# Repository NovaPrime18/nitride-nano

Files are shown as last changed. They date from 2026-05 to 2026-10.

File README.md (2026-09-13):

# nitride-nano

**Pocket-sized GaN buck/boost converter with USB-C PD input**




<table><tr>
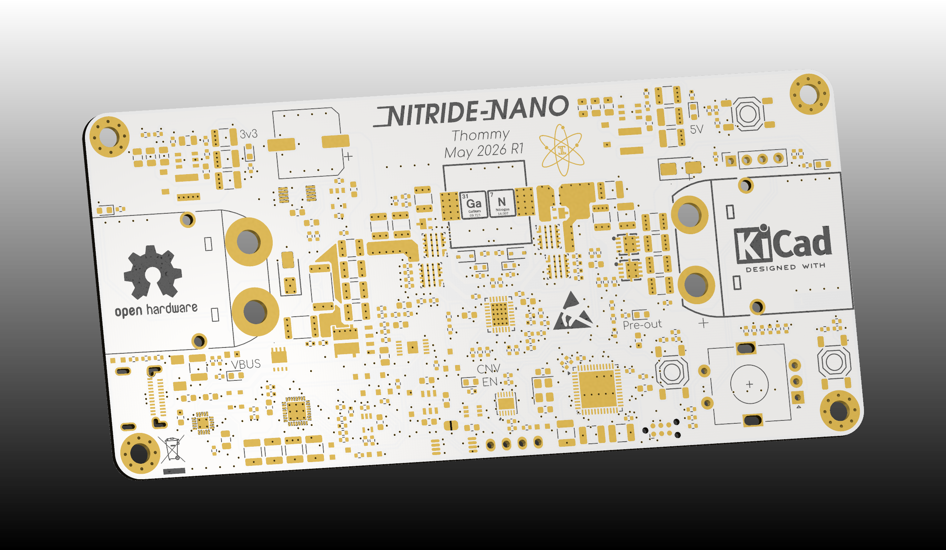
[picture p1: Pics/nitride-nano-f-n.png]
<td></td>
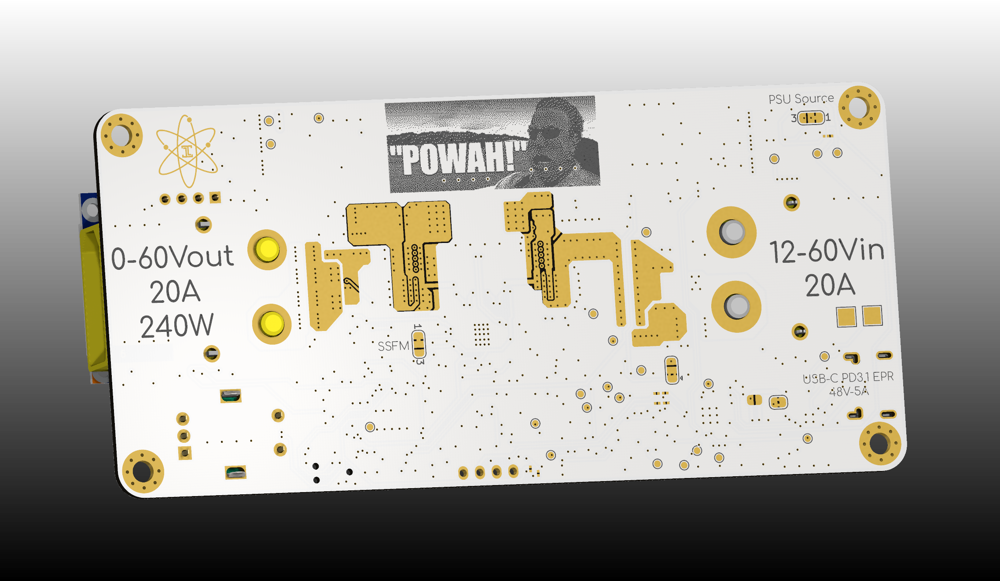
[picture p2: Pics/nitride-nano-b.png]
<td></td>
</tr></table>
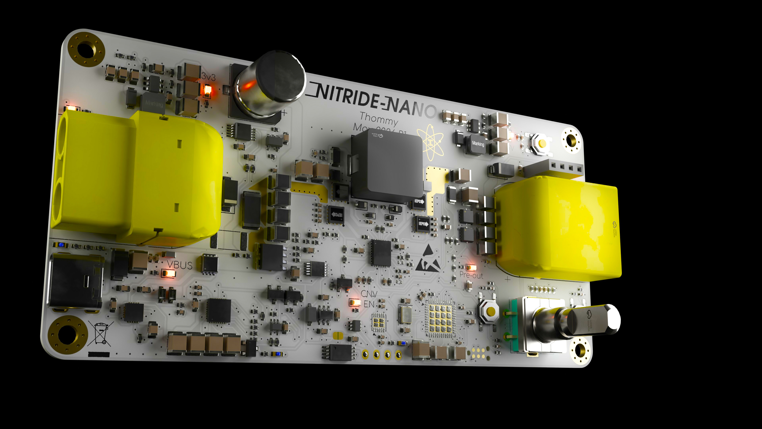
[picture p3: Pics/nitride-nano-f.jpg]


---

## Overview

Nitride-nano is an open-source, high-power-density buck/boost converter crammed into the smallest footprint possible. It targets the same use case as the [Miniware MDP-XP](https://www.miniware.com.cn/product/mdp-xp-digital-power-supply/)  a portable, wide-range programmable power supply. With a focus on **higher power density and a wider voltage range** rather than output ripple performance.

Built around EPC GaN FETs switching at up to 1 MHz and an LT8390A-based controller topology, it accepts either USB-C Power Delivery or high-voltage DC input and delivers up to 240 W from an XT90 output connector.

---

## Specifications

| Parameter | Value |
|---|---|
| Input voltage | 12 – 48 V |
| Output voltage | 0 – 60 V |
| Input / Output current | 20 A (design target, untested) |
| Max output power | 240 W |
| Switching frequency | 1 MHz (Rev 1) / 600 kHz (Rev 2) |
| Topology | Non-inverting buck/boost |
| Input connector | XT90 |
| Output connector | XT90 |

> ⚠️ **20 A / 240 W figures are design targets. Revision 1 testing has verified up to 164 W output (see Testing below) — the full 20 A / 240 W envelope is still unverified.**

---

## USB-C Power Delivery

Nitride-nano negotiates full USB-C PD on the input side:

- **Fixed PDO** — standard 5/9/12/15/20 V profiles
- **PPS** — 5–21 V programmable (50 mV steps)
- **AVS / EPR** — 15–48 V extended power range

---

## Hardware

| Component | Part |
|---|---|
| MCU | STM32G474CEUx |
| Power stage FETs | EPC2367 (eGaN) |
| Controller | LT8390A / EVAL-LT8390A-AZ topology |
| Power monitor | INA228 (I²C, 16-bit) |
| Display | SSD1306 0.96″ OLED |
| UI | 3-button interface |
| Overcurrent protection | Hardware (INA228-triggered) |
| EDA | KiCad |

---

## Firmware

- STM32G474 HAL / bare-metal
- SSD1306 OLED UI with 3-button navigation
- USB-C PD stack (Fixed / PPS / AVS negotiation) over I²C
- **Auto-tracking PD** — derives the input rail from the requested output voltage so the LT8390A stays in a clean buck or boost region instead of its lossier 4-switch band
- INA228 input-bus power monitoring (Vin / Iin / Pin + die temp)
- Hardware overcurrent fault handling, plus firmware input OCP/OVP from the INA228

---

## Thermal Sim
<table><tr>
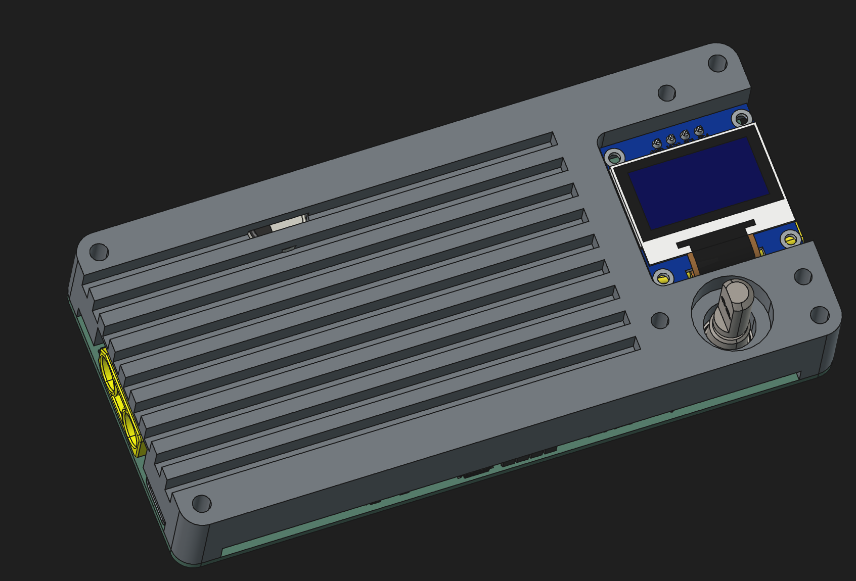
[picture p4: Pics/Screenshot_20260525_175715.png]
<td></td>
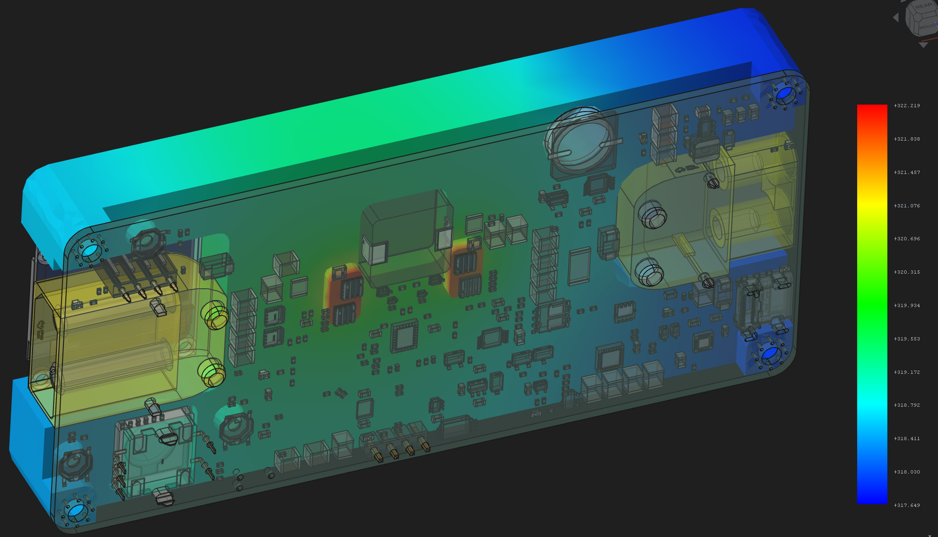
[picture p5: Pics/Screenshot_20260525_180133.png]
<td></td>
</tr></table>

Simulated with Freecad, the enclosure reaches about 38 Degrees C (with a fan) when there's 10W of losses directly going into the heatsink from the GaNFETs. Real world performance is likely better, due to not all 10W leaving the Fets through the top.

---

## Testing — Revision 1 (1 MHz)

Bench results from Revision 1 hardware, measured at the operating points below.

| # | Input | Output | Efficiency |
|---|---|---|---|
| 1 | 25 V, 7 A — 174.2 W in | 36.6 V, 4.48 A — 164 W out | 94.1 % |
| 2 | 40 V, 3.61 A — 144.3 W in | 37.1 V, 3.48 A — 129.1 W out | 89.5 % |
| 3 | 13 V, 9.28 A — 120.6 W in | 36.5 V, 3 A — 109.1 W out | 90.5 % |

**Equipment:** Riden RD6024 bench supply (input) · EA-EL 3160-60 electronic load (output)

**Thermals:** the inductor core ran hottest at ~90 °C — by far the lossiest component on the board. The GaN FETs barely got above 60 °C.

---

## Revision 2 Changes

Reworks to the power stage and the bring-up bugs found on Revision 1:

**Power stage**
- New 2.2 µH inductor (Coilcraft XAL1010-222MED) at 600 kHz switching, chosen for lower core losses — the Rev 1 core was the hottest part by far
- Turn-off diodes in the gate paths: soft turn-on, quick turn-off
  - This prevents Miller turn-on of the output top FET caused by the input bottom FET through the inductor core (annoying issue to debug)
- Flyback diodes on the power FETs: better placement and a different footprint (PMEG6020ETP)
- More output capacitance
- Series resistors in the CV and CC paths so the LT chip doesn't blow up (it happened 3×)
- The LT chip's 5 V rail is now fed from a switching regulator instead of an ultra-lossy LDO at high input voltage

**Control / MCU**
- MCU now measures the pre-output node instead of the output, for better insight into what the LT controller chip is doing
- Reset mechanism around the MCU reworked
- Both I²C busses wired correctly this time
- OLED pinout is now correct

**Connectivity**
- Corrected pinout of the FTDI chip
- Nicer USB-C connector

Firmware developed alongside Rev 2: linearized CV control with ramping, OLED error messages, filtered readings, and a split between the measurement/control and display tasks.

---

## Acknowledgements / Based On

- [**PD240W** by theohg](https://github.com/theohg/PD240W) — USB-C PD input stage reference
- [**EVAL-LT8390A-AZ** by Analog Devices](https://www.analog.com/en/resources/evaluation-hardware-and-software/evaluation-boards-kits/eval-lt8390a-az.html) — buck/boost power stage reference

---

## License

Hardware design files are licensed under the **CERN Open Hardware Licence Version 2 – Strongly Reciprocal (CERN-OHL-S v2.0)**.

See [`LICENSE`](./LICENSE) for the full text, or visit [ohwr.org/cern_ohl_s_v2](https://ohwr.org/cern_ohl_s_v2.txt).

> In short: you are free to use, study, modify, and distribute this design, provided that any derivatives are released under the same licence and source files are made available.

---

## Status

> 🚧 Work in progress — Revision 1 built and power-tested (results above); Revision 2 design complete and ordered.

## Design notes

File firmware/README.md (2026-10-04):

# nitride-nano firmware

Embassy-based Rust firmware for the **STM32G474CEU6** on the nitride-nano pocket buck/boost supply.

## Features

- **CV/CC control** via 12-bit DAC (PA4 CV, PA6 CC) referenced to VREF+ = +3V3 (the on-board tie; the internal VREFBUF is left high-Z); open-loop CV driven as an (inverted) map from setpoint to DAC code, derived analytically from the LT8390A feedback divider (R19/R20/R36), with code-rate slew limiting (no feedback loop)
- **ADC telemetry** on PA0/PA1/PA3/PA7/PA9 (output side)
- **INA228** input power monitor (Vin/Iin/Pin + die temp) on I2C1
- **Auto-tracking PD** — negotiates a fixed input rail from the output setpoint, keeping the LT8390A out of its 4-switch buck-boost region when the requested power allows
- **SSD1306** powersupply UI (128×64 I2C)
- **3 buttons + rotary encoder** (PB9–11, PB6/PA12, PB4)
- **TPS26750** USB-C PD driver (port of `../src/tps26750.cpp`)
- **Protection**: 60 V / 20 A / 240 W / NTC overtemperature / INA228 input OCP-OVP

## Requirements

- Rust stable (`thumbv7em-none-eabihf` target)
- [probe-rs](https://probe.rs/) for flash/debug (SWD on PA13/PA14)

```bash
rustup target add thumbv7em-none-eabihf
```

## Build & flash

```bash
cd firmware
cargo build --release
cargo run --release   # uses probe-rs runner from .cargo/config.toml
```

## Service mode — UART reflash: **known not to work on this silicon/board** (2026-09)

The running firmware *does* hand control to the ST ROM bootloader — the trigger,
the `.uninit` handoff marker, the `SYSRESETREQ` and the jump to `0x1FFF0000` all
work and were each verified on hardware. **The ROM bootloader then returns to the
application almost immediately instead of staying resident, so no host tool ever
gets to sync.** Treat UART reflash as unavailable until the design changes; use
SWD (`cargo run --release`, or `probe-rs download`) to flash.

### What was verified, and how

- **The FT234XD link works.** A `0x7F` on the port is received on USART3,
  accepted by the listener, and the output is parked. The "FTDI enumerates but
  the MCU ignores the port" symptom was a *different* bug (below).
- **The handoff marker works.** `request_on_next_boot()` stores `0xB00710AD` /
  `0x4FF8EF52` in `.uninit`; it survives `sys_reset()`; `take_request()` accepts
  it; and the jump runs with the correct system-memory vectors
  (`0x20002160` / `0x1FFF5049`), confirmed by a trace in otherwise-unused SRAM.
- **The G4 ROM bootloader is present and healthy**, but does not stay. Setting
  the core straight to the ROM entry from a pristine reset
  (`pc = 0x1FFF5049`, `msp = 0x20002160`, then resume) puts the PC back in the
  application within ~100 ms, with the app's own boot banner on the UART. No
  `0x79` ACK is ever produced, at any baud/parity, even while flooding `0x7F`.
  The boot configuration is `nBOOT0=1`, `nSWBOOT0=0` — i.e. "boot from main
  flash" — which is what the loader falls back to. This matches the widely
  reported STM32G4/G0 behaviour that a software jump to the system loader does
  not keep it resident; it is not a firmware defect and no amount of driver
  teardown or interrupt-state fiddling changes it.

### The bug that *was* real (and is fixed)

`defmt-rtt`'s default blocking write froze the single-threaded executor a few
seconds after boot whenever no `probe-rs` reader was draining RTT: the RTT
control block lives in `.uninit`, its "host connected" flag survives resets, so
after any probe session the buffer fills and `blocking_write` spins forever. The
listener was therefore dead by the time a flasher connected — which is exactly
why triggering only ever worked in the first seconds after a power cycle. Fixed
in `Cargo.toml` with `defmt-rtt = { version = "0.4", features =
["disable-blocking-mode"] }`.

### What would make USB-C reflash actually work

1. **Hardware ECO (rev3) — chosen direction.** `BOOT0` must be strapped high at
   reset. On the G4 BOOT0 *is* PB8, which is also `/MCU/I2C0_SCL` (pulled high by
   R32), so the pin has to be freed from the I²C bus and given a strap that is low
   by default and high only while a host is flashing. The full change — I²C
   re-pin, the FT234XD `~RTS` strap circuit, the `nSWBOOT0` option byte, and the
   firmware simplification — is written up in
   [`../PCB/ECO-rev3-boot0.md`](../PCB/ECO-rev3-boot0.md). With it, stock
   `stm32flash` / `STM32CubeProgrammer` work with no host script.
2. **Zero-hardware alternative, works on rev2 today.** The G4 can also take
   BOOT0 from the `nBOOT0` software option bit, so the *firmware* can select the
   loader and reset — no board change. See §7 of the ECO.
3. **In-app updater (fallback).** If neither of the above is wanted, the USART3
   ↔ FT234XD link already works, so the application can implement its own
   erase/write protocol. Safest shape is A/B across the two flash halves so a
   failed transfer can never brick the board.

> **Safety:** a firmware pin cannot hold its state through reset, so anything
> that resets into the ROM loader leaves the converter unregulated. See the
> PA11/Q13 fail-safe ECO in [BENCH.md](BENCH.md) before flashing with a load
> attached.

## Pin map

| Signal | Pin | Notes |
|---|-----|---|
| I2C1 SCL/SDA | PB8 / PB7 | TPS26750 + INA228. **rev2 bodge:** PCB routes this bus to PC4/PB7, but no STM32G474 hardware I²C peripheral can drive PC4+PB7 together, so SCL is wired from PC4 to PB8 (I2C1_SCL). SDA stays on PB7 (I2C1_SDA). |
| I2C3 SCL/SDA | PA8 / PB5 | SSD1306 OLED, and CAT24C512 EEPROM when JP8/JP9 are bridged |
| CV DAC | PA4 | DAC1 CH1, buffered |
| CC DAC | PA6 | DAC2 CH1, buffered |
| Vout sense | PA0 | ADC1 (output side) |
| I sense | PA3 | ADC1 |
| Bus V | PA7 | ADC2 (input-bus fallback; INA228 is primary) |
| NTC conv / in | PA1 / PA9 | ADC |
| Disable | PA11 | GPIO (verify polarity at bring-up) |
| Status LED | PA15 | D31, **active high** (PA15 → anode → R81 → GND); `TIM2_CH1` hardware PWM |
| Buttons | PB9 / PB10 / PB11 | Active low |
| Encoder A/B | PB6 / PA12 | TIM4 QEI |
| Enc button | PB4 | |
| PD IRQ | PB13 | EXTI |
| UART debug / service mode | PC10/PC11 | USART3 → FT234XD. Intended as the ROM-bootloader reflash port — see "Service mode" above, it does **not** work on this board. |

## Status LED (PA15)

`D31` is wired **active high** (`PA15 → anode → R81 → GND`) and driven from
`TIM2_CH1` as hardware PWM, so it can be dimmed precisely and keeps its
brightness even while a blocking I2C timeout stalls the executor. A background
task ([`src/ui/led.rs`](src/ui/led.rs)) plays one of these indications:

* **Heartbeat** — everything fitted is present and no fault is latched: two
  3 %-duty pulses ("thump-thump") roughly every 2 s. Very dim by design; tune
  `LED_HEARTBEAT_DUTY_PCT` in [`src/board.rs`](src/board.rs) to taste.
* **Activity** — an EEPROM write/verify is running: a medium-duty pulse at ~2 Hz.

Otherwise the LED repeats a **blink code**: `N` full-brightness flashes, then a
long dark pause.

| `N` | Meaning | Trigger |
|-----|---|---|
| 1 | OVERCURRENT | `Fault::OverCurrent` |
| 2 | OVERVOLTAGE | `Fault::OverVoltage` |
| 3 | OVERPOWER | `Fault::OverPower` |
| 4 | OVERTEMP | `Fault::OverTemp` |
| 5 | IN OCP | `Fault::InputOverCurrent` |
| 6 | IN OVP | `Fault::InputOverVoltage` |
| 7 | INA228 FAULT | input monitor not answering |
| 8 | PD CTRL LOST | TPS26750 not answering |
| 9 | PD NO RAIL | source caps known, none can serve the request |
| 10 | EEPROM FAULT | last flash attempt failed |

A latched protection fault always wins over the other states. Codes 7–9 are held
back for `LED_SUBSYSTEM_GRACE_MS` after boot (the two chips are probed
asynchronously) and can be disabled entirely with `LED_SUBSYSTEM_CODES` for a
build that does not fit the INA228 or TPS26750. Every change is also logged on
RTT (`LED: OVERCURRENT (code 1)`) so the blink code has a matching message.

## Main screen controls

The Main power screen is the default view and the only place the output setpoint
is edited — there is no separate V-SET screen:

* **BTN1** cycles the selected regulation mode, CV ↔ CC. The header badge shows
  the selection while the output is off and the detected loop while it runs.
* **BTN2** enables/disables the converter. When a protection fault is latched,
  the first press clears the latch and keeps the output off (a deliberate
  two-step recovery); a second press enables.
* **BTN3** moves on to the next screen: Main → I-LIM → PD → CFG → Main.
* **Encoder click** toggles VSET mode. While it is on, the bottom line reads
  `>V-SET` with the voltage setpoint and the header shows the step mode; turning
  the encoder trims `v_set` by 100 mV (Fine) or 1 V (Coarse). Clicking again, or
  leaving with BTN3, exits and restores the fine step. Rotation is inert on the
  bare Main screen so a stray turn cannot move an applied setpoint.
* **Encoder double click** toggles Fine/Coarse while VSET mode is on. The single
  click is deferred by `ENC_DOUBLE_CLICK_MS` (~350 ms) so the two gestures can
  never both fire for one double click.

Setpoint readouts use one fractional digit (`SET 30.0V`); the measurement columns
keep three (`12.000 V`).

## Auto-tracking PD

`PdContract` screen (reached with BTN3 from the `Main`/`I-LIM` cycle, not from
CFG): **BTN1** toggles Auto-tracking on/off, **BTN2** switches the policy
(efficiency-first vs maximum power), the encoder steps presets in manual mode,
and the encoder button confirms/re-evaluates.

The LT8390A leaves its 4-switch buck-boost region only when `VIN/VOUT` clears
~1.35 (clean buck) or ~0.70 (clean boost); near `VIN ≈ VOUT` all four FETs
switch and efficiency drops. Auto-tracking therefore picks the fixed USB-PD rail
that keeps the converter in a clean region, and falls back to the most capable
rail only when the requested `v_set × i_set` power exceeds what the clean rail
can deliver. Lower the current limit to get the efficient rail at high `Vset`.
Guard bands live in [`src/board.rs`](src/board.rs) (`AUTO_TRACK_*`) and should be
tuned from a bench efficiency sweep.

## CFG menu & output V sweep

`CFG` (reached with BTN3 from the `PD` screen) is a fullscreen, scrollable list:
`EEPROM WRITE`, `OUTPUT V SWEEP`. The `PD CONTRACT` screen is deliberately not an
entry here — it already has its own stop in the BTN3 screen cycle. Turn the
encoder to move the highlight, press the encoder (or BTN1) to activate, BTN3 to
go back. The list scrolls with a right-edge scrollbar once more entries are
added.

`OUTPUT V SWEEP` returns to the main screen and waits for an encoder-button
press, then sweeps the output setpoint through 32 points from 10 V to 56 V at
2 s per point (≈64 s) in CV mode. The bottom line shows `>SWEEP` plus the
confirm prompt, the point/percent progress, or `DONE`, replacing the usual
`MAIN` tag and the `NO PD`/`Iin` field for the whole run. Any button press
aborts and parks the output, and the sweep also parks itself on completion or a
latched fault. Auto-tracking PD holds its rail for the duration of the sweep.
Range, point count and dwell live in [`src/board.rs`](src/board.rs)
(`SWEEP_*`); the map reaches all 32 points, including the final 56 V one.

### Sweep efficiency diagnostics

Each point also logs a filtered input-to-output efficiency to the defmt console
(`DEFMT_LOG=info cargo run --release`):

```text
sweep point 7/32: vset=19839 vout=19810 iout=2100 vin=20000 pin_avg=44400 pout_avg=41800 eta=94.1% n=60
...
sweep summary (complete): 32 points, 30 valid
  max eta=94.1% at point 7 (19839 mV)
  min eta=88.3% at point 31 (54258 mV)
```

The report is `η = mean(pout) / mean(pin)`: both powers are integrated over the
settled part of each 2 s dwell (`SWEEP_SETTLE_MS` / `SWEEP_SAMPLE_MS` in
[`src/board.rs`](src/board.rs)) and divided once, rather than ratioing a single
noisy sample, so the board's ADC/INA228 jitter does not swamp the result. A point
with too few accepted samples, or a reading above 100 % (measurement error), is
logged with `excluded` and left out of the summary; if the INA228 is absent or
the output is too lightly loaded, every point prints `eta=--` and the summary
warns instead of recording a bogus maximum. Aborting a run early still prints the
summary for the points already measured.

## Bring-up

See [BENCH.md](BENCH.md) for the step-by-step validation checklist.

## Tuning

Edit scaling constants and NTC parameters in [`src/board.rs`](src/board.rs) after measuring divider networks on the assembled board. The INA228 is configured for an 8 mΩ shunt (R60), `ADCRANGE = 0` and 20 A full scale (`INA228_*`).

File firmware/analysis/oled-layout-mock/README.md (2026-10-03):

# OLED main-screen layout mock

Design/verification aid for the 128×64 SSD1306 power screen. Not part of the
firmware build.

- `font.py` — parses the real 5×7 glyph table out of
  `src/drivers/ssd1306.rs` and re-implements the framebuffer primitives, so a
  render here matches the panel bit-for-bit.
- `candidates.py` — renders the layouts that were considered (A is the one
  implemented in `src/drivers/ssd1306_ui.rs`). `main_screen.png` is the
  implemented layout at low load, 240 W, and with no PD source;
  `comparison.png` shows the alternatives.
- `verify_geometry.py` — reads the layout constants straight out of
  `src/drivers/ssd1306_ui.rs` and asserts the geometry invariants (rows do not
  overlap, no column can be overrun by its widest value, bars stay on-panel)
  plus that the shipped constants still match the rendered mock.

```
python3 verify_geometry.py     # geometry invariants against the Rust source
python3 candidates.py A        # ASCII dump of the implemented layout
```

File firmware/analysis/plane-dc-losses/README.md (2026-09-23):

# Plane DC I²R loss — nitride-nano buck/boost power pours

Answers: **how much power does the PCB copper itself burn in DC resistance on the
buck/boost power path, on a 2 oz / 6-layer board?**

Plane copper only. Component resistance (FET R<sub>ds(on)</sub>, the 2 mΩ shunts,
the 8 mΩ input shunt, inductor DCR, ferrites, fuse) is deliberately excluded —
this measures the board, not the parts.

## Result

Total DC copper loss in the power pours, at 2 oz / 20 °C:

| Operating point | Plane copper loss |
|---|---|
| 48→5 V, 20 A | 551 mW |
| 20→5 V, 20 A | **566 mW** (worst) |
| 48→18 V, 18 A | 476 mW |
| 48→14.5 V, 14.5 A | 302 mW |
| 12→48 V, 5 A | 564 mW |
| 20→48 V, 5 A | 216 mW |
| 24→60 V, 4 A | 149 mW |
| 4-switch 24→24 V, 10 A | 387 mW |
| USB-C 48→24 V, 5 A | 49 mW |

So the board's own copper costs **~0.05–0.57 W**, which is **~3 %** of the
recorded FET loss (9.61 W at 48→14.5 V/14.5 A in `PCB/losses.txt`). It is not the
dominant loss, but it is not negligible either.

Where it goes:

- Worst net is **`Net-(D3-K)`** (power-stage output): 0.40 mΩ → 161 mW at 20 A,
  two thirds of it on `F.Cu` alone.
- The switching-node pours `D1-A`, `L1-Pad1`, `D2-A` are next (0.18–0.22 mΩ each,
  ~72–90 mW at 20 A).
- **Vias carry 15–25 %** of the loss on those nets — the pours are stitched, but
  the barrels are the narrowest part of the current path.
- `+VBUS` (USB-C input) is a **single-layer** pour: 1.56 mΩ, ~100× the XT90 input
  rail. Fine at 5 A (39 mW) but it is the one rail with real DC drop.
- GND return: 0.230 mΩ input side, 0.176 mΩ output side (~71 mW + 69 mW at 20 A).

## Quick start

```bash
# from this directory
.venv/bin/python plane_dc_loss.py --list-nets          # copper area per net per layer
.venv/bin/python plane_dc_loss.py                      # full run: report.md + maps
.venv/bin/python plane_dc_loss.py --nets "Net-(D3-K)" --pitch 0.05
.venv/bin/python plane_dc_loss.py --converge "Net-(L1-Pad1)"   # mesh convergence study
.venv/bin/python gerber_area_check.py                  # independent geometry check
```

The venv is `python3 -m venv --system-site-packages` plus `scipy`, so the system
`pcbnew`, `numpy` and `shapely` stay visible.

By default the tool materialises git revision **`d705578` ("Rev2 ordered")** — the
revision that was fabricated — via `git show`, writes it to a temp file and
analyses that. Use `--no-git-rev --board <path>` to analyse a working tree instead.

## Files

| File | What |
|---|---|
| `plane_dc_loss.py` | the analysis tool (extraction → mesh → solve → report) |
| `gerber_area_check.py` | independent check: parse the fab Gerbers, compare copper area |
| `report.md` | generated results |
| `results.json` | machine-readable R<sub>eff</sub> and per-layer/per-type breakdown |
| `maps/*.svg` | per-net per-layer current-density maps (log scale) |

## Method

For each net:

1. **Extract** every copper item of that net — filled zone polygons (holes
   preserved), track segments, arcs, pad copper, via pads — into shapely
   geometry, per layer.
2. **Rasterise** onto a uniform grid (default 0.05 mm, 3×3 subcell coverage so
   partially-covered edge cells get a fractional conductance).
3. **Build a resistor network**:
   - in-plane: `g = (1/Rs)·min(cov_i, cov_j)` between adjacent cells,
     `Rs = ρ(T)/t`;
   - out-of-plane: each via is a barrel resistor coupling **every copper layer
     along its barrel**, including layers where this net has no pour (skipping
     those silently splits a net in two and gives garbage);
   - terminals: each terminal group is shorted to a bus node with a stiff
     conductance.
4. **Reduce to the connected component(s) touching the terminals** and report
   anything else as floating copper (it carries no current).
5. **Solve** `L·V = I` for a 1 A injection between the terminal buses — sparse
   direct solve (SuperLU) for ≤350 k nodes, CG above that.
6. **Loss** `P = Σ g·ΔV²`, cross-checked against `P = I·ΔV`. Because the network
   is linear, every operating point is then just `P = I²R`.

Thermal-relief spokes, clearances and antipads need no separate model: they are
already in the filled polygons that KiCad stores, so the mesh sees the real
constrictions at the pads.

## Constants and assumptions

| Item | Value | Where to change |
|---|---|---|
| Copper thickness | 70 µm (2 oz) on all 6 layers | `--thickness` (µm) |
| Copper resistivity | 1.72e-8 Ω·m at 20 °C, +0.393 %/°C | `RHO20`, `ALPHA_CU` |
| Temperature | 20 °C | `--temp` |
| Via | 0.6/0.3 mm, 25 µm barrel plating | `VIA_DRILL`, `VIA_PLATING` |
| Board thickness | 1.6 mm | `BOARD_THICKNESS` |
| Efficiency | η = 0.95 | per scenario, `SCENARIOS` |
| Grid | 0.05 mm × 3×3 subcell; GND ×2.5 coarser | `--pitch`, `--subcell` |

Inductor current is `IL = Iout` in clean buck, `IL = Iin` in clean boost, and
`Iin = Vout·Iout/(Vin·η)`. In the 4-switch transition band `IL` can approach
`2·Iout`; scenario S8 models that as the worst case.

**Note:** the `.kicad_pro` stackup still says 0.035 mm (1 oz) on every layer while
the board was ordered at 2 oz. This tool uses 2 oz. Re-run with
`--thickness 35` to see the 1 oz numbers.

## Nets in scope

`VPP` (XT90 input), `+VBUS` (USB-C input), `/Power-Sense/+VBUS_SENSED`,
`/Converter/PWR_UNREG_IN`, `Net-(U1-VIN)`, `Net-(D1-A)` (SW1), `Net-(L1-Pad1)`
(across the 2 mΩ shunt), `Net-(D2-A)` (SW2), `Net-(D3-K)` (power-stage output),
`Net-(D20-A)`, `Net-(FB5-Pad1)`, `/Converter/PWR_REG_OUT`, and `GND`.

`VPP` only conducts on the XT90 path, `+VBUS` only on the USB-C path; the report
applies the right one per scenario.

Excluded: the logic rails (`+3V3` etc.), AC/skin/proximity effects at 1 MHz, and
component internal resistance.

## Validation

| Check | Result |
|---|---|
| Mesh convergence, `Net-(L1-Pad1)` | R stable within ±1 % from 0.2 mm to 0.05 mm |
| Mesh convergence, `GND` | Iin 0.2235→0.2298 mΩ, Iout 0.1736→0.1758 mΩ from 0.25→0.125 mm (<1 %) |
| Energy balance `Σg·ΔV²` vs `I·ΔV` | exact to solver tolerance on every net |
| Bar-model sanity `Rs·ℓ²/A` | FEM is 1–4.3× the naive bar model, as expected for constricted pours |
| Independent Gerber area check | all 6 layers agree with the fab Gerbers within 0.5–2.7 % |

`gerber_area_check.py` parses the production Gerbers with its own RS-274X reader
(regions, aperture macros incl. KiCad `FreePoly` outline/rotation, arcs) and
compares against pcbnew's copper area — a completely separate code path from the
extraction used by the loss tool.

## Limitations

- DC only. The switch-node pours (`D1-A`, `D2-A`, `D3-K`) physically carry a
  pulsating current; using the average current understates their true ohmic loss.
  An AC/RMS pass would be the next step.
- The copper thickness is taken as uniform at the ordered 2 oz; outer layers in
  production are typically 2 oz + plating, so outer-layer loss is slightly
  pessimistic here.
- GND is a board-wide plane modelled with converter terminals only; unrelated
  logic return currents are not injected.

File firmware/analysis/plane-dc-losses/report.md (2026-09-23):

# Plane DC I²R loss — nitride-nano buck/boost power pours

- Board: `d705578:PCB/nitride-nano.kicad_pcb`
- Copper: 70 µm on all 6 layers (2 oz), ρ = 1.72e-08 Ω·m at 20 °C, T = 20 °C
- Sheet resistance Rs = 0.2457 mΩ/square
- Grid pitch: 0.050 mm base × 3×3 subcell coverage; GND at ×2.5

Method: every copper item of a net (zone fills, tracks, pads, via pads) is rasterised, made into a sheet-resistance network with via barrels coupling the layers, and solved for a 1 A injection between terminal buses; P = Σ g·ΔV².  Nets are linear, so each operating point is P = I²R.
Excluded: component resistance (FETs, shunts, inductor, ferrites, fuse), AC/skin effects, and the logic rails.

## Effective resistance per net (I = 1 A solve)

| Net | layer area (mm²) | nodes | vias | floating (mm²) | case | R_eff (mΩ) | solved |
|---|---|---|---|---|---|---|---|
| `VPP` | 594.1 | 239999 | 10 | 0.00 | Iin | 0.0400 | direct |
| `+VBUS` | 94.0 | 38296 | 3 | 0.00 | Iin | 1.5603 | direct |
| `/Power-Sense/+VBUS_SENSED` | 246.7 | 100485 | 14 | 0.00 | Iin | 0.0479 | direct |
| `/Converter/PWR_UNREG_IN` | 249.8 | 101631 | 15 | 0.00 | Iin | 0.0663 | direct |
| `Net-(U1-VIN)` | 448.4 | 182891 | 38 | 0.00 | Iin | 0.2458 | direct |
| `Net-(D1-A)` | 147.0 | 60448 | 27 | 0.00 | IL | 0.2245 | direct |
| `Net-(L1-Pad1)` | 254.9 | 103248 | 33 | 0.00 | IL | 0.1962 | direct |
| `Net-(D2-A)` | 359.2 | 145341 | 59 | 0.00 | IL | 0.1797 | direct |
| `Net-(D3-K)` | 317.8 | 128836 | 28 | 0.00 | Iout | 0.4018 | direct |
| `Net-(D20-A)` | 155.5 | 63963 | 12 | 0.00 | Iout | 0.1489 | direct |
| `Net-(FB5-Pad1)` | 286.5 | 115850 | 28 | 0.00 | Iout | 0.0189 | direct |
| `/Converter/PWR_REG_OUT` | 458.2 | 184630 | 16 | 0.00 | Iout | 0.0246 | direct |
| `GND` | 25501.9 | 1666439 | 326 | 164.17 | Iin | 0.2298 | cg |
| `GND` | 25501.9 | 1666439 | 326 | 164.17 | Iout | 0.1758 | cg |

## Loss per operating point

| Scenario | Vin→Vout | Iout | Iin | IL | `VPP` | `+VBUS` | `/Power-Sense/+VBUS_SENSED` | `/Converter/PWR_UNREG_IN` | `Net-(U1-VIN)` | `Net-(D1-A)` | `Net-(L1-Pad1)` | `Net-(D2-A)` | `Net-(D3-K)` | `Net-(D20-A)` | `Net-(FB5-Pad1)` | `/Converter/PWR_REG_OUT` | `GND` | total |
|---|---|---|---|---|---|---|---|---|---|---|---|---|---|---|---|---|---|---|
| S1 buck 48->5V 20A | 48→5.0 V | 20.0 A | 2.19 A | 20.00 A | 0.2 | 0.0 | 0.2 | 0.3 | 1.2 | 89.8 | 78.5 | 71.9 | 160.7 | 59.5 | 7.6 | 9.8 | 71.4 | **0.551 W** |
| S2 buck 20->5V 20A | 20→5.0 V | 20.0 A | 5.26 A | 20.00 A | 1.1 | 0.0 | 1.3 | 1.8 | 6.8 | 89.8 | 78.5 | 71.9 | 160.7 | 59.5 | 7.6 | 9.8 | 76.7 | **0.566 W** |
| S3 buck 48->18V 18A | 48→18.0 V | 18.0 A | 7.11 A | 18.00 A | 2.0 | 0.0 | 2.4 | 3.3 | 12.4 | 72.8 | 63.6 | 58.2 | 130.2 | 48.2 | 6.1 | 8.0 | 68.6 | **0.476 W** |
| S4 buck 48->14.5V 14.5A | 48→14.5 V | 14.5 A | 4.61 A | 14.50 A | 0.8 | 0.0 | 1.0 | 1.4 | 5.2 | 47.2 | 41.2 | 37.8 | 84.5 | 31.3 | 4.0 | 5.2 | 41.9 | **0.302 W** |
| S5 boost 12->48V 5A | 12→48.0 V | 5.0 A | 21.05 A | 21.05 A | 17.7 | 0.0 | 21.2 | 29.4 | 108.9 | 99.5 | 86.9 | 79.7 | 10.0 | 3.7 | 0.5 | 0.6 | 106.3 | **0.564 W** |
| S6 boost 20->48V 5A | 20→48.0 V | 5.0 A | 12.63 A | 12.63 A | 6.4 | 0.0 | 7.6 | 10.6 | 39.2 | 35.8 | 31.3 | 28.7 | 10.0 | 3.7 | 0.5 | 0.6 | 41.1 | **0.216 W** |
| S7 boost 24->60V 4A | 24→60.0 V | 4.0 A | 10.53 A | 10.53 A | 4.4 | 0.0 | 5.3 | 7.3 | 27.2 | 24.9 | 21.7 | 19.9 | 6.4 | 2.4 | 0.3 | 0.4 | 28.3 | **0.149 W** |
| S8 4-switch 24->24V 10A | 24→24.0 V | 10.0 A | 10.53 A | 20.00 A | 4.4 | 0.0 | 5.3 | 7.3 | 27.2 | 89.8 | 78.5 | 71.9 | 40.2 | 14.9 | 1.9 | 2.5 | 43.0 | **0.387 W** |
| S9 USB-C 48->24V 5A | 48→24.0 V | 5.0 A | 2.63 A | 5.00 A | 0.0 | 10.8 | 0.3 | 0.5 | 1.7 | 5.6 | 4.9 | 4.5 | 10.0 | 3.7 | 0.5 | 0.6 | 6.0 | **0.049 W** |

_All loss figures are milliwatts except the total, which is watts._
VPP only conducts on the XT90 input path and +VBUS only on the USB-C path.

## Breakdown by layer and copper type — S2 buck 20->5V 20A

Loss in mW at that operating point's own current through each net.

| Net | I (A) | F.Cu | In1.Cu | In2.Cu | In3.Cu | In4.Cu | B.Cu | via | zone | track+pad | total |
|---|---|---|---|---|---|---|---|---|---|---|
| `VPP` | 5.26 | 0.72 | 0.10 | 0.03 | 0.01 | 0.00 | 0.00 | 0.25 | 0.86 | 0.00 | **1.11** |
| `+VBUS` | — (not on this input path) | 0.00 | 0.00 | 0.00 | 0.00 | 0.00 | 0.00 | 0.00 | 0.00 | 0.00 | **0.00** |
| `/Power-Sense/+VBUS_SENSED` | 5.26 | 1.00 | 0.08 | 0.02 | 0.01 | 0.00 | 0.00 | 0.22 | 1.11 | 0.00 | **1.32** |
| `/Converter/PWR_UNREG_IN` | 5.26 | 1.28 | 0.18 | 0.00 | 0.03 | 0.01 | 0.01 | 0.33 | 1.50 | 0.00 | **1.83** |
| `Net-(U1-VIN)` | 5.26 | 2.30 | 1.23 | 0.00 | 0.77 | 0.67 | 0.62 | 1.20 | 5.60 | 0.01 | **6.81** |
| `Net-(D1-A)` | 20.00 | 36.01 | 15.90 | 0.00 | 6.24 | 4.46 | 3.77 | 23.40 | 66.22 | 0.16 | **89.77** |
| `Net-(L1-Pad1)` | 20.00 | 38.05 | 12.27 | 0.00 | 4.00 | 2.44 | 1.85 | 19.82 | 58.61 | 0.00 | **78.43** |
| `Net-(D2-A)` | 20.00 | 32.27 | 0.00 | 0.00 | 9.99 | 8.28 | 7.59 | 13.75 | 58.13 | 0.00 | **71.88** |
| `Net-(D3-K)` | 20.00 | 67.14 | 0.00 | 0.00 | 23.65 | 19.77 | 19.47 | 30.68 | 129.80 | 0.23 | **160.70** |
| `Net-(D20-A)` | 20.00 | 50.33 | 3.12 | 0.00 | 0.79 | 0.48 | 0.02 | 4.78 | 54.75 | 0.00 | **59.53** |
| `Net-(FB5-Pad1)` | 20.00 | 5.81 | 0.57 | 0.00 | 0.10 | 0.04 | 0.02 | 1.03 | 6.55 | 0.00 | **7.57** |
| `/Converter/PWR_REG_OUT` | 20.00 | 5.69 | 1.27 | 0.00 | 0.38 | 0.26 | 0.22 | 2.00 | 7.82 | 0.00 | **9.82** |
| `GND` | 5.26/20.00 | 16.95 | 13.29 | 59.77 | 19.45 | 17.86 | 12.10 | 34.02 | 138.40 | 1.01 | **173.44** |

## Headline

| Scenario | plane copper loss | recorded FET loss | plane as % of FET |
|---|---|---|---|
| S1 buck 48->5V 20A | **551 mW** | — | — |
| S2 buck 20->5V 20A | **566 mW** | — | — |
| S3 buck 48->18V 18A | **476 mW** | 8.91 W | 5.3 % |
| S4 buck 48->14.5V 14.5A | **302 mW** | 9.61 W | 3.1 % |
| S5 boost 12->48V 5A | **564 mW** | — | — |
| S6 boost 20->48V 5A | **216 mW** | — | — |
| S7 boost 24->60V 4A | **149 mW** | — | — |
| S8 4-switch 24->24V 10A | **387 mW** | — | — |
| S9 USB-C 48->24V 5A | **49 mW** | — | — |

Highest plane loss: **566 mW** at S2 buck 20->5V 20A; lowest 49 mW. Copper-only: excludes R9/R18 (2 mΩ), R60 (8 mΩ), FET Rds(on), inductor DCR, ferrite and fuse resistance.

## Validation

| Net | R_eff (mΩ) | bar model (mΩ) | ratio | energy check |
|---|---|---|---|---|
| `VPP` | 0.0400 | 0.0094 | 4.25 | ok |
| `+VBUS` | 1.5603 | 0.8059 | 1.94 | ok |
| `/Power-Sense/+VBUS_SENSED` | 0.0479 | 0.0171 | 2.79 | ok |
| `/Converter/PWR_UNREG_IN` | 0.0663 | 0.0193 | 3.43 | ok |
| `Net-(U1-VIN)` | 0.2458 | 0.0574 | 4.28 | ok |
| `Net-(D1-A)` | 0.2245 | 0.1174 | 1.91 | ok |
| `Net-(L1-Pad1)` | 0.1962 | 0.0700 | 2.80 | ok |
| `Net-(D2-A)` | 0.1797 | 0.0803 | 2.24 | ok |
| `Net-(D3-K)` | 0.4018 | 0.0953 | 4.22 | ok |
| `Net-(D20-A)` | 0.1489 | 0.0421 | 3.53 | ok |
| `Net-(FB5-Pad1)` | 0.0189 | 0.0064 | 2.96 | ok |
| `/Converter/PWR_REG_OUT` | 0.0246 | 0.0243 | 1.01 | ok |
| `GND` | 0.2298 | — | — | ok |

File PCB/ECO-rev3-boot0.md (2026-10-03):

# ECO — rev3: make UART reflash over the FT234XD actually work (BOOT0)

Status: **proposed**, for rev3. Supersedes the "software jump to the ROM loader"
scheme that rev2 shipped with (see `firmware/README.md` → "Service mode").

## 1. Why the rev2 scheme cannot work

Measured on the rev2 board, September 2026:

- The FT234XD ↔ USART3 link is good: `0x7F` arrives on PC11, the listener fires,
  the output is parked.
- The `.uninit` request marker is good: it survives `sys_reset()`,
  `take_request()` accepts it, and `jump_to_system_bootloader()` runs with the
  correct system-memory vectors (`0x20002160` / `0x1FFF5049`).
- **The ROM loader then returns to the application within ~100 ms.** Setting the
  core directly to the loader entry (`pc = 0x1FFF5049`, `msp = 0x20002160`) from
  a pristine reset reproduces it, so it is not the application's fault. No `0x79`
  ACK is ever produced, at any baud or parity, even while flooding `0x7F`.

The loader leaves because **BOOT0 is low at the reset sampling instant**. On the
STM32G4 BOOT0 is not a dedicated pin — it *is* PB8 (U2 pin 46). A software jump
runs the loader's code but the boot configuration still says "boot from main
flash", and the loader acts on that. Only a hardware strap at reset makes it
stay.

Two option-byte facts make this worse (RM0440 §4.4.1, FLASH_OPTR):

- `nSWBOOT0 = 0` on this part (`FLASH_OPTR = 0xFBEFF8AA`), i.e. BOOT0 is taken
  from the **software bit `nBOOT0`**, and the PB8 pin is ignored entirely. The
  ST factory value is `0xFFEFF8AA`, where BOOT0 comes from the pin.
- Selecting the pin as shipped would be worse, not better: PB8 is
  `/MCU/I2C0_SCL` and **R32 (4.7 kΩ) pulls it to +3V3**, so the pin is high at
  every reset — the board would boot the loader every time.

**Therefore rev3 must (a) free PB8 from the I²C bus, and (b) give it a strap that
is low by default and high only while a host is flashing.**

## 2. Change 1 — re-pin the two I²C buses so PB8 is free

Both buses keep their pull-ups and their net names; only the MCU pins move.

| bus | rev2 | rev3 | note |
|---|---|---|---|
| PD bus — INA228 (U9), TPS26750 (U4) | **I2C1**: PB8 = SCL, PB7 = SDA | **I2C2**: **PC4 = SCL**, **PA8 = SDA** | PC4 is the only SCL-capable free pin |
| OLED (J5, SSD1306) | **I2C3**: PA8 = SCL, PB5 = SDA | **I2C4**: **PC6 = SCL**, PB7 = SDA | frees PA8 for the PD bus |

Pin deltas: **PC4 and PC6 become used; PB8 is freed (→ BOOT0); PB5 is freed.**
All four alternate functions are valid on the STM32G474CEU (AF4 for I2C2, AF8/AF3
for I2C4), and the metapac confirms I2C2/I2C4 exist with `I2C2_EV/ER`,
`I2C4_EV/ER` interrupts. PF0/PF1 are not candidates — they carry the 8 MHz HSE
(`Y1` + C75/C76).

Keeping the same two buses (rather than merging them) preserves the firmware's
PD/UI bus separation and lock order.

## 3. Change 2 — BOOT0 strap and host control

Add at U2 pin 46 (PB8/BOOT0):

- `R_PU` **100 kΩ** from BOOT0 to **+3V3**
- `Q1` N-channel MOSFET (BSS138 / 2N7002): drain → BOOT0, source → GND,
  gate ← `R_g` **10 kΩ** ← **U12 pin 8 (~RTS)**
- `R_gs` **100 kΩ** from the gate to **+3V3**
- A test pad and a 2-pin solder jumper (`JP`) to +3V3, for a manual force/recovery

| host port | U12 pin 8 (~RTS) | Q1 | BOOT0 at reset | result |
|---|---|---|---|---|
| closed | HIGH (FTDI idle) | on | **LOW** | boots the application |
| open (flashing) | LOW (asserted by `open()`) | off | **HIGH** | ROM loader, stays |
| FTDI absent/unpowered | pulled high by `R_gs` | on | **LOW** | boots the application |

Notes:

- The FT234XD has **no DTR**; `~RTS` (pin 8) is the only host-controlled output
  that a plain `open()` toggles. `~CTS` (pin 11) is an input and `CBUS0`
  (pin 6) currently drives the D30 activity LED through R58.
- The polarity is deliberate: `open()` asserts RTS, which drives the pin low,
  which turns Q1 off, which lets BOOT0 rise. So *opening the port is what arms
  the loader* and closing it restores normal boot — with no host-side script
  required, so stock `stm32flash` works.

## 4. Change 3 — option byte

Set **`nSWBOOT0 = 1`** (FLASH_OPTR bit 26), i.e. `0xFBEFF8AA → 0xFFEFF8AA`,
so BOOT0 follows the PB8 pin. Keep `nBOOT1 = 1` so BOOT0-high selects system
memory. Program once per board (STM32CubeProgrammer → Option Bytes, or via SWD).
**Verify on the bench**: with PB8 forced high the device must enter the loader on
reset and stay there.

## 5. Firmware delta

- **Delete the handoff machinery.** With BOOT0 strapped high, `SCB::sys_reset()`
  lands in the ROM loader on its own; the `.uninit` marker, `take_request()`,
  `take_request_diag()`, `JUMP_*` and `jump_to_system_bootloader()` become dead
  code. The service trigger reduces to: park the output → `sys_reset()`.
- **Keep** the USART3 `0x7F` listener — it is the trigger. Keep the BTN1 path,
  but note it now only reaches the loader while the host port is open.
- **I²C re-pin**: `I2C1 → I2C2` (PD bus, PC4/PA8) and `I2C3 → I2C4` (OLED,
  PC6/PB7); update `bind_interrupts!`, the `I2c::new` instances/pin refs, and
  `runtime.rs`'s bus mutexes. No timing change.
- Retire the misleading `romsp`/`rompc` boot-diagnostic fields (they display
  unrelated values and caused a long false trail).

## 6. Optional — host-driven reset for recovery

If the application is corrupt, the loader is still reachable: the port being open
holds BOOT0 high, so a power cycle lands in the loader. For a *scripted* reset,
wire **CBUS0** (U12 pin 6, today the D30 LED) to NRST through a small
N-MOSFET, configure CBUS0 as a GPIO in the FTDI EEPROM, and pulse it from a host
script. Stock `stm32flash` cannot drive CBUS0, so this is a recovery aid only.

## 7. Zero-hardware alternative — works on rev2 today

The `nBOOT0` software bit can also select the loader, so this needs no board
change and is worth validating while rev3 is laid out:

1. On the trigger, the app programs FLASH_OPTR so that software BOOT0 selects
   **system memory**, then launches the option-byte reload (`OBL_LAUNCH`).
2. The chip resets, samples the option bit, and enters the ROM loader — properly,
   so it **stays**, and `stm32flash` can sync.
3. The freshly flashed image restores the flash-boot option bit on its first boot.

Costs: option-byte erase cycles on every flash, and if power is lost between
steps 1 and 3 the board boots the loader on power-up (recoverable by flashing
over UART, i.e. not a brick). This is the same mechanism the shared-PB8 problem
is normally solved with, and it is the fastest way to a working USB-C reflash.

## 8. Bench validation for rev3

1. Option bytes read back as `FLASH_OPTR = 0xFFEFF8AA`.
2. Port closed, power cycle → application runs (OLED up). PB8 measures ~0 V.
3. `stm32flash -b 115200 /dev/ttyUSB0` with no arguments → syncs and prints the
   bootloader version and `Device ID: 0x468`.
4. Full write: `stm32flash -b 115200 -w firmware.bin -v -g 0x08000000 /dev/ttyUSB0`
   completes; the `Go` command returns to the application.
5. Close the terminal/port, power cycle → application still runs.
6. Unplug the FT234XD entirely, power cycle → application runs (Q1 held on by
   `R_gs`).

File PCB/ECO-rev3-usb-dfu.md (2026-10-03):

# ECO — rev3: firmware update over USB-C with the STM32 ROM USB DFU bootloader

Status: **schematic reviewed**. One required correction (PB6 → PC6), plus several
out-of-scope edits to confirm. Firmware port is fully specified in §6 and can be
applied from this document alone.

Supersedes the UART/FT234XD flashing scheme in
[`ECO-rev3-boot0.md`](ECO-rev3-boot0.md). That document's BOOT0 analysis still
holds; its `~RTS`/N-FET strap and the I²C re-pin table are replaced by §4 and §2
here.

---

## 1. Decision

Flash over USB-C using the **STM32G474's built-in ROM USB DFU bootloader** on
**PA11 (`USB_DM`) / PA12 (`USB_DP`)**.

- No bridge chip, no custom bootloader, no host script.
- `dfu-util` or STM32CubeProgrammer work out of the box.
- The **FT234XD (U12) is removed**, along with the whole USART3 service-mode path.
- Entry is a hardware strap: **BOOT0 (PB8) button to +3V3**, `NRST` button.
- SWD (J4) remains the always-works fallback.
- Two isolated I²C buses are preserved: **PD bus = I2C2 (PC4/PA8)**,
  **OLED + EEPROM bus = I2C4 (PC6/PB7)**.
- The quadrature encoder moves to **TIM3 QEI on PB4/PB5** — same X4 hardware
  decoding, same firmware driver, different timer.

Why PA11/PA12 are forced: on the STM32G474 `USB_DM`/`USB_DP` exist on **no other
pins**. PA11 was the converter-disable output and PA12 was encoder B, so both
had to move.

---

## 2. Verified pin map

Every row was checked against the STM32G474CEU symbol in `MCU.kicad_sch` **and**
the HAL pin-trait table generated by `embassy-stm32` for `stm32g474ce`, and then
proven by compile test (§10).

| Signal | rev2 | **rev3** | Peripheral / AF | HAL trait evidence |
|---|---|---|---|---|
| `USB_DM` | — | **PA11** | USB device, AF0 | `usb::DmPin, USB, PA11` |
| `USB_DP` | — | **PA12** | USB device, AF0 | `usb::DpPin, USB, PA12` |
| BOOT0 strap | — | **PB8** | BOOT0 (nSWBOOT0=1) | — |
| Converter disable | PA11 | **PB1** | GPIO out → R78 10 Ω → Q13 gate | GPIO, no AF needed |
| Encoder A | PB6 (`TIM4_CH1`) | **PB4** | `TIM3_CH1`, AF2 | `TimerPin<Ch1>, TIM3, PB4, 2` |
| Encoder B | PA12 (`TIM4_CH2`) | **PB5** | `TIM3_CH2`, AF2 | `TimerPin<Ch2>, TIM3, PB5, 2` |
| Encoder button | PB4 | **PB0** | GPIO in, pull-up | GPIO |
| PD bus SCL | PB8 (rev2 bodge) | **PC4** | `I2C2_SCL`, AF4 | `SclPin, I2C2, PC4, 4` |
| PD bus SDA | PB7 | **PA8** | `I2C2_SDA`, AF4 | `SdaPin, I2C2, PA8, 4` |
| OLED + EEPROM SCL | PA8 | **PC6** | `I2C4_SCL`, AF8 | `SclPin, I2C4, PC6, 8` |
| OLED + EEPROM SDA | PB5 | **PB7** | `I2C4_SDA`, AF3 | `SdaPin, I2C4, PB7, 3` |
| Status LED | PA15 / `TIM2_CH1` | unchanged | — | `PwmPin, TIM2` |
| Time driver | TIM15 | unchanged | — | — |
| USART3 / FT234XD | PC10/PC11 | **removed** | — | PC10/PC11 now free |

**TIM3 is QEI-capable.** `embassy_stm32::timer::qei::Qei` requires
`T: GeneralInstance4Channel`; TIM3 is a general-purpose 16-bit 4-channel timer,
exactly like the TIM4 it replaces. Proof by compilation in §10.

**Net names do not change** — only the MCU pins. `I2C0_SCL`/`I2C0_SDA` keep the
PD bus (`U9` INA228, `U4` TPS26750, `R31`/`R32`); `I2CC_SCL_MCU`/`I2CC_SDA_MCU`
keep the OLED socket (`J5`) and the EEPROM jumpers (`JP8`/`JP9`, `R88`/`R89`).
That means the existing pull-ups travel with their buses automatically.

### Spare pins after rev3

`PA2`, `PA5`, `PA10`, `PB2`, `PB6`, `PC10`, `PC11` — plus `PB3` if the
`SWITCH_EN_MANUAL` removal in §9.2 is kept.

---

## 3. ⚠️ Required correction: PB6 is not I2C-capable

**The schematic currently routes `/MCU/I2CC_SCL_MCU` to `U2` pin 44 (PB6). That
is not valid.** PB6 has **no I2C alternate function at all** on the STM32G474.

PB6's complete alternate list (from the MCU symbol): `COMP4_OUT`, `FDCAN2_TX`,
`HRTIM1_EEV4`, `HRTIM1_SCIN`, `LPTIM1_ETR`, `SAI1_FS_B`, `TIM16_CH1N`,
`TIM4_CH1`, `TIM8_BKIN2`, `TIM8_CH1`, `TIM8_ETR`, `UCPD1_CC1`, `USART1_TX`.
Nothing I²C. The HAL agrees: `I2C1` exposes only `SCL = PA13, PA15, PB8` and
`SDA = PA14, PB7, PB9` — no PB6. Compiling it produces
`error[E0277]: the trait bound 'PB6: SclPin<I2C1>' is not satisfied`.

**Fix:** move `/MCU/I2CC_SCL_MCU` from **PB6 (pin 44)** to **PC6 (pin 29)**.
PB7 stays as `/MCU/I2CC_SDA_MCU`; together they are `I2C4`. **PC6 is currently
unconnected**, so this is a one-net move with no side effects. PB6 becomes a
spare.

> Do not ship the PCB without this fix — the OLED and the MCU-side EEPROM
> flashing path would both be dead.

---

## 4. Schematic changes

### 4.1 Already correct in the current schematic

- `U2.16` PC4 → `/MCU/I2C0_SCL` (PD bus SCL) ✔
- `U2.30` PA8 → `/MCU/I2C0_SDA` (PD bus SDA) ✔
- `U2.33` PA11 → `/MCU/USB_D_N` ✔
- `U2.34` PA12 → `/MCU/USB_D_P` ✔
- `U2.42` PB4 → `/MCU/ENC_A`, `U2.43` PB5 → `/MCU/ENC_B` ✔
- `U2.45` PB7 → `/MCU/I2CC_SDA_MCU` ✔
- `U2.18` PB1 → `R78` (10 Ω) → `Q13` gate → `/Converter/Conv-Disable` ✔
- `U2.17` PB0 → `/MCU/ENC_BUTT` ✔
- `U2.46` PB8 → BOOT0 net: `SW2` to `+3V3`, `R59` 357 kΩ to `GND` ✔
- `SW3` added across `/MCU/Reset` → `GND` (NRST button) ✔
- `U12` FT234XD removed, with `C50`, `C71`–`C74`, `D30`, `R58` ✔
- `PC10`/`PC11` freed ✔
- USB data path: `P1.A6 (D+)` → `U3.C_SBU1` → `U3.SBU1` → `PA12`;
  `P1.A7 (D-)` → `U3.C_SBU2` → `U3.SBU2` → `PA11` ✔ polarity correct
- `R59` moved off the old `I2C0_SCL` onto PB8 ✔

### 4.2 Still to do

1. **Move `/MCU/I2CC_SCL_MCU` from PB6 to PC6** (§3).
2. **BOOT0 pull-down value.** `R59` = 357 kΩ works (STM32G4 BOOT0 has no
   internal pull, and the button drives it hard to +3V3), but ST's reference
   designs use 10 k–100 k. **100 kΩ** is the safer choice for noise margin.
3. **Logic power for DFU.** The `+3V3` rail comes from the buck whose input is
   selected by `JP13`, which currently defaults to **VPP (XT90)**. With only a
   USB-C cable connected to a PC and no XT90 input, the MCU is unpowered and
   nothing enumerates. Either:
   - bridge `JP13` 2–3 (`+VBUS`), or
   - OR `VPP` and `+VBUS` into the buck input so either source powers the logic, or
   - accept that the normal input supply must be connected while flashing.
4. **Optional:** expose `PC10`/`PC11` (freed USART3) on a debug header or test
   pads. They are free, and a hardware UART is useful for bring-up even with
   USB DFU in place.
5. **Optional:** if the SBU-channel data path is disliked, add a `USBLC6-2SC6`
   and wire the connector D+/D- straight to PA11/PA12. The existing path is
   fine for full-speed (12 Mbit/s) and gives short-to-VBUS protection.

### 4.3 BOOT0 strap behaviour

| condition | BOOT0 (PB8) | result |
|---|---|---|
| power-up / reset, `SW2` not pressed | LOW via `R59` | application boots |
| `SW2` held, then reset | HIGH via `SW2` | ROM USB DFU, stays |

---

## 5. Option bytes

Program once per board:

- **`nSWBOOT0 = 1`** — BOOT0 is taken from the PB8 pin (otherwise the pin is
  ignored and the software `nBOOT0` bit decides).
- **`nBOOT1 = 1`** — BOOT0-high selects system memory.

`FLASH_OPTR`: **`0xFBEFF8AA` → `0xFFEFF8AA`** (bit 26 set).

Verify with STM32CubeProgrammer → Option Bytes, or by SWD. With PB8 forced high
the device must enter the loader on reset and stay there.

> The two boot-entry schemes are mutually exclusive. This ECO uses the
> **hardware strap** (`nSWBOOT0 = 1`). Do **not** also implement the
> `nBOOT0`-software entry from `ECO-rev3-boot0.md` §7 — it requires
> `nSWBOOT0 = 0`.

---

## 6. Firmware port

This section is self-contained: an agent with only this document and the repo
can perform the port.

### 6.1 Pin assignment to apply

```
USB_DM            = PA11
USB_DP            = PA12
BOOT0             = PB8      (hardware; nothing in firmware)
converter disable = PB1      (Output)
encoder button    = PB0      (Input, Pull::Up)
encoder A / B     = PB4 / PB5   : Qei on TIM3
PD bus            = I2C2 : SCL=PC4, SDA=PA8    DMA1_CH1 (TX), DMA1_CH2 (RX)
OLED bus          = I2C4 : SCL=PC6, SDA=PB7    DMA1_CH3 (TX), DMA1_CH4 (RX)
```

### 6.2 `src/main.rs` — substitutions

| find | replace |
|---|---|
| `Qei::new(p.TIM4, QeiPin::new(p.PB6), QeiPin::new(p.PA12))` | `Qei::new(p.TIM3, QeiPin::new(p.PB4), QeiPin::new(p.PB5))` |
| `Input::new(p.PB4, Pull::Up)` (encoder button) | `Input::new(p.PB0, Pull::Up)` |
| `p.PA11,` (inside `ConverterEnable::new(Output::new(...))`) | `p.PB1,` |
| `p.I2C3, p.PA8, p.PB5, Irqs, p.DMA1_CH3, p.DMA1_CH4` | `p.I2C4, p.PC6, p.PB7, Irqs, p.DMA1_CH3, p.DMA1_CH4` |
| `p.I2C1, p.PB8, p.PB7, Irqs, p.DMA1_CH1, p.DMA1_CH2` | `p.I2C2, p.PC4, p.PA8, Irqs, p.DMA1_CH1, p.DMA1_CH2` |

In `bind_interrupts!`:

| find | replace |
|---|---|
| `I2C1_EV => ...EventInterruptHandler<peripherals::I2C1>;` | `I2C2_EV => ...EventInterruptHandler<peripherals::I2C2>;` |
| `I2C1_ER => ...ErrorInterruptHandler<peripherals::I2C1>;` | `I2C2_ER => ...ErrorInterruptHandler<peripherals::I2C2>;` |
| `I2C3_EV => ...EventInterruptHandler<peripherals::I2C3>;` | `I2C4_EV => ...EventInterruptHandler<peripherals::I2C4>;` |
| `I2C3_ER => ...ErrorInterruptHandler<peripherals::I2C3>;` | `I2C4_ER => ...ErrorInterruptHandler<peripherals::I2C4>;` |
| `USART3 => ...usart::InterruptHandler<peripherals::USART3>;` | *(delete line)* |

Also update the bus comments: `I2C2` is now the **PD** bus, `I2C4` the **UI**
bus; the "rev2 bodge" comment about PC4/PB7 and PB8 no longer applies.

### 6.3 Delete the UART service / software-handoff path

The ROM loader is now entered by hardware, so all of this is dead code:

- `src/hal/bootloader.rs` — delete the file (or keep only `SYSTEM_MEMORY_BASE`
  if referenced; nothing else uses it).
- `src/service.rs` — delete the file and remove `pub mod service;` from
  `src/lib.rs`.
- `src/main.rs`:
  - `use nitride_firmware::service::{self, service_uart_task};` — delete.
  - the `bootloader::take_request_diag()` / `jump_to_system_bootloader()` block
    near the top of `main` — delete.
  - the `board::SERVICE_BOOT_HOLD` BTN1-held-at-boot block — delete.
  - the whole `let mut service_uart = if board::SERVICE_UART_AUTODETECT { ... }`
    block (the `Uart::new(p.USART3, p.PC11, p.PC10, ...)` construction) — delete.
  - `if let Some(uart) = service_uart.as_mut() { ... }` diagnostic block — delete.
  - `spawner.spawn(service_uart_task(uart)).unwrap();` and the surrounding
    `if let Some(uart) = service_uart` — delete.
  - the service-request park + `Timer::after(...SERVICE_PARK_SETTLE_MS)` +
    `bootloader::request_on_next_boot()` trigger — delete.
  - this frees `DMA1_CH5` and `DMA1_CH6`.
- `src/board.rs` — delete `SERVICE_UART_BAUD`, `SERVICE_UART_AUTODETECT`,
  `SERVICE_BOOT_HOLD`, `SERVICE_PARK_SETTLE_MS`, and their doc comments.
- `src/hal/converter_enable.rs` — doc comment: `PA11` → `PB1`.
- `src/drivers/ina228.rs` — doc comment: `I2C1: SCL=PB8, SDA=PB7` →
  `I2C2: SCL=PC4, SDA=PA8`.
- `src/runtime.rs` — bus doc comments: I2C2 = PD bus, I2C4 = UI bus.
- `README.md` / `BENCH.md` — pin table and the flashing procedure (§7).

### 6.4 Not required

No new crates are needed. The ROM USB DFU runs before the application; the
application itself needs no USB code. If a USB CDC console is wanted later, add
`embassy-usb` and `Driver::new(p.USB, Irqs, p.PA12, p.PA11, ...)` — both pin
traits exist (`DpPin, USB, PA12`, `DmPin, USB, PA11`), and the interrupt is
`USB_LP`.

### 6.5 Keep

- Encoder handling is unchanged: the same `Qei` driver, the same X4 decoding
  (`Sms::ENCODER_MODE_3`), the same `board::ENC_DETENT_COUNTS` conversion.
  Only the timer instance and pins change.
- The two-bus lock ordering in `src/runtime.rs` is unchanged in structure.

---

## 7. Flash procedure

1. Hold **BOOT0** (`SW2`), press and release **NRST** (`SW3`), release BOOT0.
2. The device enumerates as STM32 DFU: `0483:df11`.
3. Write:

```bash
dfu-util -a 0 -s 0x08000000:leave -D firmware.bin
# or: STM32CubeProgrammer -> USB -> Download
```

`-s 0x08000000:leave` tells the loader to start the application after the write.

**Recovery:** SWD on `J4` always works, even with a corrupt application. A bad
flash is never a brick.

---

## 8. Bench verification checklist

1. `FLASH_OPTR` reads back `0xFFEFF8AA`.
2. `SW2` released, power cycle → application runs (OLED up), PB8 ≈ 0 V.
3. `SW2` held + `SW3` tapped → `lsusb` shows `0483:df11`; `dfu-util -l` lists
   the device.
4. Full write of `firmware.bin` completes and the `:leave` command starts the
   application.
5. Scan I2C2: INA228 `0x40`, TPS26750 `0x21`.
6. Scan I2C4: SSD1306 `0x3C`, CAT24C512 `0x50` when `JP8`/`JP9` are bridged.
7. Encoder: turning one detent produces exactly one `EncTurn` in each
   direction (same behaviour as the TIM4 build).
8. **Converter state during DFU** — with a load attached, confirm the output
   stays parked across a BOOT0+RST entry (see §9.4).

---

## 9. Open items and findings outside this ECO's scope

The netlist diff against the previous revision surfaced changes that are **not
part of the USB-DFU work**. These are flagged, not judged.

### 9.1 Required before fabrication

- **PB6 → PC6** for `/MCU/I2CC_SCL_MCU` (§3). This is a hard error.

### 9.2 Power-path edits — confirm intentional

Also present in the current schematic, unrelated to flashing:

- `U7` removed (was on `/USB-PD/PP_EN2`, `/USB-PD/PP_EN3`,
  `/MCU/SWITCH_EN_MANUAL`, `+3V3_LDO`, `GND`).
- `JP14` and `R37` removed; `/MCU/SWITCH_EN_MANUAL` no longer exists.
- `U2.41` PB3 freed (was `/MCU/SWITCH_EN_MANUAL`).
- `R41` and `R91` moved from `/USB-PD/PP_EN3` to `/USB-PD/PP_EN2`.

This removes the MCU's manual switch-enable override and changes the 240 W
power-path enables. If these were deliberate, fine — but they should be a
separate, explicitly-reviewed change. `/MCU/SWITCH_EN_READ` (PB14) is still
present and still readable, so the firmware's read path is unaffected.

### 9.3 Power for enumeration

See §4.2 item 3 (`JP13`). Without it, "plug into a PC and flash" needs the
normal input supply connected too.

### 9.4 Converter state during reset

Moving the disable from PA11 to PB1 does not change the underlying hazard: the
pin floats while the ROM loader runs, and the converter's state is set by the
`R7`/`R8` divider (see the `/Converter/Conv-Disable` finding in `BENCH.md` and
the note in `src/board.rs`). PB1 floats exactly like PA11 did. Verify the
divider holds the converter **off** through a DFU session before flashing with
a load attached.

---

## 10. Verification evidence

Checks run for this document:

1. **Symbol check** — every recommended pin's alternate functions read from the
   STM32G474CEU symbol in `MCU.kicad_sch`.
2. **HAL check** — the `embassy-stm32` pin-trait table generated for
   `stm32g474ce` (`out/_generated.rs`) consulted for each pin/peripheral pair.
3. **Compile test (positive)** — the full new pin map patched into `main.rs`
   (`TIM3/PB4/PB5`, `I2C4/PC6/PB7`, `I2C2/PC4/PA8`, button PB0, disable PB1,
   `bind_interrupts!` with `I2C2_EV/ER` + `I2C4_EV/ER`). `cargo check` →
   **exit 0**. This proves TIM3 is `GeneralInstance4Channel` (QEI-capable) and
   that all four I²C pins carry the required traits.
4. **Negative controls** —
   - `I2C1` with `PB6` as SCL →
     `error[E0277]: the trait bound 'PB6: SclPin<I2C1>' is not satisfied`.
   - `I2C2` with `PB5` as SCL →
     `error[E0277]: the trait bound 'PB5: SclPin<I2C2>' is not satisfied`.
   The controls failing proves the positive result is a real type-check, not a
   cached pass.
5. **Netlist diff** — the current `nitride-nano.kicad_pcb` pad→net map diffed
   against `git HEAD` to enumerate every changed connection; §4 and §9 are
   derived from that diff.

`src/main.rs` was restored byte-for-byte after the compile tests (MD5 verified);
the firmware source is currently unmodified.

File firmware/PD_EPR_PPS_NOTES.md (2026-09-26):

# TPS26750 PD config — EPR + PPS

`config_240W_TPS26750_F8091159_epr_pps.json` is the corrected USBCPD Application
Customization Tool project for the nitride-nano sink. Regenerate the full-flash C
from it and flash it to the TPS26750's EEPROM with the firmware's **EEPROM FLASH**
screen; the config in `src/drivers/config_TPS26750_F8091159_fullFlash.c` is a
generated artifact, not something to hand-edit.

## Sink PDOs (`0x33` TX_SINK_CAPS)

| Slot | Type | Setting |
|---|---|---|
| 1 | Fixed | 5 V / 3 A |
| 2 | Fixed | 9 V / 3 A |
| 3 | Fixed | 12 V / 3 A |
| 4 | Fixed | 15 V / 3 A |
| 5 | Fixed | 20 V / 5 A |
| 6 | SPR PPS APDO | 3.3–21 V / 3 A |
| 8 | Fixed EPR | 28 V / 5 A |
| 9 | Fixed EPR | 36 V / 5 A |
| 10 | Fixed EPR | 48 V / 5 A |
| 11 | EPR AVS APDO | 15–48 V / 240 W |

Header byte `0x26` = 6 valid SPR + 4 valid EPR PDOs (slots 7, 12, 13 empty).

Defects this fixes versus the attached JSON:

* header claimed **6 SPR + 6 EPR** with only 4 + 4 PDOs populated, so the
  Sink_Capabilities message was malformed;
* the 15–48 V APDO had APDO-type bits `00` (PPS) instead of `01` (EPR AVS), at
  register bits 356:357 — the "EPR Adjustable Voltage Supply" field TI says must
  read 1;
* no 12 V PDO and no PPS APDO.

## Autonegotiate Sink (`0x37`)

* `NoCapabilityMismatch = 1`, auto-disable off: the sink path stays on for any
  source instead of refusing low-power ones.
* Auto-computed min/max voltage, max current 5 A.
* PPS enabled (20 V / 3 A default); EPR AVS enabled (48 V / 5 A).
* The firmware overrides these fields on every rail request, so the defaults only
  cover the window between plug-in and the first host request.

## Importing into the GUI (this is where it usually goes wrong)

1. Select **TPS26750** on the first page — not the gear icon.
2. Turn on **Advanced Configuration** *before* importing.
3. **Import Settings**, and tick the box to keep Advanced Configuration changes.
4. After importing, do **not** click "Standard Configuration" or the gear: that
   re-derives the registers from `questionnaire.answers` and discards the
   Advanced edits (including `0x33`/`0x37`).
5. Verify in Advanced view that `0x33` shows the six SPR + four EPR PDOs above,
   then export a new **Full Flash** binary and rebuild the firmware.

If the GUI proves unusable, the config already in the tree has the 28/36/48 V EPR
PDOs (header `0x24`, 4 SPR + 4 EPR) but no PPS/12 V. It plus the firmware change
below gives EPR without needing the GUI at all.

## After flashing the EEPROM: power-cycle the TPS26750

`EepromLoader` writes and verifies the CAT24C512 over I2C3 but **does not reset
the TPS26750** — it reads its application config only at power-up. Until the
controller is power-cycled it keeps running the previously loaded image, so an
EEPROM flash alone changes nothing (this is very likely why the 28 V preset
looked inert). Unplug the USB-C source and the board supply for a few seconds
after flashing.

The firmware now reads the live image back on every `TPS26750 present` and logs:

```
TPS config 0x33: hdr=0x26 SPR=6 EPR=4
TPS config 0x37: b0=0x3e maxV=48000 mV maxI=5000 mA
```

If that header is not `0x26`, the controller is still running an old image.

## Diagnosing a preset that does not engage

The PD manager now logs the whole path:

| Log line | Meaning |
|---|---|
| `PD confirm: mode=manual preset=3 caps=.. choice=28000 mV epr_ok=true` | the UI confirm resolved to a 28 V request |
| `PD confirm: ... choice=20000 mV epr_ok=false` | EPR is latched off, so the preset falls back to 20 V |
| `PD source caps: SPR=6 EPR=2 last_epr=true` | the controller has entered EPR and can see EPR PDOs |
| `PD request: rail=28000 mV` | the request was actually written to `0x37` and `GSrC` issued |
| `PD request failed for rail=28000 mV` | the I2C write to `0x37` failed |
| `PD contract: 28000 mV @ 5000 mA` | the source confirmed the new contract |
| `EPR unavailable: 28000 mV request settled at 20000 mV` | EPR entry failed; SPR fallback latched |

If `PD confirm` shows `choice=28000` and `PD request` appears but no
`PD contract: 28000`, EPR entry is failing at the protocol level (cable e-marker,
source, or the `0x33`/`0x37` image).

## Root cause of "28 V preset does nothing"

Field log showed the loaded image was correct (`MODE=APP`, `0x33 hdr=0x26`) but:

```
PD confirm: mode=manual preset=3 caps=7 choice=20000 mV epr_ok=true
```

Preset 3 (28 V) resolved to a **20 V** request, so no EPR request was ever sent.
`auto_track::candidates()` decided whether the source already advertised EPR
with `voltage_mv > SPR_MAX_MV`. A **PPS APDO stores its maximum voltage in
`voltage_mv`, and PPS reaches 21 V**, so any PPS-capable source looked
EPR-capable and the declared 28/36/48 V rails were never injected. The check now
requires a *fixed* PDO above 20 V:

```rust
let advertised_epr = caps
    .iter()
    .any(|c| is_fixed(c) && c.voltage_mv > board::SPR_MAX_MV);
```

With a 7-SPR PPS source (EPR not yet entered) the presets now resolve to
12/15/20/28/36/48 V and Auto at 48 V/5 A resolves to 48 V.

## EPR mode entry — the remaining blocker

The firmware request path is correct, but the controller never enters EPR mode
(`PD source caps: SPR=7 EPR=0`, `last_epr=false`). Two request styles were tried:

* **Explicit >20 V window** (min 26.6 V, max 29.4 V). Per SDAA265 §5.3,
  "Whenever the AutoNegMaxVoltage or AutoNegMinVoltage is not met, the 5V PDO is
  chosen as a default" — before EPR mode entry the source only offers SPR PDOs
  (≤20 V), so nothing is in range and the controller requests 5 V.
* **`AutoComputeSinkMaxVoltage = 1`**. Per SDAA265 §3.5 this computes the max
  from the source PDOs *currently on offer*, which pre-entry is 20 V, so the
  controller settles at 20 V and still does not enter EPR.

Per SDAA265 §5.2 an EPR-capable controller "can successfully enter into EPR mode
with an EPR-capable USB-PD Source", so mode entry is *upstream* of these
settings. USB-PD 3.1 gates it on:

| Where | Bit | Meaning |
|---|---|---|
| Source Fixed 5 V PDO | B23 | EPR Mode Capable |
| Sink RDO | B22 | EPR Mode Capable (the controller sets it from the config) |
| Cable e-marker VDO | B17 | EPR Mode Capable |

The sink's own Fixed PDO has **no** EPR bit (Table 6-16, B22:20 reserved), so
nothing in `0x33` is missing there, and no other config register gates EPR:
`0x42` PD3 Config has no EPR enable, and `0x5C` IO Config byte 38 = `0x5c`
already maps GPIO2 to event 92 — the TPD4S480 `EPR_EN` net
(`/USB-PD/EPR_EN` = TPS26750 pin 7 GPIO2 → TPD4S480 pin 16).

**Event 92 is `VBUS_SENSE_DIVIDER`** (TRM Table 6-6): *"GPIO is enabled whenever the
PD controller is transitioning into EPR mode. This GPIO will enable the external
VBUS divider."* It is therefore a **consequence** of EPR entry, not its trigger —
the GPIO2→92 mapping cannot be why entry never happens. (Event 142,
`EPR_DISCHARGE_EVENT`, is for an external discharge circuit on EPR exit and is not
required for entry either.)

Field result with a known-good EPR source and cable:

```
source 5V PDO=176263468 epr_capable=true    # 0x0A81912C, B23 = 1
PD source caps: SPR=6 EPR=0 last_epr=false
```

The source is genuinely EPR-capable, so the blocker is the **sink**: the TPS26750
never sends `EPR_Mode(Enter)`. The contract log now also prints the active RDO's
EPR bit:

```
PD contract: 20000 mV @ 5000 mA rdo_epr=false
```

Per spec §6.4.10.1 the sink sets RDO B22 and sends `EPR_Mode(Enter)` itself. The
field result is:

```
PD contract: 12000 mV @ 3000 mA rdo_epr=true
PD request: rail=28000 mV
PD contract: 5000 mV @ 3000 mA rdo_epr=true
```

So `rdo_epr=true` on **every** contract — the controller is already attempting
EPR mode entry, its RDO satisfies §6.4.10.1 step 2a, and the source's 5 V PDO
satisfies step 2b. The entry handshake is what fails; the 5 V contract is then
SDAA265 §5.3's fallback because the [26.6, 29.4] V window no longer matches any
SPR PDO once the EPR attempt aborts.

`Enter Failed` codes the source can send (spec Table 6-50): `0x01` cable not EPR
capable, `0x02` source failed to become VCONN source, `0x03` RDO bit missing
(ruled out), `0x04` source unable at this time, `0x05` PDO bit missing (ruled
out). The TPS26750 does not expose the received code, so reading it needs a
CC-line protocol capture.

With both source and cable proven good against another EPR sink, the remaining
suspects are the `EPR_Mode(Enter)` payload (its Data field is the EPR Sink
Operational PDP), the PD-firmware version in the generated image, or the
TPD4S480 `EPR_EN` / `EPR_BLK_G` transition itself (see the E2E thread where the
`EPR_BLK_G` gate drive collapsed at 23 V and the TPD4S480 FAULT asserted).

Remaining things to try, in order:

1. Regenerate the config **without the EPR AVS APDO** (fixed 28/36/48 only). The
   GUI's `EPR_Sink_AVS_Controls` tab is documented as broken on E2E and the AVS
   APDO is the only unusual entry in `0x33`.
2. Power-cycle the TPS26750 and confirm the boot read-back shows
   `TPS config 0x37: b0=0x3e` (the config value) rather than the firmware's
   previous write — a persistent `b0=0x0a` means the image never reloaded.
3. Confirm the GUI build is 2.0.1+ and regenerate the Full Flash from it: TI
   shipped an EPR-related PD-firmware fix that only applies when a new binary
   image is generated.

## Encoder

`Qei::new` uses X4 decoding, but the fitted encoder produces a detent every
**two** counts (measured: one detent used to fire two `EncTurn` events; dividing
by 4 then made the knob half-speed, and 2 is correct). `board::ENCODER_COUNTS_PER_DETENT`
is 2 and raw counts are divided by it with the remainder carried between polls.

## Firmware changes

* `src/board.rs` — `SPR_MAX_MV`, `EPR_RAILS_MV`, `EPR_RAIL_CURRENT_MA`,
  `PPS_MIN_MV`/`PPS_MAX_MV`/`PPS_FIXED_PREFER_MV`.
* `src/pd/auto_track.rs` — injects the declared 28/36/48 V EPR rails as
  candidates whenever SPR cannot deliver the setpoint (the source's EPR PDOs are
  invisible until EPR mode has been entered); serves a preset that no fixed PDO
  matches from the source's PPS APDO.
* `src/pd/manager.rs` — issues PPS vs fixed requests, and latches EPR off after
  one request settles back at an SPR voltage, so a non-EPR source falls back to
  20 V instead of sitting on a request it can never satisfy.
* `src/drivers/tps26750.rs` — the PPSEnableSinkMode toggle is now applied only to
  PPS requests; for fixed SPR/EPR requests it used to briefly assert PPS with
  whatever PPS voltage `0x37` held and could start a spurious PPS negotiation.
  Also exposes `source_5v_pdo()` and `request_epr_entry()` (the latter currently
  unused: `AutoComputeSinkMaxVoltage` cannot reach EPR, see above).

The rail chooser is pure logic and is exercised by
`.tmp_research/autotrack_test/` (host harness that includes the real
`auto_track.rs`).

## PD analyzer captures (`PD-Captures/`)

Decoded from the two `.sqlite` captures (6-byte record prefix, then the PD header +
data objects, little-endian).

**`pd-nitride-nano.sqlite`** — the source refuses:

```
3.852  EPR_Mode  action=1 (Enter)          sink -> source  data=0x00
3.859  EPR_Mode  action=2 (Enter Ack)      source -> sink
3.909  EPR_Mode  action=4 (Enter Failed)   source -> sink  data=0x01
```

Data `0x01` is **"Cable not EPR capable"** (spec Table 6-50) — i.e. the source's
step-6 `Discover Identity` on SOP' read the cable e-marker and rejected it
(cable VDO must declare 50 V, 5 A and EPR Mode Capable).

**`pd-nitride-nano(anker737).sqlite`** — the Anker 737 accepts entry:

```
4.335  EPR_Mode  action=1 (Enter)          sink -> source  data=0x00
4.341  EPR_Mode  action=2 (Enter Ack)      source -> sink
4.468  EPR_Mode  action=3 (Enter Succeeded) source -> sink
4.606  VBUS 20.23 -> 12.22 V, fresh SPR Source_Caps
```

EPR mode entry **succeeds** here, but `EPR_Source_Capabilities` never arrives —
neither capture contains a single 28/36/48 V PDO — and the port drops back to
SPR 12 V ~140 ms later, then emits a continuous Discover-Identity retry storm
(two per ~400 ms for 20 s).

So the controller and its `EPR_Mode(Enter)` are correct; the failure is in the
**cable e-marker read / VCONN path** after Enter Ack. `EPR_EN` never rising is
consistent: event 92 drives the VBUS divider for the 20→28 V *transition*, which
is never reached.

## A/B against a working EPR sink (`PD-Captures/pd-soldering.sqlite`)

The soldering iron completes EPR with the same source and cable: `EPR_Mode`
Enter (4.010) → Ack (4.017) → **Succeeded** (4.043), and VBUS reaches **28.14 V**.

The board's trace is structurally identical through mode entry — and the source
offers the 28 V PDO (`f4c10800`) to **both**:

| | after `EPR_Mode Succeeded` | next exchange | VBUS |
|---|---|---|---|
| iron | `b1a3 2088a4c1 f4c10800` | `892a f4d14783 f4c10800` → 28 V/5 A | **28.14 V** |
| board | `b1ab 20880000 f4c10800` | `8926 0000c033 2cc10300` → 12 V/3 A | **12.22 V** |

So the source is offering 28 V in both cases, and the board's link is the one
that ends up referencing the **12 V** object. The differentiator is the board's
own host override on `0x37`: the manual preset defaults to 12 V, so the
controller is told max ≈12.6 V (`TPS config 0x37: b0=0x0a maxV=12600`) and asks
for 12 V even after entering EPR. The iron does no host override, so it stays in
EPR at 28 V. This also explains `EPR_EN` never rising.

## Boot behaviour: autonegotiate first (the fix)

The A/B capture above showed the board receiving the source's 28 V offer and then
walking itself back to 12 V. Two things in the firmware caused that:

1. At boot the firmware wrote a `0x37` window for the manual default preset
   (12 V), which the controller then requested even after entering EPR.
2. `modify_sink_register()` **cleared `EPR AVS Enable Sink Mode`** on every plain
   fixed/PPS request. That bit is what makes the controller attempt EPR mode
   entry at all, so after the first host write the board could never enter EPR
   again — which is why it only ever did so on the very first negotiation after
   a config load, and why `EPR_EN` never rose.

`PdManager` now, on `TPS26750 present` and on plug, **in Manual mode**:

* calls `Tps26750::restore_autonegotiate()`, which writes back the config's
  intent — auto-computed voltage range, PPS enabled, **EPR AVS enabled** — and
  issues `GSrC`;
* does **not** queue a rail request, so the controller's own negotiation runs and
  it can enter EPR and hold the highest rail.

Only when the user confirms a preset (or Auto-tracking decides on a change) does
the firmware write a specific window. The `epr_seen` re-request is likewise
Auto-only now, so a Manual EPR contract is not clobbered the moment it appears.

Expected on the next capture: the controller enters EPR on its own at plug
(`EPR entered (n EPR PDOs)`), holds it, and a 28 V confirm produces
`PD request: rail=28000 mV` → `PD contract: 28000 mV`.

## Config regression: "Standard Configuration" drops the Advanced PDOs

The image in the tree mid-session had reverted to a GUI **Standard
Configuration** regeneration: `0x33 hdr=0x1c` (SPR 5/9/15/20 + EPR 28/36/48, the
PPS APDO *and* the EPR-AVS APDO gone) with `0x37 b0=0x76` (PPS and EPR-AVS
disabled). Without the EPR-AVS APDO **and** its enable bit the controller never
attempts EPR mode entry, so `EPR entered` never fires — which is exactly what the
last log showed.

`src/drivers/config_TPS26750_F8091159_fullFlash.c` has had `0x33`/`0x37`
restored in place from `config_240W_TPS26750_F8091159_epr_pps.json` (all four TLV
copies, i.e. both the low and high region). A backup of the pre-patch file is at
`config_TPS26750_F8091159_fullFlash.c.bak`.

**Re-exporting from the GUI — especially pressing "Standard Configuration" —
will undo this again.** Use Advanced Configuration and import the JSON, or keep
editing the generated C.

## EPR entry succeeds, then exits — PPS priority

`PD-Captures/pd-nitride-nano(anker737)-NEW.sqlite` (Anker + validated config)
shows the full sequence for the first time:

```
3.363  EPR_Mode action=1 Enter            (sink)
3.369  EPR_Mode action=2 Enter Ack        (source)
3.493  EPR_Mode action=3 Enter Succeeded  (source)   <- EPR entered
3.519  <request carrying a PPS 21 V / 5 A object>
3.551  EPR_Mode action=5 Exit             (sink)     <- and left ~60 ms later
```

So the board **does** enter EPR with the Anker; it then negotiates a <=21 V
**PPS** contract and exits. The TRM is explicit: *"PPS contracts are prioritized
over any other supply type."* `restore_autonegotiate()` enabled PPS, which is
what drove this.

Actions taken:

* the boot path is reverted — `TPS26750 present` / plug now just set
  `negotiate_pending`, so the firmware writes its normal fixed window (which
  clears `PPSEnableSinkMode`);
* `0x33`/`0x37` in the full-flash image now ship with `PPSEnableSinkMode`
  **clear** (`0x37 byte8 = 0x02`), keeping EPR-AVS enabled and the voltage range
  auto-computed.

The firmware still enables PPS explicitly (`request_pps_profile`) when a preset
is actually served from a PPS APDO, so 12 V-via-PPS still works.

## The full-flash image is checksummed — do not hand-edit it

Each config region in `config_TPS26750_F8091159_fullFlash.c` is preceded by a
region header and a 32-bit integrity value:

```
0x880 : 01 00 78 02  <32-bit checksum>  ...config TLVs...
0x4480: 01 00 78 02  <32-bit checksum>  ...same TLVs (second copy)...
```

Every hand-patch of the TLV bytes invalidated that value, and the TPS26750 then
rejected the whole image (its Status register reports Region 0/1 EEPROM errors) —
i.e. "the EEPROM file doesn't work at all". The value is not a plain CRC-32 over
the obvious range, so it cannot be recomputed here.

**Therefore: edit the config in the TI GUI and export a new Full Flash binary;
never patch the generated C by hand.** The pre-patch file has been restored from
`config_TPS26750_F8091159_fullFlash.c.bak`.

To apply the PPS fix in the GUI: Advanced Configuration → **Autonegotiate Sink
(0x37)** → clear **PPS Enable Sink Mode** (keep **EPR AVS Enable Sink Mode** set)
→ export Full Flash. `config_240W_TPS26750_F8091159_epr_pps.json` already has
that bit cleared (`byte8 = 0x02`) for import.

## Bench checks

* Boot: `source 5V PDO=... epr_capable=true|false`. `false` = source not EPR.
* EPR source, high setpoint: `PD request: rail=48000 mV`, and the active contract
  reads 48 V.
* Non-EPR source, high setpoint: one EPR attempt, then `EPR unavailable: ...`
  and a fallback to 20 V.
* PPS source: select the 12 V preset; the contract is a PPS 12 V contract.

## How the working reference (PD240W) reaches EPR

`PD240W-main-Examplecode/` is the same sink topology on the same TPS26750, and
it holds 28 V/36 V/48 V. Its PD driver is the `theohg/tps26750_multiplatform`
submodule (pinned at `5ba57e5`), not the in-tree `src/tps26750.cpp` the Rust port
was originally cut from. The differences that matter:

| Reference does | nitride-nano did |
|---|---|
| Requests every >20 V rail as an **EPR AVS** contract (`requestAVSProfile`, 0x37 bit 128 `EPR AVS Enable Sink Mode` = 1, PPS off) | Requests a **fixed** >20 V window (`requestFixedProfile`), which *clears* the EPR AVS enable bit |
| Sends the `ESrC` 4CC task (`probeEpr()`) to make the controller enter EPR and fetch the source's EPR PDOs | Never sends `ESrC` |
| Keeps **PPS disabled** whenever EPR is wanted (PPS outranks EPR, TRM 6.3) | Config ships PPS disabled, but an earlier `restore_autonegotiate()` enabled PPS and pulled the contract back to a PPS 21 V object, then EPR exit |
| Handles interrupt bit 14 `SOURCE_CAP_RX` (raised on EPR entry *and* exit) and re-reads the PDO list | Only handled bits 3 (plug) and 12 (new contract), so the EPR PDOs were never re-read |
| Refreshes the AVS contract every 7 s (`serviceKeepAlive`) | Issued one fixed request and never refreshed |
| Requests a host min/max window with `AutoComputeSinkMaxVoltage = 0` | Wrote a fixed 26.6–29.4 V window that matches no *visible* SPR PDO |

### Why the fixed >20 V window can never enter EPR

SDAA265 §5.3: *"Whenever the AutoNegMaxVoltage or AutoNegMinVoltage is not met,
the 5 V PDO is chosen as a default."* Before EPR mode entry the source only
advertises SPR PDOs (≤20 V), so a 26.6–29.4 V window discards every PDO and the
controller settles on **5 V**; it does not enter EPR. EPR mode entry is gated on
`AUTO_NEGOTIATE_SINK.EPR AVS Enable Sink Mode` (TRM Table 4-21, bit 128): *"If
this bit is asserted, then the PD controller will attempt to negotiate a EPR AVS
sink contract."* The reference asserts it on every EPR request; the fixed-request
path in the Rust port clears it. SDAA265 §4.1's alternative — leave
`AutoComputeSinkMaxVoltage = 1` so the controller caps SPR at 20 V and then
computes the EPR maximum itself — cannot pick a *specific* rail and was already
shown to need PPS off.

The Anker capture confirms PPS was the second half of the failure: after
`EPR_Mode Enter Succeeded` the sink immediately sent a Request carrying the PPS
APDO (`64 2d a4 c1`) and then `EPR_Mode Exit` ~60 ms later.

## Fix applied (mirror the reference)

* `src/board.rs` — `EPR_AVS_MIN_MV`/`EPR_AVS_MAX_MV` (15–48 V), matching the
  sink config's `0x33` PDO 11 (`f0 96 c0 d3` = EPR AVS 15–48 V / 240 W).
* `src/pd/auto_track.rs` — every above-SPR choice now carries `avs:
  Some(ApdoWindow)`; `PpsWindow` renamed `ApdoWindow`.
* `src/drivers/tps26750.rs` — `TPS_CMD_ESRC` + `request_epr_source_caps()`, and
  `TPS_INT_SOURCE_CAP_RX` (bit 14).
* `src/pd/manager.rs` —
  * EPR entry is a **probe-and-wait** in `poll`: when the chosen rail is
    above-SPR and EPR has not been seen, the manager sends `ESrC` (logged as
    `EPR probe (ESrC) ok=`) and then **holds the 0x37 write + `GSrC` back**
    until the EPR PDOs appear in `RX_SOURCE_CAPS` (or a 2 s timeout). Issuing the
    request immediately after `ESrC` tears down the EPR session the probe just
    established — that was the field failure: `ESrC ok=true` followed at once by
    a 0x37 rewrite put the contract back at 20 V. This mirrors the reference's
    `probeEpr()` + "wait for EPR PDOs" boot sequence;
  * once the EPR PDOs are visible (`epr_seen`), `negotiate()` names the rail as
    an AVS contract on the source's AVS APDO window, or — when the source has
    only fixed EPR PDOs — through `request_fixed_epr_profile()`, which uses
    SDAA265 §4.1's ≥140 W requirement (`ANSinkCapMismatchPower = 140 W`,
    `NoCapabilityMismatch` clear) over an explicit `[15 V, 51 V]` window and the
    PPS-edge trigger. Host-window variants tried earlier and rejected on the
    bench are kept here so they are not retried: narrow window + `avs_en` set
    (GSrC *and* edge) → 5 V; narrow window + `avs_en` clear (edge) → 5 V;
    auto-compute range → 20 V (auto-compute keeps the max at the SPR 20 V even
    while EPR is active, so the EPR PDO is never ranked — hence the explicit
    window here);
  * an EPR request must **not** be triggered with `GSrC` — it re-fetches the
    *SPR* source caps and restarts SPR negotiation, dropping EPR. EPR requests
    re-evaluate with a 2 ms `PPSEnableSinkMode` edge inside
    `modify_sink_register` (`edge=true`), which is how the reference triggers
    every request. `GSrC` is still used for SPR/PPS;
  * `AutoChoice.epr` marks an above-SPR rail so the request keeps EPR alive;
  * bit 14 (`SOURCE_CAP_RX`) is consumed and forces a PDO re-read, which is how
    the entry is detected. Any successful request also sets `caps_dirty` for one
    re-read, and the PDO set is re-read on EPR exit (`epr == 0`) — **while in EPR
    a source advertises only a reduced SPR set** (5/9/12 V here), so the 15 V and
    20 V presets legitimately resolve to 12 V until EPR exits;
  * a 7 s AVS keep-alive re-issues the contract while it stays above 20 V.

Field result worth remembering: `ESrC ok=true` also proves the **source and cable
accept `EPR_Get_Source_Cap`**, so an `EPR_Mode Enter Failed` seen in an earlier
capture was a firmware sequencing artefact, not a cable rejection.

### Re-confirmed: the brownout is the source's EPR transition, not the voltage

| Source | Requested | Result |
|---|---|---|
| Anker powerbank | 28 V | held, `vin=28262 mV` |
| china charger | 28 V | browned out as VBUS crossed ~23 V |
| 240 W charger | 48 V (`maxV=50400`, targeted path) | browned out at EPR |

Two chargers brown out while a powerbank survives **at the same 28 V**, so this
is not a voltage limit and not the request framing — the firmware issues the
correct 28/48 V request in every case. It is the source's VBUS behaviour through
the 20→28/48 V transition (dV/dt, glitch, or a dip) interacting with the board's
input path.

Mitigation added: `maybe_reenable()` now holds the converter **off for
`board::EPR_SETTLE_MS` (800 ms)** after an EPR request before loading it, instead
of enabling as soon as any >20 V contract appears. Loading the converter while
the source is still settling VBUS is a plausible way to dip it hard enough to
reset the MCU, and the window is cheap to widen if 800 ms is not enough.

That did **not** fix the brownout — the MCU still dies within ~100 ms of the
request with the output already parked, so the load is not involved and the 3V3
rail itself is going away. Two firmware-visible suspects, in order:

1. **TPS26750 GPIO6 drops `/LV-Supply/3V3_EN_PD`** across the EPR transition.
   The driver now issues the `GPsh` 4CC task for GPIO6 at boot and after every
   EPR entry (`TPS GPIO6 (3V3_EN_PD) held high: <bool>`), which overrides an
   event-driven GPIO. `JP16` selects whether the 3V3 buck's `~SHDN` follows that
   signal (2–3) or is auto-enabled (1–2).
2. **3V3 buck enable over-voltage** (only if `JP16` is 1–2). `U11` (LMR16006X)
   `~SHDN` = `R43` 100 k from the buck input with `R82` 33 k + `R84` 4.7 k to
   GND, i.e. `EN ≈ 0.274 × Vin` → **7.7 V at 28 V and 13.1 V at 48 V**, above a
   normal logic-input abs max. That would be a hardware ECO (re-divide/clamp the
   SHDN node), not something firmware can fix.

Measure `+3V3` (TP65/J4), `3V3_EN` (TP67) and the buck input (`Net-(JP13-C)`)
at 48 V to tell them apart: TP67 low ⇒ case 1; TP67 high but `+3V3` collapsed ⇒
case 2 (or the buck itself).

**Result: the `GPsh` GPIO6 hold did not help.** The log shows
`TPS GPIO6 (3V3_EN_PD) held high: true` both at boot and right after EPR entry
(7.681), the 48 V request goes out at 7.686, and the MCU still dies before the
0x37 read-back. So GPIO6 is ruled out; the 3V3 collapse is downstream of the
controller. This is a hardware bring-up issue on the input/enable path — the
firmware has no further lever on it.

### Jumper fix, and the power path that drops out on EPR

Moving the 3V3/6V6 buck input jumper (`JP13`) from `VPP` (XT90) to `+VBUS`
fixed the brownout — the board now rides through EPR on the china charger.
Two things are then visible:

* the china charger **never raises VBUS to 28 V** (measured USB-C = 20 V) and
  the request settles at a 20 V/5 V contract;
* the **converter input collapses to ~4.4 V** (`vin=4407 mV`) while USB-C is at
  20 V, i.e. the board's power path opens and the converter loses its input.

The converter input is not `+VBUS_LV`; it comes through the external power path
(`analysis/root.net`):

```
POWER_PATH_EN (U4.20, TPS26750) ─→ Q8 ─→ PP_EN1 ─→ Q9 ─→ PP_EN2 ─┐
                                                                  U7 74LVC1G08 (AND)
SWITCH_EN_MANUAL (U2.41, MCU PB3) ────────────────────────────────┘
   ─→ PP_EN3 ─→ SWITCH_EN ─→ U8 LTC7004 INP ─→ Q10 gate
   ─→ +VBUS_SENSED ─→ R60 (8 mΩ) ─→ /Converter/PWR_UNREG_IN (INA228 + LT8390)
```

`SWITCH_EN` is also pulled by the INA228 `ALERT` through R55; the MCU's
`SWITCH_EN_MANUAL` is only one input of the AND, so it **cannot force the path
on** if the controller drops `POWER_PATH_EN`. `GPsh` cannot help here either —
`POWER_PATH_EN` is a dedicated pin, not a GPIO.

Diagnose by scoping, on the failing charger vs the Anker:
`TP14` (`POWER_PATH_EN`), `TP17` (`PP_EN1`), `TP19` (`PP_EN2`), `TP21`
(`PP_EN3`), `TP28` (`SWITCH_EN`), `TP25` (`LTC_GATE`), plus the INA228 `ALERT`
(U9 pin 3). Whichever node flips is the culprit; if it is `POWER_PATH_EN`, the
power-path behaviour lives in the TPS26750 application config (0x28 Port
Configuration / 0x29 Port Control) and has to be changed in the TI GUI, not in
this firmware.

## EPR 28 V — WORKS, and the shutdown is source-specific

**Confirmed working (Anker powerbank):** after `ESrC ok=true` → `EPR entered
(1 EPR PDOs)` → `PD request: rail=28000 … epr=true` → `b0=0x02
avs_en=false pps_en=false maxV=51000` → `PD contract: 28000 mV @ 5000 mA
rdo_epr=true`, and the converter holds `vin=28262 mV` continuously.

So the firmware recipe is correct: enter EPR with `ESrC`, then request the
**fixed EPR PDO** with a wide host window and the ≥140 W requirement, triggered
by the PPS-bit edge (never `GSrC`). The source in the failing runs advertised
only `SPR=3 EPR=1` and the board browned out as VBUS crossed ~23 V; the Anker
advertises `SPR=7 EPR=1` and survives the same transition. **The shutdown is
therefore a source/power-path interaction, not PD policy** — the TPD4S480 EPR
adapter section below still applies to whichever source trips it.

Known limitation of the current request: the controller picks the
highest-power EPR PDO inside the `[15 V, 51 V]` window, so on a source that
offers 36 V/48 V EPR it will not necessarily honour a 28 V preset. Narrowing the
window to `target ±5 %` would target a specific EPR PDO, but that variant was
rejected on the failing source and has not been re-tested on the Anker.

## The board shuts down when VBUS reaches EPR (source-dependent, hardware)

With the ≥140 W / wide-window request the board finally drives 28 V
(`PD 0x37 now: b0=0x02 … maxV=51000`) and then **the MCU loses SWD / resets**
exactly as VBUS crosses ~23 V. That is the TPD4S480 EPR adapter doing its job,
and it is *not* something the PD request can avoid — VBUS must pass ~23 V to
reach 28 V.

Netlist path (`analysis/root.net`):

| Net | Nodes | Note |
|---|---|---|
| `+VBUS` | connector, `U3.20` (TPD4S480 VBUS), `Q6.3` (drain), `Q10.5`, `JP13.3` | raw VBUS |
| `+VBUS_LV` | `Q6.1` (source), `U3.19` (VBUS_LV), `U4.26/27` (**TPS26750 VBUS pins**), `D9.1` | TPS26750 VBUS sense rail |
| `/USB/EPR_BLK_G` | `U3.17`, `R25.2`, `JP2.1` | TPD4S480 blocking-FET gate driver |
| `/USB/VBUS_LV_GATE` | `Q6.2` (gate), `R25.1`, `JP2.2`, `JP3.1` | Q6 gate |
| `/USB-PD/EPR_EN` | `U4.7` (**TPS26750 GPIO2**), `U3.16` (TPD4S480 EPR_EN) | EPR divider enable |

TPD4S480 behaviour (datasheet §6.3.4): asserting `EPR_EN` (or VBUS rising past
`EPR_THRESH_R` ≈ 23–24 V) makes `VBUS_LV = 0.42 × VBUS` and **disables the
`EPR_BLK_G` gate driver**, turning the external blocking NFET `Q6` **off** so
`+VBUS_LV` is isolated from raw `+VBUS`. The TPS26750's IO config maps GPIO2 to
event 92 `VBUS_SENSE_DIVIDER`, i.e. it asserts `EPR_EN` itself when entering EPR.

Jumper state matters here: `JP2` is a **normally-open** 2-pad jumper between
`EPR_BLK_G` and the Q6 gate, and `JP3` is **normally-closed** to the `D8`/`D9`
(18 V zener) network. So Q6's gate is not on the straight TPD4S480 driver unless
`JP2` is bridged — the gate network is a rework area and must be checked against
the TPD4S480 reference before EPR is trusted.

Rails that can brown the MCU out:

* `U11` (**LMR16006X**, 3V3 buck; `L2` → `+3V3`) — input `Net-(JP13-C)` selects
  `VPP`/`+VBUS` via `JP13`, and its `~SHDN` can be driven by **TPS26750 GPIO6**
  (`/LV-Supply/3V3_EN_PD`, `U4.31`) through `JP16` (1–2 = always on, 2–3 = PD
  controlled).
* `U13` (second LMR16006X) and `U5` (LM2765 → `+6V6_LDO` for the `U8` LTC7004
  gate driver) feed the high-side power path (`Q10`) that makes
  `+Converter/PWR_UNREG_IN` for the LT8390.

### MAX action (highest PDO) and fixed-vs-AVS preference

A 240 W source that advertises **fixed 28/36/48 V EPR *and* an EPR AVS APDO**
exposed a chooser bug: `choose()` preferred AVS whenever an EPR AVS APDO was
visible, and every AVS request resolved to 20 V (`avs=true … maxV=27950` →
`PD contract: 20000 mV`), so no EPR preset worked on that charger.

* `choose()` now prefers the **fixed** EPR path whenever the source advertises a
  fixed EPR PDO (AVS is kept only for AVS-only sources).
* **BTN2 in Manual = MAX**: ignores the preset and asks for the highest rail the
  source offers. `auto_track::choose_highest()` picks the highest fixed PDO
  (declared EPR rails injected pre-entry), and `negotiate()` issues it through
  `request_fixed_epr_profile()` — the wide `[15 V, 51 V]` + ≥140 W request, so
  the controller lands on the highest-power EPR PDO (48 V on a 240 W source,
  28 V on a 140 W one). The footer shows `MAX`.
* A specific EPR preset uses the new `request_epr_rail_fixed()`: same ≥140 W
  forcing but the window's upper bound is narrowed to `target +5 %`. That variant
  has not been bench-verified yet; MAX is the known-good path if a targeted
  preset does not land.

**Window floor must stay SPR-inclusive.** Field-verified: an EPR fixed request
whose window excludes the whole SPR set (`[26.6 V, 29.4 V]`) falls back to 5 V,
even though the 28 V EPR PDO is comfortably inside it. The controller only seems
to escalate to an EPR PDO when the window still contains an SPR PDO to consider;
the ≥140 W requirement is then what rules every SPR choice out. Both EPR windows
therefore use a **5 V floor**:
`request_fixed_epr_profile` = `[5 V, 51 V]` (MAX) and
`request_epr_rail_fixed` = `[5 V, target + 5 %]` (specific preset). This also
matters for a source like the china charger, which in EPR advertises only
5/9/12 V SPR — a 15 V floor would exclude every SPR PDO it has.

### Bench checks for the EPR shutdown

1. Scope `+3V3` (`TP65`/`J4`) through the EPR transition. A dip ⇒ the 3V3 enable
   or input is collapsing, not the PD link.
2. Note `JP16`: if it is on 2–3, move to 1–2 (3V3 always on) and retry. If the
   board survives, GPIO6 de-assert on EPR is the cause.
3. Scope `+VBUS_LV` (`TP9`) and `+VBUS`. `+VBUS_LV` should step *down* to
   ≈0.42 × VBUS (≈11.8 V at 28 V), never to 0 V.
4. Scope `+Converter/PWR_UNREG_IN` and `U8`/`Q10` gate — confirm the HV path FETs
   stay on through the transition.
5. Check `JP2`/`JP3` and the `D8`/`D9` gate network against the TPD4S480 EPR
   adapter reference; the E2E failure mode was exactly `EPR_BLK_G` collapsing at
   ~23 V.

Firmware-side hooks if a TPS26750 GPIO is the culprit: the `GPsh`/`GPsl` 4CC
tasks force a GPIO output regardless of its event mapping, so GPIO6 can be held
asserted from boot if the 3V3 enable proves to be the problem.

> Field note: the `TPS config 0x37` line at boot shows the **host-written** value
> that survives an MCU reset, not the EEPROM image. Only a TPS26750 power-cycle
> (or the `0x33` header, which the host never writes) reflects what is loaded.

### Bench checks after this change

* A 28 V confirm should log `PD request: rail=28000 mV` then
  `PD 0x37 now: b0=0x… avs_en=true pps_en=false`, `EPR entered (n EPR PDOs)`,
  `PD contract: 28000 mV`, and `PD AVS keep-alive: 28000 mV` every 7 s.
* A non-EPR source still falls back once via `EPR unavailable: …` and latches SPR.
* PPS presets (12 V on a PPS source) still issue a PPS request.

## Decoding `config_240W_TPS26750_F8091159_epr_pps.json` (the real image)

`*_vif.xml` is only the USB-IF certification descriptor — it has no
0x28/0x29/0x37 content — so it cannot describe the power path. The JSON is the
actual Application Customization project (register numbers are decimal):

* **0x28 Port Configuration** (`[0,8,46,1, 0…,3]` = `0x012e0800`):
  bits 1-0 = 0 → **Sink state machine only** (good); bits 17-16 = 2 → VBUS OVP
  usage 111 %; bits 21-20 = 2 → PP5V OVP 5.8 V; **bits 26-24 = 1 →
  `VBUS Sink UVP Trip HV` = 10 %**, the "VBUS disconnect when power role is
  sink" threshold. A VBUS dip >10 % through the 20→28/48 V EPR transition makes
  the controller drop the sink path; `0h`=5 % … `7h`=50 %, so this is the one
  config-level knob that widens the ride-through (try `3h`=20 %).
* **0x29 Port Control** (`[50,48,128,0]` = `0x00803032`): bits 6/7 = 0 →
  **PR_Swap to Source disabled**, so the VIF's `Requests_PR_Swap_As_Src=true`
  is stale/contradictory and the runtime image is fine here. Bits 4/5 = 1
  (process/initiate swap to sink) are odd on a sink-only port but harmless.
* **0x37** = `b0=0x3e`, byte8 `0x02` (PPS off), byte16 `0x01` (EPR AVS on),
  48 V/5 A, NoCapMismatch set, auto-disable clear — as intended.
* **0x5C IO Config**: byte 38 = 92 → **GPIO2 → event 92 `VBUS_SENSE_DIVIDER`**
  (drives TPD4S480 `EPR_EN`); byte 32 = 4 → **GPIO Event Polarity bit 2 set, so
  GPIO2's event is inverted**. TPD4S480 `EPR_EN` is active-high — verify that
  in the GUI (the chip also auto-enables its divider above ~23 V, which masks an
  inverted enable at 28/48 V). Output-enable = `0xC0F` (GPIO0-3, 10, 11); GPIO6
  has no event and is **not** output-enabled → the 3V3-buck enable comes from
  `JP16` 1–2, consistent with the `GPsh` test not helping.
* **Register 0x27 (39) is written but is not in the TRM register map**
  ("reserved; contents should not be modified") — a GUI artifact, not decodable
  from SLVUCR7.

Firmware now logs the power-path state. The `POWER_PATH_SWITCH` interrupt(bit 23) is **masked** in the app config (INT_MASK1 only enables bits 80/81), so
it never raises the IRQ and the handler never sees it — the register is polled
instead: `POWER_PATH_STATUS` (0x26) is read every 500 ms while a contract is
active and the line

`PD power path: PP5V=… PP_EXT=… VCONN=… b4=0x… contract=… mV vin=… mV`

is printed on every change. For a sink `PP_EXT` should read `3h` (enabled,
system input); `0h` disabled and `1h` disabled **due to fault** is the signature
of "converter input gone while VBUS is still valid".

### Result: the controller opens PP_EXT on the EPR request

```
0.24   contract=12000  PP5V=0 PP_EXT=3  vin=12000   external path enabled
8.80   PD request: rail=28000 mV (EPR, maxV=29400, b0=0x02)
10.79  contract=20000  PP5V=0 PP_EXT=0  vin=20000   external path DISABLED
11.12  vin=4405                                      converter input collapsed
```

`PP_EXT = 0h` is a **normal disable, not a fault** (`1h` would be faulted), so
the controller chooses to open the high-voltage path when it issues the EPR
request and does not re-close it. The converter then has no input while the
USB-C bus is still at 20 V, and the MCU only survives because the 3V3 buck was
moved onto `+VBUS` (`JP13`).

The most consistent explanation is the `VBUS Sink UVP Trip HV` setting in Port
Configuration (0x28 bits 26-24 = `1h` = 10 %): the controller is negotiating a
28 V EPR contract, the source delivers only 20 V (a ~29 % shortfall), the
disconnect threshold trips and the sink path opens. Raising it to `7h` (50 %)
should let the path ride through and leave the converter on the 20 V the source
actually provides, which is a clean test. The root cause of no-28 V remains the
source: the Anker delivers it, the china charger advertises EPR caps but does not
honour the EPR request.

## Three-source CC comparison (`PD-Captures/new/`)

Decoding the raw PD traffic side by side separates the two failures cleanly.
`EPR_Mode` action is the top byte of its data object (1=Enter, 2=Enter Ack,
3=Enter Succeeded, 4=Enter Failed, 5=Exit); the action-4 data byte is the
reason code.

### Anker 737 — `pd-nitride-nano(anker737)-NEWNEW.sqlite` (works)

```
4.070  EPR_Mode action=1 (Enter)
4.076  EPR_Mode action=2 (Enter Ack)
4.201  EPR_Mode action=3 (Enter Succeeded)
4.221  EPR_Source_Caps   … f4c10800            (28 V/5 A fixed)
4.227  Request  RDO=0x83c7d1f4, PDO=f4c10800   position 8, EPR bit set, 5 A
4.340  VBUS = 28.26 V → holds to the end of the capture
```

The sink requests the **fixed 28 V EPR PDO by position (slot 8)** with the EPR
bit in the RDO. This is the only capture that completes EPR end to end.

### China charger — `pd-nitride-nano(china)-NEW.sqlite` (source refuses EPR)

```
4.011  EPR_Mode action=1 (Enter)
4.018  EPR_Mode action=2 (Enter Ack)
4.069  EPR_Mode action=4 (Enter FAILED), data=0x01   ← source rejects EPR entry
4.089  Request  RDO=0x53c7d1f4  position 5 → 20 V
4.710  Request  RDO=0x33c00000  → 12 V
```

`EPR_Mode action=4` is the **source** refusing to enter EPR before any contract
is requested — this happens ~1 s after plug-in, not at the 28 V request. The
source later emits EPR caps anyway (8.7 s), which is why `source_cap_header`
reports `EPR=1` and the firmware believes it entered EPR, but VBUS never goes
above 20 V. Nothing in the sink can fix a rejected EPR entry.

### 240 W charger — `pd-nitride-nano(240w)-NEW.sqlite` (EPR works, board drops it)

```
3.380  EPR_Mode action=1
3.389  EPR_Mode action=3 (Enter Succeeded)
3.417  EPR_Source_Caps   … f4c10800 | f4410b00 | f4010f00 | f096c0d3  (28/36/48 + AVS)
3.423  Request  RDO=0xb3cf0064, PDO=f096c0d3   → EPR AVS APDO
4.119  VBUS = 47.97 V                            ← 48 V EPR delivered!
4.841  VBUS = 11.99 V                            ← falls back to 12 V
```

This one proves EPR 48 V works at the PD level on this source: VBUS reaches
47.97 V. It then falls back to 12 V, which is the power-path/UVP behaviour
already traced (`PP_EXT` opened, `VBUS Sink UVP Trip HV` = 10 %). So the 240 W
charger is not an EPR-compatibility problem; it is the board's ride-through.

Summary: **china = source rejects EPR entry; 240 W = EPR fine, board drops it;
Anker = full end-to-end success.**

## Menu scroll was confirming the highlighted preset (input bug)

The 240 W capture shows the 48 V EPR contract established (`4.119 VBUS=47.97`)
and then a **PPS request 27 ms later** (`4.146`, RDO `0x63c4b03c`, PDO
`6432a4c1`) followed by a drop to 12 V (`4.841`). On a source with no 12 V fixed
PDO, 12 V is served by PPS — so that request is the firmware confirming **preset
0 (12 V)**, which is what the PD grid wraps to when the encoder is turned past
48 V. Scrolling must not request anything, so the turn was being delivered as a
confirm.

`ui/input.rs` had two defects:

1. `check_button` fired on the **first** pressed sample: it compared against the
   timestamp of the last *release*, which is always older than `DEBOUNCE_MS`. A
   one-poll (5 ms) glitch on the encoder switch therefore fired `EncBtn`.
2. `poll()` wrote `EncTurn` and then let `check_button` **overwrite**
   `last_event` with `EncBtn`, so a rotation that also read the switch as closed
   became a confirm.

Fixed: buttons now require a **continuous press for `DEBOUNCE_MS`** before
firing, and a rotation **defers button sampling to the next poll**, so a turn can
never be delivered as a press. On the PD screen that means scrolling past the EPR
entries only moves the highlight; the preset is requested on a deliberate
encoder-button press.

### Follow-up: the probe was armed by the highlight, not by a request

The encoder-input fix was not the cause. The real one is in `PdManager::poll`:
the `ESrC` EPR gate was driven by `choice` (`wants_epr`), and `choice` follows
`pd_profile_index`. So merely **scrolling the PD highlight onto 28/36/48 V**
started an EPR probe and then a renegotiation, with no confirm:

```
0.236  EPR entered (4 EPR PDOs)     controller auto-negotiated 48 V at boot
0.253  PD contract: 48000 mV
0.255  PP_EXT=3 … vin=48000         power path fine at 48 V
0.256  PD request: rail=12000 … pps=true   firmware boot request drops it to 12 V
2.216  EPR exited; SPR PDOs restored
7.660  EPR probe (ESrC) ok=true     ← only scrolled, no `PD confirm`
7.764  PD request: rail=28000 mV
9.750  PP_EXT=0 … vin=4409          path off
```

Fixed: a `request_armed` flag (`negotiate_pending || renegotiate_request ||
auto_due`) now gates both the `ESrC` probe and `do_negotiate`, and a confirm is
kept armed while EPR entry is in flight so the probe timeout can still fire.
Moving the highlight no longer probes or renegotiates; the rail is requested only
on an encoder-button confirm (or an Auto re-plan).

Two observations from the same log, still open:

* The controller's own boot auto-negotiation reaches **48 V with the power path
  fine** (`PP_EXT=3`). The firmware then immediately overrides it with the
  boot preset (index 0 = 12 V, served by PPS), which exits EPR. If the board
  should keep the source's high rail at boot, the boot request itself needs
  revisiting (e.g. don't override, or restore a saved rail).
* A confirmed, **targeted** 28 V request on the 240 W still settles at 20 V and
  leaves `PP_EXT=0`, whereas that source's own auto-negotiated 48 V holds. So
  targeted fixed-EPR selection remains suspect on this controller; the wide/MAX
  path and the controller's own AVS selection are the two that have worked.

### MAX now uses the controller's own auto-negotiate

On the 240 W source, every **host-window** EPR request — targeted fixed
(`maxV=29400`) and EPR AVS (`maxV=27950`) alike — settles at 20 V and leaves
`PP_EXT=0`. The only thing observed to reach the high rail on that source is the
**controller's own auto-negotiation** from the application config
(`b0=0x3e`: auto-computed range, EPR AVS enabled, PPS off), which reached 48 V
with `PP_EXT=3` at boot.

So the MAX action (`BTN2` in Manual mode) now issues
`request_max_rail()`: the same auto-compute + `avs_en` + PPS-off state, triggered
by the PPS edge. On the 240 W that should reproduce the boot 48 V; on the Anker
(no EPR AVS APDO) it lands on the highest fixed EPR PDO, 28 V.

Specific EPR presets still use the host-window paths, so on an AVS-capable
source they may not reach the requested rail — use MAX there. The `PD request`
log prints `max=true` when the MAX path is taken; if it never appears, BTN2
didn't reach the handler (Auto mode toggles the policy instead).

### MAX reverted, and the boot request no longer clobbers a self-negotiated EPR rail

Field results from the auto-compute MAX (`request_max_rail`, `b0=0x3e`,
`avs_en=true`): **both** sources settled at 20 V —
`rail=28000 … max=true → 20000` on the Anker and `rail=48000 … max=true →
20000` on the 240 W. That is worse than the previous MAX, so `maximize` is back
on `request_fixed_epr_profile()` (wide `[5 V, 51 V]` + ≥140 W, `b0=0x02`,
`avs_en` clear), which is what held 28 V on the Anker.

The 240 W's **only** observed 48 V came from the controller's own power-up
auto-negotiation with the EEPROM config (`b0=0x3e`, `avs_en=true`), when the
TPS26750 had reloaded `0x37` from the EEPROM rather than from a previous host
write. The firmware then destroyed it with the boot preset request. `poll()` now
reads the active contract on first contact and, if it is already above
`SPR_MAX_MV`, keeps it instead of requesting preset 0:

```
PD: controller already in EPR at boot; keeping its rail
```

To see it: power-cycle the TPS26750 (unplug the source/board supply so `0x37`
reloads from the EEPROM), reconnect the 240 W and don't touch the encoder — the
48 V rail should now survive boot.

### MAX confirmed on the Anker; use the boot path on the 240 W

With `maximize` back on `request_fixed_epr_profile()` (wide `[5 V, 51 V]` +
≥140 W, `b0=0x02`, `avs_en` clear), **BTN2 in Manual mode holds 28 V on the
Anker**:

```
PD request: rail=28000 mV … max=true
PD 0x37 now: b0=0x02 avs_en=false pps_en=false maxV=51000 mV
PD contract: 28000 mV @ 5000 mA → vin=28266 mV, steady
```

The same request on the 240 W still settles at 20 V and opens `PP_EXT`
(`contract=20000 … PP_EXT=0 → vin=4407`). That source's only observed 48 V came
from its **own power-up negotiation** when `0x37` was the EEPROM auto-negotiate
config (`b0=0x3e`, `avs_en=true`) rather than a previous host write.

So for the 240 W the reliable route is not MAX but **boot**: power-cycle the
TPS26750 (unplug the source so `0x37` reloads from the EEPROM), reconnect and
leave the encoder alone. The new boot guard keeps that self-negotiated rail:

```
PD: controller already in EPR at boot; keeping its rail
```

Pressing MAX on the 240 W forces a host window, which that source answers with
20 V — so on that charger, don't use MAX; use the boot path. Targeted EPR presets
on AVS-capable sources remain the open limitation.
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

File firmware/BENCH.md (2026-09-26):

# nitride-nano firmware — bench bring-up checklist

Complete these steps **before** enabling full GaN power. Keep a current-limited bench supply on the input.

## 1. Tooling

- [ ] `rustup target add thumbv7em-none-eabihf`
- [ ] probe-rs detects STM32G474CEUx on SWD
- [ ] `cargo build --release` succeeds
- [ ] `defmt-rtt` logs visible (`DEFMT_LOG=info cargo run --release`)

## 2. Clocks & DAC (no power stage)

- [ ] Flash firmware; confirm boot log
- [ ] Measure VREF+ (~3.3 V: the board ties it to +3V3 and the firmware leaves VREFBUF high-Z)
- [ ] Sweep PA4 DAC code 0→4095; log PA0 vs DMM on feedback sense node
- [ ] Sweep PA6 DAC; verify monotonic CC node voltage
- [ ] Verify the CV map against the divider network: the code-0 output is `CV_FB_REF_MV·(1 + R19/R36 + R19/R20)` and the slope is `(R19/R36)·DAC_VREF_MV/DAC_MAX_CODE` per code (`control/dac_cv.rs`, `board::CV_FB_*`). Confirm R19/R20/R36 on the assembled board match ~357k/10k/10k; if not, update those constants.

## 3. ADC scaling

- [ ] Apply known voltages to sense nets (safe low levels)
- [ ] Fit `VOUT_SENSE_NUM`, `VBUS_SENSE_NUM`, `ISENSE_MV_PER_A` in `board.rs`
- [ ] ISMON zero: enable the output with **no load**, set `board::ISENSE_ZERO_MV`
      from the `isense:` log's `raw (XXX mV)` field (do **not** calibrate with the
      converter parked — ISMON is unpowered then; see `analysis/ismon-calibration/`)
- [ ] Verify NTC readings at room temp; adjust `NTC_BETA` / `NTC_R25_OHM`
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

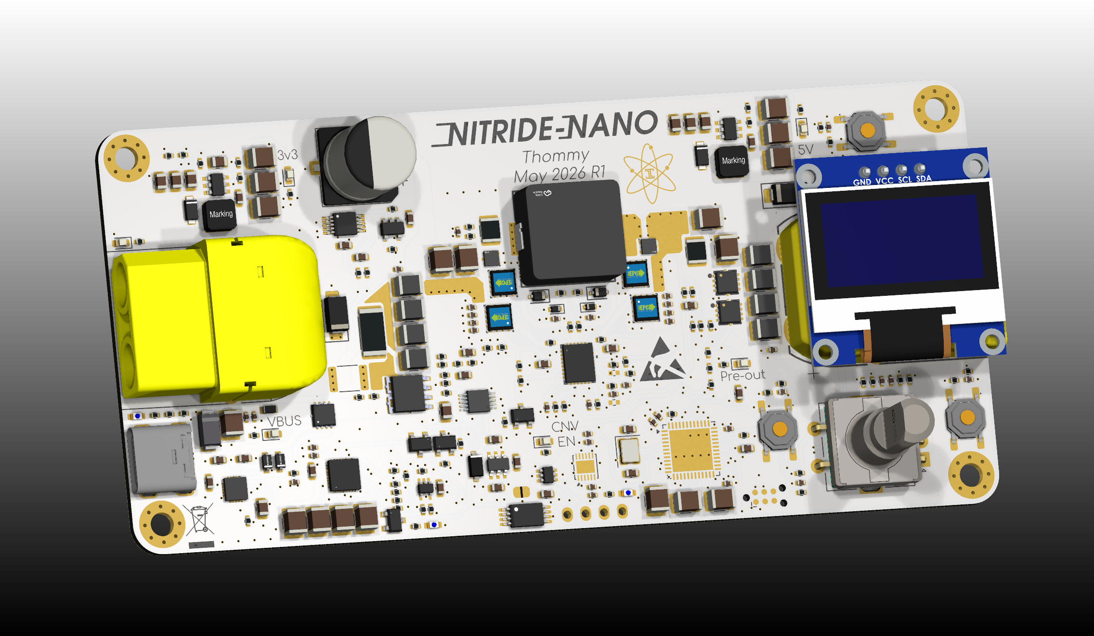
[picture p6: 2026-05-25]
Pics/nitride-nano-f.png

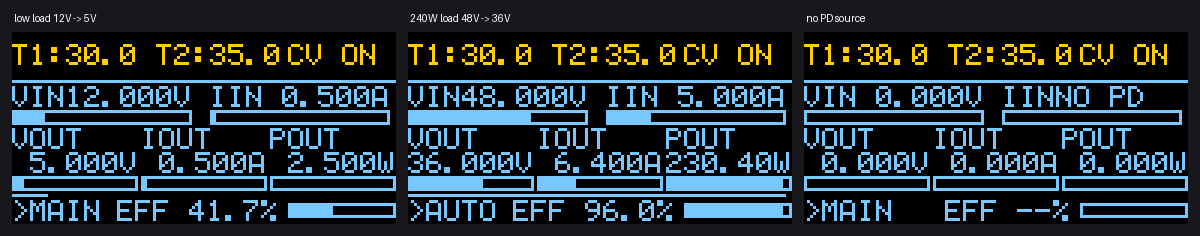
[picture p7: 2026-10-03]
firmware/analysis/oled-layout-mock/main_screen.png

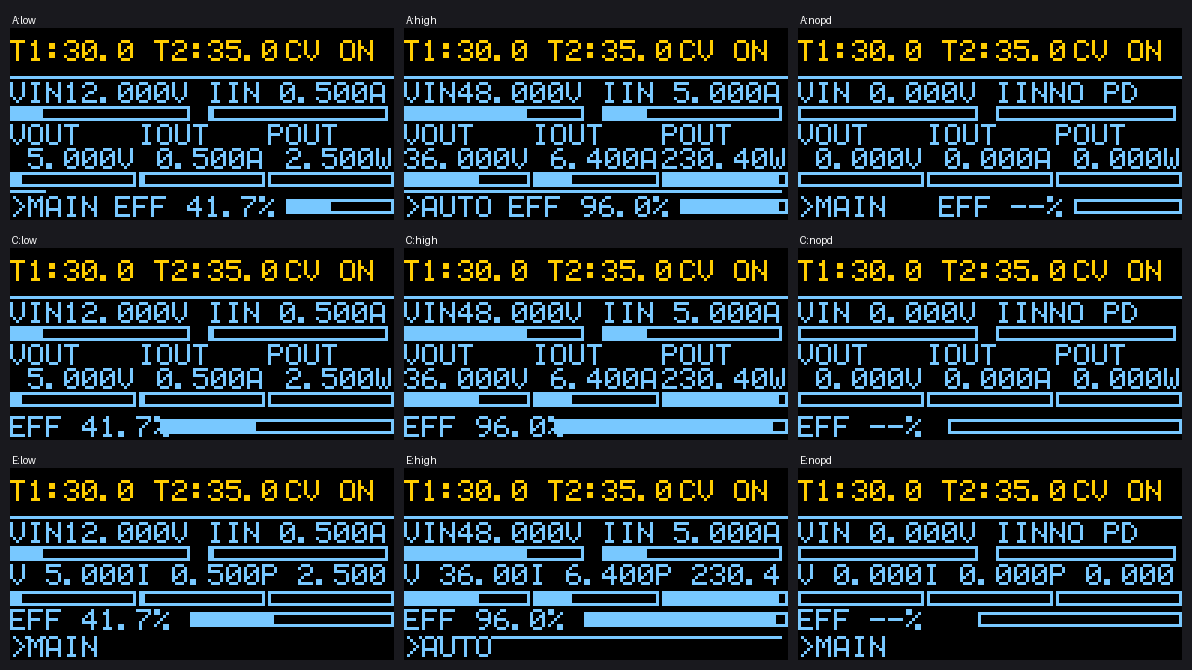
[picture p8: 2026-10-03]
firmware/analysis/oled-layout-mock/comparison.png

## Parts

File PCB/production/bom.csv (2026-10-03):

Designator | Footprint | Quantity | Value | LCSC Part #
C10, C11, C12, C13, C17, C18, C19, C2, C20, C23, C24, C29, C6, C65, C67, C68, C69, C73, C74, C77, C78, C81, C82, C83, C84, C89 | 0402 | 26 | 100nF | C162178
C14, C7 | CP_Elec_10x12.6 | 2 | 100uF | C3274502
C15, C25, C79, C80 | 0402 | 4 | 1nF | C1523
C16, C28, C66, C70, C8, C9 | 1210 | 6 | 10uF | C5156756
C21, C22 | 0603 | 2 | 1uF | C23829972
C26, C27 | 0402 | 2 | 100pF
C30, C32, C36, C50 | 0402 | 4 | 10n X7R 100V | C527014
C31, C56, C57, C58, C62, C86, C87, C88 | 0805 | 8 | 1u X7R 100V | C5370002
C33, C35, C37, C39, C45, C49, C52, C53, C54, C55, C63, C71, C72, C85, C90 | 0603 | 15 | 100n X7R 100V | C15725
C34 | 1210 | 1 | 4.7u | C913445
C38, C41, C43, C44, C59, C60, C61, C91, C92, C93 | 1210 | 10 | 10u X7R 63V | C437568
C4 | 0402 | 1 | 470nF | C7393859
C40, C42 | 0402 | 2 | 220p X7R 50V | C296710
C46, C47, C48 | 0603 | 3 | 3.3u X5R 25V | C5360803
C5 | 0402 | 1 | 4.7uF | C23733
C51 | 0805 | 1 | 2.2u X7R 100V | C22367838
C75, C76 | 0603 | 2 | 22pF | C1653
D1, D2 | D_SOD-523 | 2 | BZX58550-C5V1X | C3736541
D11 | D_SOD-323 | 1 | BZT52C4V7S | C19077439
D12 | sod-123_270x155135_n | 1 | B0520LW-7-F | C155367
D14, D23 | sod-123fl_305p_260x160x90_n | 2 | MBR1H100SFT3G | C235757
D16, D17 | D_SMA | 2 | SMAJ58A | C19077554
D18, D19, D20, D21, D22, D24, D31 | 0603 | 7 | LED | C2286
D25, D26, D27, D28 | D_SOD-882 | 4 | PMEG3005EL,315 | C282565
D3, D4 | D_SOD-128 | 2 | PMEG6020ETP,115 | C179434
D5, D6 | D_SOD-323 | 2 | BAT46WS | C7502692
D7 | do-214ac_440p_430x250x230_n_p | 1 | SMAJ48A | C41376401
D8, D9 | sod-323_230p_170x125x100_n | 2 | BZT52C18SQ | C2857090
F1, F2 | 2512 | 2 | 20A | C49269483
FB1, FB2, FB3, FB4, FB5, FB6, FB7, FB8 | 1210 | 8 | TBD | C48543473
FB9 | fer_1608_09_n | 1 | BLM18SN220TH1D | C710392
J3 | CONN-TH_XT90PW-M.G.Y | 1 | XT-90-M | C3040689
J6 | CONN-TH_XT90PW-M | 1 | XT90-F | C3040690
JP15 | SolderJumper-2_P1.3mm_Bridged_RoundedPad1.0x1.5mm | 1 | Jumper_2_Bridged
L1 | IND-SMD_L7.5-W7.2-1 | 1 | 2.2uH | C5125746
L2, L3 | SWPA4030S220MT | 2 | 22uH 1A 0.29Ohm | C83472
P1 | USB_C_Receptacle_GCT_USB4105-xx-A_16P_TopMnt_Horizontal | 1 | USB_C_Plug_USB2.0 | C3025063
Q1, Q2, Q3, Q4, Q5 | D1068 | 5 | EPC2367
Q10 | PowerPAKSO-8_127p_513x615x120_n | 1 | SQJB90EP-T1_GE3 | C727731
Q12 | Q_SOT-23 | 1 | AO3400A | C20917
Q13, Q8, Q9 | sot-23-3L_103p_300x130x110_n | 3 | AO3404A | C30010
Q6 | vsonp8_65p_330x330x80_mfg | 1 | AGM612AP | C5349119
Q7 | Q_SOT-23 | 1 | AO3401A | C15127
R1 | 0402 | 1 | 147k 1% | C64171
R10, R11, R13 | 0402 | 3 | 0 | C60485
R100, R20, R30, R33, R36, R48, R49, R53, R61, R62, R63, R64, R67, R69, R71, R74, R87, R88, R89, R90, R91, R92, R94, R97, R99 | 0402 | 25 | 10k | C2906861
R101, R103, R65, R66, R68, R70, R77, R79, R81, R95 | 0402 | 10 | 1k | C106235
R102, R42, R52, R54, R58, R83, R98 | 0402 | 7 | 27R 1% | C138021
R12 | 0402 | 1 | 0 | C25148
R14, R15 | 0402 | 2 | 47 | C25118
R16 | 0402 | 1 | 18k | C25762
R19, R5, R59, R7 | 0402 | 4 | 357k | C27005
R21, R22, R3 | 0402 | 3 | 100k
R23, R24, R78 | 0402 | 3 | 10 | C25077
R25, R80, R82 | 0402 | 3 | 33k 1% | C138003
R28, R38, R39, R40, R43, R44, R46, R47, R6 | 0402 | 9 | 100k | C60491
R31, R32, R34, R35, R41, R50, R57, R72, R84 | 0402 | 9 | 4.7k 1% | C105871
R4, R75, R76 | 0402 | 3 | 75k | C25798
R51, R73 | 0402 | 2 | 10k @25°C | C77131
R60, R96 | 2512 | 2 | 2mR | C41382683
R8 | 0402 | 1 | 64.9k | C26984
R85, R86 | 0402 | 2 | 124k | C36777
R9 | 1206 | 1 | 0.002 | C46635910
R93 | 0402 | 1 | 54.9k 1% | C11626
S1, S2, S3 | SW-SMD_4P-L5.1-W5.1-P3.70-LS6.5-TL-2 | 3 | Tactile Button, 160gf | C318884
SW1 | RotaryEncoder_Alps_EC11E-Switch_Vertical_H20mm | 1 | EC11E15244G1 | C370970
SW2, SW3 | SW_Push_1P1T_NO_CK_KMR2 | 2 | KMR211NGLFS | C221676
U1 | UFD_28_ADI | 1 | LT8390AIUFD-PBF | C673800
U11, U13 | sot6_p95_290x180x110_n | 2 | LMR16006XDDCR | C87080
U12, U9 | vssop10_50p_300x300x110_mfg | 2 | INA228AIDGSR | C2887910
U14 | SOT-23-8 | 1 | INA241A1xDDF
U2 | QFN-48-1EP_7x7mm_P0.5mm_EP5.6x5.6mm | 1 | STM32G474CEUx | C1235412
U3 | wqfn20_40p_300x300x80_tp_170x170_n | 1 | TPD4S480RUKR | C43131250
U4 | qfn32_40p_400x400x100_tp_280x280_mfg | 1 | TPS26750SRSMR | C42166327
U5 | sot236_p95_290x160x110_n | 1 | LM2765 | C140270
U6 | JEDEC_MO-153_AA | 1 | CAT24C512YI-GT3 | C56096
U7 | UQFN-16_1.8x2.6mm_P0.4mm | 1 | TMUX1574RSV | C2673120
U8 | msop_10p_300x490x110_tp168x188_n | 1 | LTC7004x | C690106
Y1 | Crystal_SMD_3225-4Pin_3.2x2.5mm | 1 | 8M | C2682775

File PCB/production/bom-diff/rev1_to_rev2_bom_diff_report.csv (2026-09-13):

LCSC Part # | Action | Rev1 Qty | Rev2 Qty | Delta | Value | Footprint | Refs Added | Refs Removed | Rev2 Refs
C105871 | SAME | 9 | 9 | 0 | 4.7k 1% | 0402 |  |  | R31 R32 R34 R35 R41 R50 R56 R72 R84
C106235 | SAME | 8 | 8 | 0 | 1k | 0402 | R81 | R96 | R65 R66 R68 R70 R77 R79 R81 R95
C11626 | SAME | 1 | 1 | 0 | 54.9k 1% | 0402 |  |  | R93
C1235412 | SAME | 1 | 1 | 0 | STM32G474CEUx | QFN-48-1EP_7x7mm_P0.5mm_EP5.6x5.6mm |  |  | U2
C132158 | SAME | 1 | 1 | 0 | FT234XD | WDFN-12-1EP_3x3mm_P0.45mm_EP1.7x2.5mm |  |  | U12
C137983 | REMOVED (leftover) | 1 | 0 | -1 | 40k | Resistor_SMD:R_0402_1005Metric |  | R19
C138003 | SAME | 4 | 4 | 0 | 33k 1% | 0402 |  |  | R25 R29 R80 R82
C138021 | SAME | 4 | 4 | 0 | 27R 1% | 0402 |  |  | R42 R52 R54 R55
C140270 | SAME | 1 | 1 | 0 | LM2765 | sot236_p95_290x160x110_n |  |  | U5
C1523 | SAME | 4 | 4 | 0 | 1nF | 0402 |  |  | C1 C25 C79 C80
C155367 | SAME | 1 | 1 | 0 | B0520LW-7-F | sod-123_270x155135_n |  |  | D12
C15725 | SAME | 15 | 15 | 0 | 100n X7R 100V | 0603 |  |  | C33 C35 C37 C39 C45 C49 C50 C52 C53 C54 C55 C63 C64 C85 C90
C162178 | INCREASE (order delta) | 26 | 27 | 1 | 100nF | 0402 | C77 |  | C2 C6 C10 C11 C12 C13 C17 C18 C19 C20 C23 C24 C29 C65 C67 C68 C69 C71 C72 C73 C74 C77 C78 C81 C82 C83 C84
C1653 | SAME | 2 | 2 | 0 | 22pF | 0603 |  |  | C75 C76
C179434 | NEW (order full qty) | 0 | 2 | 2 | PMEG6020ETP,115 | D_SOD-128 | D3 D4 |  | D3 D4
C1869321 | REMOVED (leftover) | 1 | 0 | -1 | D3V3F4U6S-7 | Altium_port:sot363_sc88_65p_200x125x110_n |  | D11
C19077554 | SAME | 2 | 2 | 0 | SMAJ58A | D_SMA |  |  | D16 D17
C22359236 | SAME | 2 | 2 | 0 | HUASHUO HSBB0115 | PRPAK-8_L3.0-W3.0-P0.65-BL-EP |  |  | Q5 Q12
C22367838 | SAME | 1 | 1 | 0 | 2.2u X7R 100V | 0805 |  |  | C51
C22463848 | REMOVED (leftover) | 1 | 0 | -1 | 1uH | thommys-parts2:IND-SMD_SL1265-101M |  | L1
C2286 | INCREASE (order delta) | 7 | 8 | 1 | LED | 0603 | D30 D31 | D25 | D18 D19 D20 D21 D22 D24 D30 D31
C235757 | SAME | 2 | 2 | 0 | MBR1H100SFT3G | sod-123fl_305p_260x160x90_n |  |  | D14 D23
C23733 | SAME | 1 | 1 | 0 | 4.7uF | 0402 |  |  | C5
C23829972 | SAME | 3 | 3 | 0 | 1uF | 0603 |  |  | C21 C22 C26
C25077 | SAME | 5 | 5 | 0 | 10 | 0402 |  |  | R16 R17 R23 R24 R78
C25104 | SAME | 2 | 2 | 0 | 330R 1% | 0402 |  |  | R45 R58
C25118 | SAME | 2 | 2 | 0 | 47 | 0402 |  |  | R14 R15
C25148 | SAME | 1 | 1 | 0 | 0 | 0402 |  |  | R12
C25165 | SAME | 2 | 2 | 0 | 3.3 | 0402 |  |  | R22 R57
C25762 | SAME | 1 | 1 | 0 | 18k | 0402 |  |  | R2
C25798 | SAME | 1 | 1 | 0 | 75k | 0402 |  |  | R4
C2682775 | SAME | 1 | 1 | 0 | 8M | Crystal_SMD_3225-4Pin_3.2x2.5mm |  |  | Y1
C26984 | SAME | 1 | 1 | 0 | 64.9k | 0402 |  |  | R8
C27005 | INCREASE (order delta) | 2 | 4 | 2 | 357k | 0402 | R5 R19 |  | R5 R7 R19 R59
C282565 | NEW (order full qty) | 0 | 4 | 4 | PMEG3005EL,315 | D_SOD-882 | D25 D26 D27 D28 |  | D25 D26 D27 D28
C2857090 | SAME | 2 | 2 | 0 | BZT52C18SQ | sod-323_230p_170x125x100_n |  |  | D8 D9
C2887910 | SAME | 1 | 1 | 0 | INA228AIDGSR | vssop10_50p_300x300x110_mfg |  |  | U9
C2906861 | INCREASE (order delta) | 24 | 28 | 4 | 10k | 0402 | R33 R36 R48 R49 |  | R20 R21 R30 R33 R36 R48 R49 R53 R61 R62 R63 R64 R67 R69 R71 R74 R75 R76 R87 R88 R89 R90 R91 R92 R94 R97 R99 R100
C296710 | SAME | 2 | 2 | 0 | 220p X7R 50V | 0402 |  |  | C40 C42
C2977282 | REMOVED (leftover) | 1 | 0 | -1 | DX07S024JJ2R1300 | Altium_port:DX07S024JJ2R1300 |  | J1
C30010 | SAME | 4 | 4 | 0 | AO3404A | sot-23-3L_103p_300x130x110_n |  |  | Q8 Q9 Q11 Q13
C3025063 | NEW (order full qty) | 0 | 1 | 1 | USB_C_Plug_USB2.0 | USB_C_Receptacle_GCT_USB4105-xx-A_16P_TopMnt_Horizontal | P1 |  | P1
C3040689 | SAME | 1 | 1 | 0 | XT-90-M | CONN-TH_XT90PW-M.G.Y |  |  | J3
C3040690 | SAME | 1 | 1 | 0 | XT90-F | CONN-TH_XT90PW-M |  |  | J6
C318884 | SAME | 3 | 3 | 0 | Tactile Button, 160gf | SW-SMD_4P-L5.1-W5.1-P3.70-LS6.5-TL-2 |  |  | S1 S2 S3
C3274502 | INCREASE (order delta) | 1 | 2 | 1 | 100uF | CP_Elec_10x12.6 | C14 |  | C7 C14
C36777 | DECREASE (leftover) | 3 | 2 | -1 | 124k | 0402 |  | R5 | R85 R86
C370970 | SAME | 1 | 1 | 0 | EC11E15244G1 | RotaryEncoder_Alps_EC11E-Switch_Vertical_H20mm |  |  | SW1
C3736541 | NEW (order full qty) | 0 | 2 | 2 | BZX58550-C5V1X | D_SOD-523 | D1 D2 |  | D1 D2
C41376401 | SAME | 1 | 1 | 0 | SMAJ48A | do-214ac_440p_430x250x230_n_p |  |  | D7
C42166327 | SAME | 1 | 1 | 0 | TPS26750SRSMR | qfn32_40p_400x400x100_tp_280x280_mfg |  |  | U4
C42237120 | REMOVED (leftover) | 2 | 0 | -2 | PMEG6020EPA,115 | thommys-parts2:DFN2020-3_L2.0-W2.0-P0.65-BR-1 |  | D3 D4
C43131250 | SAME | 1 | 1 | 0 | TPD4S480RUKR | wqfn20_40p_300x300x80_tp_170x170_n |  |  | U3
C437568 | SAME | 10 | 10 | 0 | 10u X7R 63V | 1210 |  |  | C38 C41 C43 C44 C59 C60 C61 C91 C92 C93
C460522 | SAME | 1 | 1 | 0 | 74LVC1G08SE-7 | sot353_65p_200x125x110_mo-203-aa_n |  |  | U7
C46634461 | SAME | 1 | 1 | 0 | 8mR | 2512 |  |  | R60
C46635910 | SAME | 2 | 2 | 0 | 0.002 | 1206 |  |  | R9 R18
C48543473 | SAME | 8 | 8 | 0 | TBD | 1210 |  |  | FB1 FB2 FB3 FB4 FB5 FB6 FB7 FB8
C49269483 | SAME | 1 | 1 | 0 | 20A | 2512 |  |  | F1
C5125746 | NEW (order full qty) | 0 | 1 | 1 | 2.2uH | IND-SMD_L7.5-W7.2-1 | L1 |  | L1
C5156756 | DECREASE (leftover) | 7 | 6 | -1 | 10uF | 1210 |  | C77 | C8 C9 C16 C28 C66 C70
C527014 | SAME | 3 | 3 | 0 | 10n X7R 100V | 0402 |  |  | C30 C32 C36
C5344742 | DECREASE (leftover) | 3 | 2 | -1 | APTD1608LQBC/D | kingbright_0603_blue |  | D15 | D10 D13
C5349119 | SAME | 1 | 1 | 0 | AGM612AP | vsonp8_65p_330x330x80_mfg |  |  | Q6
C5360803 | SAME | 3 | 3 | 0 | 3.3u X5R 25V | 0603 |  |  | C46 C47 C48
C5370002 | SAME | 8 | 8 | 0 | 1u X7R 100V | 0805 |  |  | C31 C56 C57 C58 C62 C86 C87 C88
C56096 | SAME | 1 | 1 | 0 | CAT24C512YI-GT3 | JEDEC_MO-153_AA |  |  | U6
C60485 | INCREASE (order delta) | 2 | 3 | 1 | 0 | 0402 | R10 |  | R10 R11 R13
C60491 | SAME | 12 | 12 | 0 | 100k | 0402 |  |  | R6 R26 R27 R28 R37 R38 R39 R40 R43 R44 R46 R47
C64171 | SAME | 1 | 1 | 0 | 147k 1% | 0402 |  |  | R1
C673800 | SAME | 1 | 1 | 0 | LT8390AIUFD-PBF | UFD_28_ADI |  |  | U1
C690106 | SAME | 1 | 1 | 0 | LTC7004x | msop_10p_300x490x110_tp168x188_n |  |  | U8
C710392 | SAME | 1 | 1 | 0 | BLM18SN220TH1D | fer_1608_09_n |  |  | FB9
C727731 | SAME | 1 | 1 | 0 | SQJB90EP-T1_GE3 | PowerPAKSO-8_127p_513x615x120_n |  |  | Q10
C7393859 | SAME | 1 | 1 | 0 | 470nF | 0402 |  |  | C4
C7502692 | SAME | 2 | 2 | 0 | BAT46WS | D_SOD-323 |  |  | D5 D6
C77131 | SAME | 2 | 2 | 0 | 10k @25°C | 0402 |  |  | R51 R73
C7836 | SAME | 1 | 1 | 0 | SN74LVC1G17DBVR | sot25_95p_300x280x145_jedec_mo-178-aa_n |  |  | U10
C83472 | SAME | 2 | 2 | 0 | 22uH 1A 0.29Ohm | SWPA4030S220MT |  |  | L2 L3
C87080 | SAME | 2 | 2 | 0 | LMR16006XDDCR | sot6_p95_290x180x110_n |  |  | U11 U13
C913445 | SAME | 1 | 1 | 0 | 4.7u | 1210 |  |  | C34

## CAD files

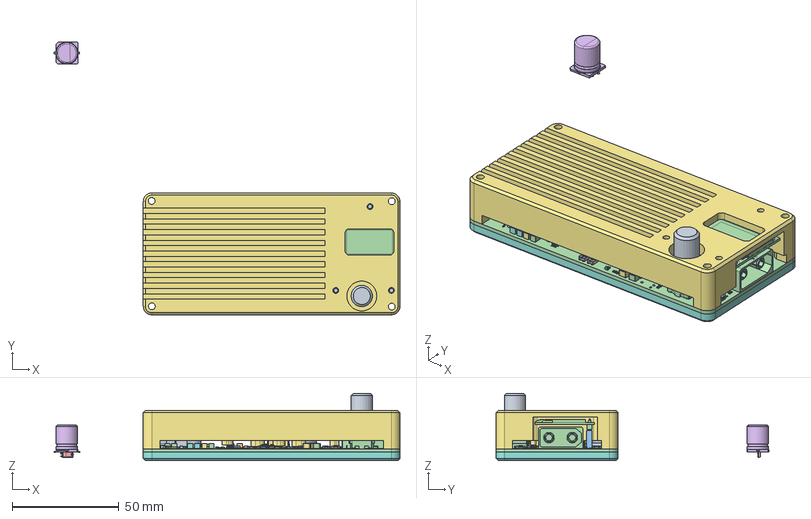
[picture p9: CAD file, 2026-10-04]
Housing/nano-housing_R3.FCStd
161.7 x 127.5 x 31.5 mm
C_0603_1608Metric
C_0402_1005Metric
SOT-23-8
Leader
Leader001
Leader002
Leader003
Leader004
Leader005
R_0402_1005Metric
C_0402_1005Metric002
Leader006
Leader007
Leader008
Leader009
Leader010
Leader011
Leader012
Leader013
Leader014
Leader015
LED_0603_1608Metric
C_0402_1005Metric004
R_0402_1005Metric002
R_0402_1005Metric004
R_0402_1005Metric006
C_0402_1005Metric006
IND-SMD_L11.3-W10.0_XAL1010-332ME
R_0402_1005Metric008
C_0402_1005Metric008
R_0402_1005Metric010
LED_0603_1608Metric002
SW-TH_EC11E15244G1-L11.7-W12.0-H24.5-P2.5-LS14.5
D_SMA
L_1210_3225Metric
C_0603_1608Metric002
C_0402_1005Metric010
D_SMA002
R_0402_1005Metric012
C_0402_1005Metric012
R_0402_1005Metric014
R_0402_1005Metric016
2.5mm
2.5mm001
2.5mm002
2.5mm003
2.5mm004
2.5mm005
2.5mm006
Extrude002 (Mirror #3)
Extrude001 (Mirror #2)
SOT_23
R_0402_1005Metric018
C_0603_1608Metric004
R_0402_1005Metric020
Core
Contact
Contact001
Glue
C_0402_1005Metric014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

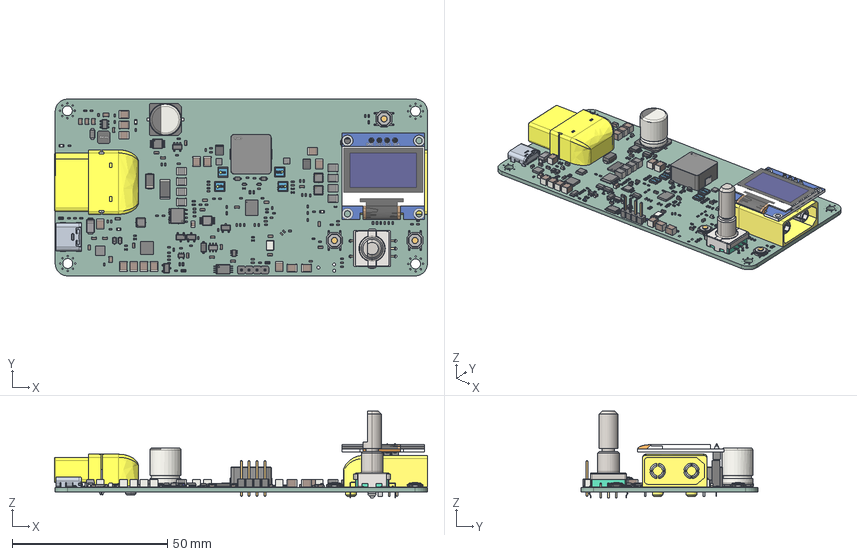
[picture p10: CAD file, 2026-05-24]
nitride-nano.step
120.2 x 57.0 x 28.0 mm
C_0603_1608Metric x 22
C_0402_1005Metric x 38
R_0402_1005Metric x 86
Leader x 40
C_1210_3225Metric x 15
IND-SMD_SL1265-101M
LED_0603_1608Metric x 5
APTD1608LQBCD x 3
APTD1608LQBCD001 x 3
APTD1608LQBCD002 x 3
APTD1608LQBCD003 x 3
APTD1608LQBCD004 x 3
APTD1608LQBCD005 x 3
APTD1608LQBCD006 x 3
APTD1608LQBCD007 x 3
SW-TH_EC11E15244G1-L11.7-W12.0-H24.5-P2.5-LS14.5
D_SMA x 2
L_1210_3225Metric x 8
2.5mm x 4
2.5mm001 x 4
2.5mm002 x 4
2.5mm003 x 4
2.5mm004 x 4
2.5mm005 x 4
2.5mm006 x 4
Extrude002 (Mirror #3) x 4
Extrude001 (Mirror #2) x 4
Core
Contact x 2
Glue
SQJ560EP-T1_GE3
User Library-DO-214AC SMA
User Library-SOD123-1
User Library-SOD323 x 2
C_0805_2012Metric x 6
D_SOD_523 x 2
D_SOD_323 x 2
SW_SPST_TL3342 x 3
DFN2020-3_L2.0-W2.0-P0.65-BR-1 x 2
K3D-DX07S024JJ2-V1_JAE_Proprietary
User Library-SOD-123FL CASE 498
PRT0001 x 2
DNH8
CONN-TH_XT90PW-M
BODY-QFN
FRAME-RUK0020B
PIN1-ID
PinSocket_1x04_P2.54mm_Vertical
(Unsaved)
Crystal_SMD_3225-4Pin_3.2x2.5mm
R_1210_3225Metric x 2
R_2512_6332Metric
CP_Elec_10x126
BODY_MF06A
LEAD_MF06A x 6
CONN-TH_XT90PW-M.G.Y
PinsArrayLR
PCB
Open_CASCADE_STEP_translator_6.8_33.1.1
6130xx11121_PIN x 4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

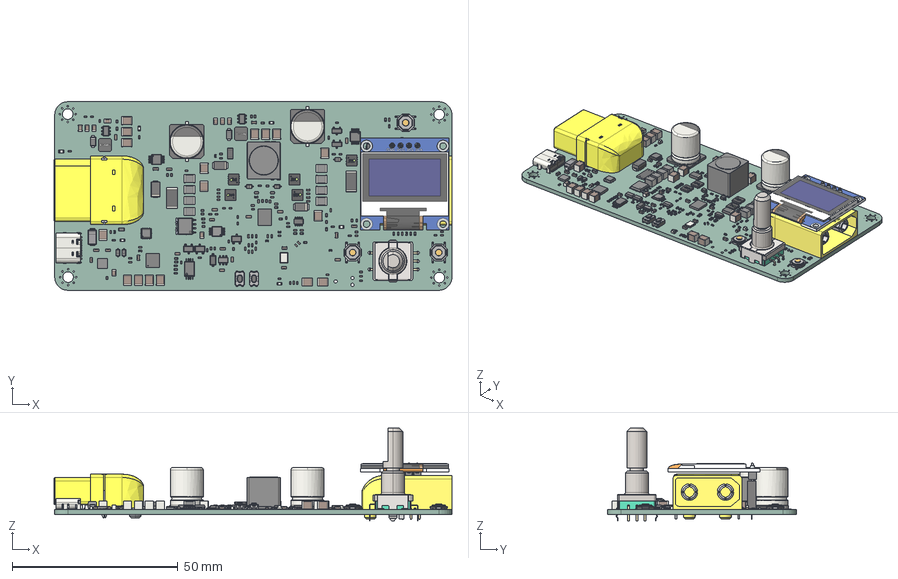
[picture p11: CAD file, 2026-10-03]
PCB/nitride-nano.step
120.2 x 57.0 x 28.0 mm
C_0603_1608Metric x 22
C_0402_1005Metric x 40
SOT-23-8
Leader x 40
R_0402_1005Metric x 90
LED_0603_1608Metric x 7
IND-SMD_L11.3-W10.0_XAL1010-332ME
SW-TH_EC11E15244G1-L11.7-W12.0-H24.5-P2.5-LS14.5
D_SMA x 2
L_1210_3225Metric x 8
2.5mm x 5
2.5mm001 x 5
2.5mm002 x 5
2.5mm003 x 5
2.5mm004 x 5
2.5mm005 x 5
2.5mm006 x 5
Extrude002 (Mirror #3) x 5
Extrude001 (Mirror #2) x 5
SOT_23 x 2
Core x 2
Contact x 4
Glue x 2
SQJ560EP-T1_GE3
User Library-DO-214AC SMA
User Library-SOD123-1
User Library-SOD323 x 2
C_0805_2012Metric x 9
C_1210_3225Metric x 17
CP_Elec_10x126 x 2
SW_Push_1P1T_NO_CK_KMR2 x 2
D_SOD_523 x 2
D_SOD_323 x 3
SW_SPST_TL3342 x 3
D_SOD-128 x 2
User Library-SOD-123FL CASE 498 x 2
DNH8
CONN-TH_XT90PW-M
D_SOD-882 x 4
BODY-QFN
FRAME-RUK0020B
PIN1-ID
PinSocket_1x04_P2.54mm_Vertical
(Unsaved)
Crystal_SMD_3225-4Pin_3.2x2.5mm
R_2512_6332Metric x 2
USB_C_Receptacle_16P_TopMnt_Horizontal_GCT_USB4105-xx-A
BODY_MF06A
LEAD_MF06A x 6
CONN-TH_XT90PW-M.G.Y
PinsArrayLR
R_1206_3216Metric
nitride-nano_PCB

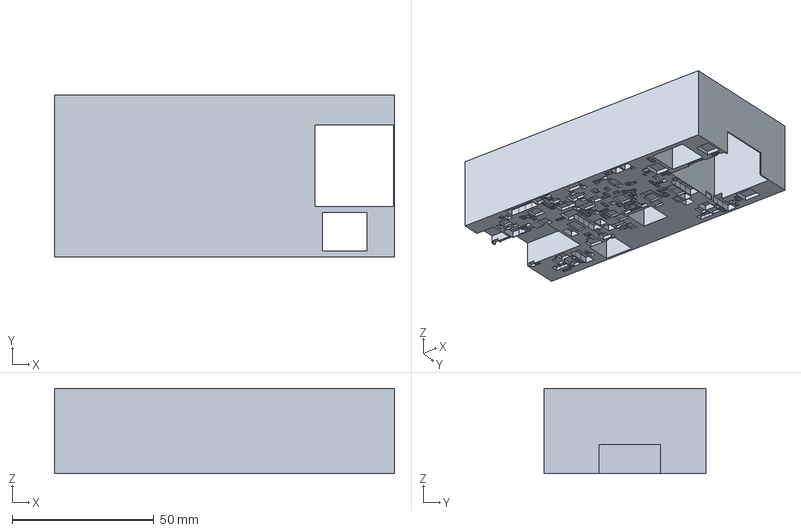
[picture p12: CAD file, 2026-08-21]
Housing/nano-housing_R2.FCStd
120.0 x 57.0 x 30.0 mm

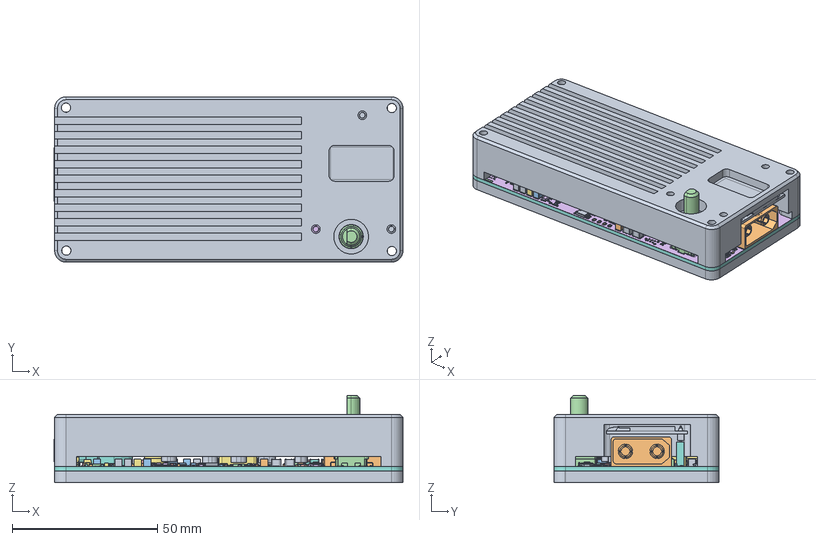
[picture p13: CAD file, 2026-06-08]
Housing/nano-housing.FCStd
120.2 x 57.0 x 30.1 mm
Front
C_0603_1608Metric
C_0402_1005Metric
Leader
Leader001
Leader002
Leader003
Leader004
Leader005
R_0402_1005Metric
C_0402_1005Metric002
Leader006
Leader007
Leader008
Leader009
Leader010
Leader011
Leader012
Leader013
Leader014
Leader015
LED_0603_1608Metric
C_1210_3225Metric
R_0402_1005Metric002
R_0402_1005Metric004
R_0402_1005Metric006
C_0402_1005Metric004
IND-SMD_SL1265-101M
R_0402_1005Metric008
C_0402_1005Metric006
R_0402_1005Metric010
LED_0603_1608Metric002
APTD1608LQBCD
APTD1608LQBCD001
APTD1608LQBCD002
APTD1608LQBCD003
APTD1608LQBCD004
APTD1608LQBCD005
APTD1608LQBCD006
APTD1608LQBCD007
SW-TH_EC11E15244G1-L11.7-W12.0-H24.5-P2.5-LS14.5
D_SMA
L_1210_3225Metric
R_0402_1005Metric012
C_0603_1608Metric002
C_0402_1005Metric008
D_SMA002
R_0402_1005Metric014
C_0402_1005Metric010
R_0402_1005Metric016
2.5mm
2.5mm001
2.5mm002
2.5mm003
2.5mm004
2.5mm005
2.5mm006
Extrude002 (Mirror #3)
Extrude001 (Mirror #2)
R_0402_1005Metric018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

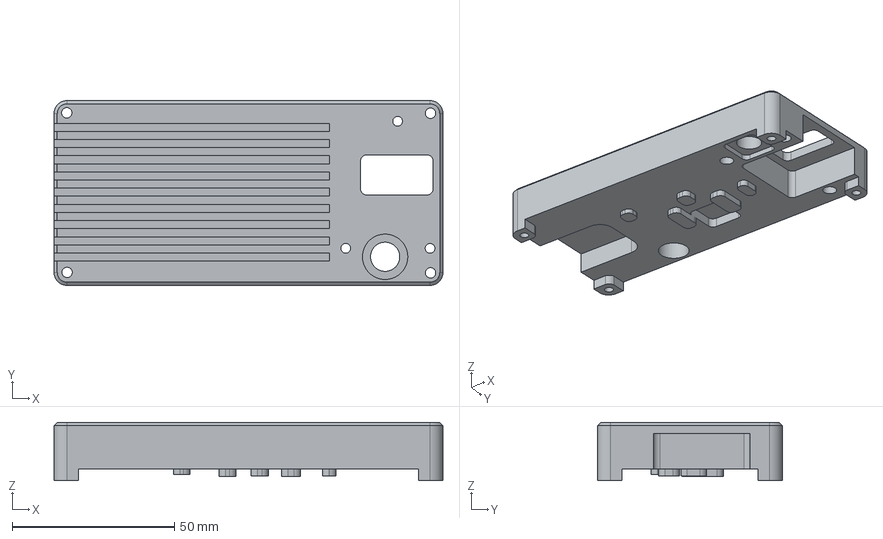
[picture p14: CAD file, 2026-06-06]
Housing/nano-housing-Front.step
120.0 x 57.0 x 18.0 mm

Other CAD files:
.step
Blender files/nitride-nano.blend

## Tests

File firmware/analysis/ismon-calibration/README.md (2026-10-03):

# ISMON (output current) calibration

The OLED `Iout` row comes from the LT8390A's ISP/ISN current monitor on PA3
(`/Converter/ISMON`), not from the INA228 (which is input-side). The chain is:

```
VOUT ── R18 (2 mΩ) ── output ── load
        │  └─ Kelvin to ISP/ISN
        └─ LT8390A:  V_ISMON = 10 · V(ISP−ISN) + V_OFFSET
                     └─ R49 10 k to GND, direct to PA3 (ADC1_IN4)
```

`V_ISMON` full scale is 1.25 V at 100 mV across R18, i.e. **20 mV/A**, and the
offset is the part-specific 0.20–0.30 V in the datasheet. The firmware therefore
has two calibration constants in `src/board.rs`:

| constant | value | meaning |
| --- | --- | --- |
| `ISENSE_MV_PER_A` | 20 | `10 × R18(2 mΩ)`, datasheet gain |
| `ISENSE_ZERO_MV` | 244 (bench) | ISMON voltage at **0 A with the output enabled** |

## Why the old boot learn did not work

The previous firmware learned the zero at boot with the converter parked
(`AdcSense::calibrate_zero`, called before the PD/output bring-up). The LT8390A
powers its ISMON buffer down with the rest of the chip while `EN/UVLO` is low, so
that sample is not the operating offset. It either fell outside the 150–350 mV
plausibility window (rejected, leaving the 250 mV datasheet seed) or captured a
slightly-off value, and either way the board read low by a fixed offset.

Because the current signal is only 20 mV/A, a **5 mV** offset error is **0.25 A**
at *every* load — which is exactly what the bench saw (see below). The learn was
removed and replaced with the explicit, bench-calibrated constant.

## Calibrating a board

1. Power the board and **enable the output with no load connected**.
2. Read the once-per-second RTT diagnostic:

   ```
   isense: raw=NNN (XXX mV) zero=NNN (YYY mV) span=N mV vout=... iout=... ...
   ```

   The `XXX mV` field is the ISMON node voltage measured with the ADC. With no
   load it is the zero, so set `board::ISENSE_ZERO_MV` to that value and rebuild.
   (A DMM on the ISMON node or across R49 gives the same number.)
3. Re-check with a known load: the OLED should now agree within a count or two
   (1 count ≈ 40 mA). If it does not, the gain is off — verify `R18` is really
   2 mΩ and +3V3 (the ADC reference) is really 3.300 V, then adjust
   `ISENSE_MV_PER_A`.

## Bench log — 2026-09-25

With `ISENSE_OFFSET_MV = 250` (the old seed), readings were low by a consistent
offset and the displayed slope was ~0.97, i.e. the gain was right and only the
zero was wrong:

| actual | displayed | error | implied zero |
| ---: | ---: | ---: | ---: |
| 0.25 A | 0.020 A | −0.230 A | 245.2 mV |
| 0.50 A | 0.340 A | −0.160 A | 246.6 mV |
| 1.00 A | 0.520 A | −0.480 A | 240.2 mV |
| 1.50 A | 1.200 A | −0.300 A | 243.8 mV |
| 2.00 A | 1.750 A | −0.250 A | 244.8 mV |
| 2.50 A | 2.200 A | −0.300 A | 243.8 mV |

`fit_ismon.py` turns a table like this into the constant to set:

```sh
python3 analysis/ismon-calibration/fit_ismon.py
python3 analysis/ismon-calibration/fit_ismon.py 0.5,0.34 2.0,1.75 2.5,2.2
```

It reconstructs the raw count behind each displayed value, divides out the
datasheet gain, and reports the mean implied zero (244 mV here) plus the
least-squares gain, so a zero error can be told apart from a gain error.

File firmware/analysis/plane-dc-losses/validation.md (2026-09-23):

# Validation evidence

All runs use the fabricated revision `d705578:PCB/nitride-nano.kicad_pcb`,
70 µm copper (2 oz), 20 °C.

## 1. Independent Gerber geometry check

`gerber_area_check.py` parses the production Gerbers with its own RS-274X reader
(regions, arcs, KiCad `FreePoly` aperture macros incl. rotation and `$n`
arithmetic) and compares total copper area against pcbnew. It shares no code
with the extraction path used by `plane_dc_loss.py`.

```
$ .venv/bin/python gerber_area_check.py
layer      gerber mm²   pcbnew mm²    delta
F.Cu          5277.97      5335.95   -1.09%
In1.Cu        5900.49      5748.04   +2.65%
In2.Cu        6203.16      6082.43   +1.98%
In3.Cu        6022.90      5959.26   +1.07%
In4.Cu        6024.21      5995.86   +0.47%
B.Cu          5876.32      5815.87   +1.04%
PASS (within 3%)
```

The residual 0.5–2.7 % is the Gerber reader's arc/macro approximations, not a
pcbnew extraction error; the four inner layers (where the power pours live) are
within 2.7 %.

## 2. Mesh convergence — `Net-(L1-Pad1)`

```
$ .venv/bin/python plane_dc_loss.py --converge "Net-(L1-Pad1)" --pitch 0.1
pitch=0.2000 mm nodes=   6682 R_eff=0.19617 mΩ
pitch=0.1500 mm nodes=  11744 R_eff=0.19689 mΩ
pitch=0.1000 mm nodes=  25968 R_eff=0.19019 mΩ
pitch=0.0750 mm nodes=  46104 R_eff=0.19503 mΩ
pitch=0.0500 mm nodes= 103248 R_eff=0.19615 mΩ
```

Converged value ≈ 0.196 mΩ. Spread is ±1 % except 0.1 mm, which lands 3 % low —
a grid-alignment artefact at that one pitch, not a trend. 0.05 mm is used for the
production run.

## 3. Mesh convergence — `GND`

```
$ for p in 0.16 0.10 0.07 0.05; do \
    .venv/bin/python plane_dc_loss.py --nets GND --pitch $p; done
pitch=0.250 mm  Iin=0.2235 mΩ  Iout=0.1736 mΩ
pitch=0.175 mm  Iin=0.2285 mΩ  Iout=0.1754 mΩ
pitch=0.125 mm  Iin=0.2298 mΩ  Iout=0.1758 mΩ
```

0.175 → 0.125 mm moves the result by +0.6 % / +0.2 %. GND is run at 0.125 mm
(1.67 M nodes, CG solve, ~530 s).

## 4. Energy balance

For every net and case the solver reports both `P = Σ g·ΔV²` and `P = I·ΔV`; the
`energy check` column in `report.md` is `ok` for all 13 nets. Bus-shorting
conductances are excluded from the loss sum, so the reported power is copper only.

## 5. Bar-model sanity

`R_bar = Rs·ℓ²/A` (ℓ = terminal centroid distance, A = total copper area, all
layers in parallel) is a lower bound that ignores constrictions. The FEM sits
1.0–4.3× above it on the two-terminal nets, which is the expected direction and
magnitude for pours that neck down at thermal-relief spokes and pad clusters.
It is not applied to GND, where a two-terminal bar model is meaningless.

## 6. Connectivity / floating copper

Every net reports a connected path between its terminals. GND reports 164 mm² of
floating copper islands (GND pours not reachable from the converter terminals);
these carry no current and are excluded from the loss, and are reported rather
than silently dropped.

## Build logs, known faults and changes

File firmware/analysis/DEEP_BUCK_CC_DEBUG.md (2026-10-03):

# Deep-buck / CC regulation — debug notes (2026-09-27)

Bench case: **Vset = 13 V, Ilimit = 15 A, load = 2.6 A.**
Observed: OLED `Iout` ≈ 3.23 A (0.63 A high), output ≈ 1.5 V above
setpoint, and at higher load the output “goes into CC” and collapses to ~5 V
even though the programmed limit is 15 A and the input has headroom. The LT8390A
FB pin measured a clean 1.0 V.

This file records what the firmware was actually doing, what was fixed, and how
to read the new console output. Hardware-side notes are flagged as **verify** —
the PCB files are mid-revision, so treat the connectivity below as “what the
committed rev2 files say”.

---

## TL;DR

Four independent firmware effects stack up, and any one of them can look like
“the chip went into CC and the voltage collapsed”:

1. **The CC DAC mapping ignored the CTRL summing network** (R48/R5/R4) — every
   programmed limit came out ~14 % low (15 A → ~13.6 A). *Fixed.*
2. **`SupplyMode::Cc` parked the CV DAC at minimum output.** The LT8390A ORs its
   voltage and current error amps, so the voltage loop won and collapsed the
   output instead of current-limiting it. *Fixed.*
3. **The output current was silently clamped by the input-power budget**
   (`i_power_cap = input_power_cap_mw / vout`), which can be a few amps when the
   PD contract power is low or stale. *Now logged loudly when it binds.*
4. **The software over-current trip used the already-high-biased ISMON at 100 %
   of the limit**, so a load sitting at the limit could false-trip and park the
   output. *Now 115 % + a full-context trip log.*

Plus: the ISMON zero constant was ~4 mV low on this board (see the second-run
update at the end — the no-load measurement is 248 mV), and the
`dac_nom` vs `dac_impl`/`fb_impl` logs tell you whether a setpoint error is the
DAC pin, the feedback network, or the converter failing to regulate.

---

## 1. The CC DAC never drove CTRL directly

**Connectivity (committed rev2 PCB):**

```
PA6 / CC_Set ── R48 (10 k) ──┬── LT8390A CTRL (U1.10)
                             │
LT8390A VREF (2.000 V) ── R5 (357 k)
                             │
                            R4 (75 k)
                             │
                            GND
```

The DAC does **not** sit on CTRL. `control/dac_cc.rs` used to assume
`V_CTRL = 0.02·I + 0.25` (i.e. the DAC voltage *is* the CTRL voltage), which is
only true with no divider. The real network is

```
V_CTRL = k·V_DAC + V_ctrl0,   k = 0.861,  V_ctrl0 = 48 mV
```

so the old code produced `I_actual ≈ 0.861·I_set + 0.68 A`:

| requested | old code | old actual limit | new code | new actual limit |
| ---: | ---: | ---: | ---: | ---: |
| 2.6 A | 374 | 2.89 A | 366 | 2.60 A |
| 15 A | 682 | **13.6 A** | 723 | **15.0 A** |

With the DAC high-Z (MCU in reset) the divider gives `V_CTRL = 347 mV`, i.e. a
**4.9 A** fail-safe limit — that is what R5 = 357 k was changed from 124 k for
(commit `1daf014`), and it is exactly why a stuck/floating CC node looks like a
~2–5 A “mystery CC limit”.

`dac_cc.rs` now inverts the network, and `board.rs` carries the divider
constants (`CTRL_SERIES_OHM`, `CTRL_VREF_OHM`, `CTRL_GND_OHM`, `LT8390_VREF_MV`,
`ISENSE_SHUNT_MOHM`). **If rev3 changes the divider, update those constants or
every CC limit is wrong again.**

CTRL transfer used (datasheet: `V(ISP−ISN) = (V_CTRL − 0.25 V)·0.1` for
0.3 V ≤ V_CTRL ≤ 1.15 V, saturating at 100 mV; R18 = 2 mΩ):

```
I_LIMIT(mA) = (V_CTRL(mV) − 250) · 100 / R18_mΩ
```

## 2. CC mode collapsed the output by fighting the hardware

The LT8390A diodes-ORs the FB error amp (regulate FB to 1 V) and the ISP/ISN
current error amp (regulate to the CTRL threshold) into VC; the **lower** of the
two wins. `SupplyMode::Cc` used to park the CV DAC at code 4095 — minimum output
on the inverted map — while setting the CC limit. The voltage loop therefore
demanded a *lower* VC than the current loop, so the output collapsed to the
minimum instead of limiting current.

`SupplyMode::Cc` now programs the CV DAC from `v_set_mv` exactly like CV mode, so
the chip is free to transition CV↔CC itself. In practice **CV and CC modes are
now functionally identical** (both are “CV with a CC ceiling”); the LT8390A
decides the active loop. The OLED badge now shows the *detected* loop
(`cc_active`), not the user’s mode selection.

`Btn2` on the Main screen still selects the mode; if you were pressing it to try
to “get to CC”, that alone could reproduce the collapse on the old firmware.

## 3. Output current clamped by the input-power budget

`control/supply.rs` limits output current to

```
i_limit = min(i_set, input_power_cap_mw · 1000 / vout_measured)
```

`input_power_cap_mw` is refreshed from the active PD contract
(`pd/manager.rs`: `v_mv · i_ma / 1000`). A low or stale contract (e.g. 40 W)
therefore caps the output at `40 W / 13 V ≈ 3 A` **regardless of the 15 A on the
CC screen**, and the converter then current-limits and the voltage sags — exactly
“plenty of input power, but it collapses”. A `supply: OUTPUT CURRENT LIMITED BY
INPUT POWER CAP` warning is now emitted the moment this becomes the binding
limit, with the contract numbers.

If you hit that warning but the source really can deliver more, the problem is
the negotiated contract / auto-track rail, not the converter.

## 4. Software OC trip

`SupplyMode::Cv` latched `Fault::OverCurrent` the instant the *filtered* ISMON
reading exceeded `i_limit`. With the ISMON reading ~0.6 A high and `i_limit`
clamped by item 3, a normal 2.6 A load could trip and park the output. The trip
now needs `iout > i_limit · 115 %` (`board::IOUT_TRIP_MARGIN_PCT`) and logs the
full context (measured current, limit, Vout, Vset, CC code and its estimated
limit) so a real over-current is distinguishable from measurement bias.

## 5. ISMON: the high reading is a zero offset

Firmware chain: `ISENSE_ZERO_MV` → `zero_raw = ISENSE_ZERO_MV·4096/3300`,
`iout_mA = (raw − zero)·3300·1000/(4096·20)`, i.e. **1 count ≈ 0.806 mV ≈ 40 mA**.

The first report's 3.23 A reading at 2.6 A implies `raw ≈ 382` → node ≈
**307.9 mV**; subtracting the `2.6 A · 20 mV/A = 52 mV` signal gives an implied
zero of **256 mV**. The second run's *no-load* measurement (output on, 0 A) read
raw 307–308 = **247–248 mV**, so the fitted constant is now **248 mV**:

```
zero 244 mV → ~0.24 A at no load (first-run constant)
zero 248 mV → ~0.00 A at no load (fitted from the 2026-09-27 run)
zero 256 mV → the *loaded* inference, ~10 mV above the no-load point
```

The gap between the 248 mV no-load zero and the 256 mV loaded inference is the
**intermittency**: the LT8390A ISMON offset is only specified 0.20–0.30 V (a
±2.5 A spread), is part-specific, and moves with temperature/operating point, so
a single fixed constant cannot track it across all conditions.

Recalibrate with the output **enabled and no load** (the buffer is powered down
when EN/UVLO is low): read the new `isense: raw=… (XXX mV)` line and set
`ISENSE_ZERO_MV` to `XXX`.

The new `isense` line also prints `raw_i` (single sample) next to `filt_i` (the
median+EMA value). If `raw_i` jumps around while `filt_i` is steady, the error is
switching ripple on a single sample, not a scaling error.

## 6. The 1.5 V setpoint error

FB is at a clean 1.0 V, so with the nominal R19/R20/R36 the only free variable is
the **DAC pin voltage**: +1.5 V at the output needs the DAC pin ~42 mV *below*
`VREF·code/4095`. The new `supply[meas]` line prints both:

* `dac_nom` — `VREF·code/4095` (what the firmware assumes), and
* `dac_impl` — the DAC-pin voltage implied by the *measured* Vout, assuming
  FB = 1 V and the nominal divider.

For 13 V / code 2065 → `dac_nom ≈ 1664 mV`; a 14.5 V output implies
`dac_impl ≈ 1621 mV`. A persistent 40+ mV gap means the DAC pin/reference is not
what the map assumes (check +3V3 / VREF+ with a DMM, and the DAC channel is
configured `NormalExternalBuffered` in embassy, so it is not a loading problem).
If `dac_nom ≈ dac_impl` but Vout ≠ setpoint, the feedback resistor values on the
board differ from `board::CV_FB_*`.

## 7. Verify: converter-disable pin (PA11 vs PB1)

The firmware drives **PA11** for the converter disable (`hal/converter_enable.rs`,
`main.rs`). The committed rev2 PCB routes the Q13 gate / LT8390A `EN/UVLO`
disable to **PB1 (U2 pin 18) → R78 (10 Ω) → Q13 gate**, with R79 (1 k) pulling
that gate to +3V3. PA11 in that same file is `USB_D_N` → TPD4S480 (U3.14).

**Verify which pin your board’s Q13 gate actually follows.** If it is PB1, then
`en.set_enabled(false)` is a no-op and all software shutdown relies on parking
the DACs (CV → min, CC → code 0, which holds CTRL below the 300 mV latch-off).
That still stops the stage, but the hardware disable path is not being driven.

---

## New console output

One-time at boot:

```
boot: conv-disable pin PA11 (active_high=…), CV dac PA4, CC dac PA6
boot: cv map: code0 -> 72400 mV, code4095 -> … mV (VREF 3300 mV, R19 … R20 … R36 …)
boot: cc ctrl net R48=10000 R5=357000 R4=75000 VREF=2000 mV: 15A -> code 723 (ctrl 550 mV, est 15000 mA); code0 ctrl 48 mV (latchoff 300 mV)
boot: iout software trip margin 115%; supply snapshot every 1000 ms
```

Once per second from the supply tick (grep `supply[`):

```
supply[ctl]:  mode=… en=… fault=… vset=… iset=… cv_code=… map_vout=… cc_code=… ctrl_mv=… cc_est=…
supply[lim]:  i_cap=… p_cap=… i_power_cap=… i_limit=… power_clamped=… cc_active=…
supply[meas]: vout=… iout=… verr=… vin=… iin=… pin=… dac_nom=… dac_impl=…
```

Edge-triggered:

```
supply: state change mode=… en=… fault=… …
supply: OUTPUT CURRENT LIMITED BY INPUT POWER CAP: iset=… clamped to i_limit=… (p_cap=… / vout=…)
supply: hardware CC transition: vout=… below vset=… at iout=… (i_limit=… cc_code=… ctrl_mv=… cc_est=…)
Fault::OverCurrent SOFTWARE trip: iout=… > i_limit=… (115% margin) …
Fault::… (existing fault lines, unchanged)
```

Once per second from the ADC loop (extended):

```
isense: raw=… (… mV) zero=… (… mV) span=… mV raw_i=… mA filt_i=… mA vout=… mV vset=… mV iset=… mA vin=… mV iin=… mA
```

### How to read the collapse

| What you see | Meaning |
| --- | --- |
| `supply: OUTPUT CURRENT LIMITED BY INPUT POWER CAP` | firmware clamped `i_set` by the PD contract power — not the LT8390A |
| `supply[ctl]: … mode=CC` on old firmware | the CC-mode CV park collapsed the output (fixed) |
| `Fault::OverCurrent SOFTWARE trip` | ISMON bias + tight limit false-tripped it |
| `supply: hardware CC transition` | the chip really is current-limiting; check `cc_est` vs `i_set` |
| `vin` ≈ 4400 mV in `supply[meas]` | the documented PD power-path dropout (`analysis/PD_ROOT_CAUSE.md`), not the converter |

---

## Bench procedure

1. **Recalibrate ISMON**: output enabled, no load, set `ISENSE_ZERO_MV` from the
   `isense` line’s `XXX mV`. Re-check at a known load.
2. Note the four `boot:` lines; confirm the CC `15A -> code … ctrl … mV` matches
   the assembled CTRL divider.
3. Enable at 13 V / 15 A, no load. Compare `dac_nom` vs `dac_impl`; DMM +3V3 and
   the ISMON/CTRL nodes.
4. Step the load up. Watch for `power_clamped=1`, `cc_active=1`, the CC-warning
   and the OC trip; check `vin`/`iin` against the contract.
5. Press BTN2 (CC mode) and confirm the output now holds its voltage ceiling
   while the badge follows the detected loop.

---

## Update — second bench run (2026-09-27, firmware with the fixes above)

Log: `Vset=13 V`, `Iset=16 A`, PD negotiated **48 V / 5 A EPR** (EPR contract,
`p_cap = 240 W`). The output enabled cleanly and regulated at no load. This run
changes the conclusion: **the firmware is not the limiter this time.**

What the log shows:

* **CC path is correct and not reached.** `cc_code=752 ctrl_mv=570
  cc_est=16000` — the corrected divider inversion is programming exactly 16 A,
  and the collapse happened at `iout ≈ 9 A`, i.e. *below* the limit.
  `cc_active=false` throughout, so the OLED badge correctly showed CV.
* **Power cap is not binding.** `p_cap=240000`, `i_power_cap` 17–45 A,
  `power_clamped=false`. (The 17 k–45 k swings are just `240 W / vout`.)
* **CV at no load is accurate.** 13.25 V measured for a 13.00 V setpoint;
  `dac_nom=1664` vs `dac_impl≈1656` (8 mV). The old +1.5 V is not reproducing at
  no load.
* **The converter is saturating, not current-limiting.** During the collapse
  (`vout≈5.37 V, iout≈9 A, vin≈47.8 V, iin≈1.05 A`), the output power is
  ≈48 W and the input ≈50 W. Computing FB from the measured output and the
  commanded code gives **fb_impl ≈ 895 mV, far below the 1 V reference** — the
  LT8390A is asking for more and cannot deliver it. A current limit would show
  FB ≈ 1 V with the output dragged by the load; this does not.
* The input current ≈1.05 A is *expected*: in buck, `Iin ≈ Iout·D = 9 A × 0.11`.
  It is not a hidden 1 A input limit.
* **ISMON zero is measured.** With the output on and no load PA3 read raw
  307–308 = **247–248 mV**, so `ISENSE_ZERO_MV` is now **248** (was 244); the
  244 constant showed ~200–250 mA at true zero.
* Load operating points were ≈14.0 V/3.3 A and ≈5.4 V/9 A — both ≈47 W, which
  is the signature of a **constant-power** load, not the CC 2.6 A the load was
  set to. Confirm the electronic load's mode.

So the collapse is a *converter* limit at ~50 W / ~9 A in deep buck
(48 V → 5.4 V, D ≈ 0.11), and the new firmware now says so explicitly:

```
supply: OUTPUT OUT OF REGULATION: vout=… mV < 85% of vset=… mV at iout=… mA;
  fb_impl=… mV (ref 1000, <1000 = chip cannot deliver); i_limit=… cc_est=…;
  ctrl_mv=… dac_nom=… dac_impl=…; vin=… iin=… pin=…
```

### Next measurements (hardware, in order)

1. **Electronic load mode.** Set it to a *verified* CC value (or a power
   resistor). The 14 V/3.3 A ↔ 5.4 V/9 A bistability is the classic
   constant-power-load signature and may be the whole story at the load.
2. **Scope FB during the collapse.** Expect ≈0.9 V (saturated) per the log. If
   it is ≈1 V, the output is being dragged by the load and the converter is
   fine.
3. **DMM the output under load.** If the DMM reads ~13 V while the OLED says
   ~14 V, the +1 V is ADC/ground-referred telemetry error, not regulation.
4. **DMM/scope the CTRL pin** during the collapse. The firmware intends 570 mV;
   if it measures ≈430 mV the real output current limit is ≈9 A and the CTRL
   divider/DAC path is still off. `TP13` is on `CC_Set`; the CTRL side is
   R48 pad 2.
5. **Check the deep-buck current sense.** The inductor peak limit is 50 mV /
   R9(2 mΩ) = 25 A, so it is *not* the intended limiter, but at D ≈ 0.11 the
   on-time is only ~280 ns and the LSP/LSN leading-edge spike can false-trip the
   peak-current comparator. Scope `SW1`/`SW2` and LSP–LSN across C25 (with
   R14/R15 = 47 Ω, τ ≈ 47 ns) and try a larger filter if the spike dominates.
6. **Retest at a lower input rail** (e.g. 24 V). If the collapse point moves,
   it is a duty-cycle/deep-buck sensing effect rather than a hard current limit.

---

## Update 2 — third bench run (2026-09-27): 48 V vs 28 V, and the verdict

Two runs, same firmware, same 12 V setpoint, load verified in **CC**:

| input | result |
| --- | --- |
| **48 V EPR** (VIN/VOUT ≈ 4.0) | held to ~5 A / ~68 W, then sagged and "chittered"; CC limit 11 A never reached |
| **28 V** (VIN/VOUT ≈ 2.3) | reached the programmed **10 A CC limit** (`hardware CC transition … iout=9974 mA, cc_est=10000 mA`) at ~115 W |

### What this proves

* **The firmware CV/CC path is now correct and validated.** At 28 V the
  converter current-limited at 9974 mA against a 10 000 mA command — the
  corrected CTRL-network mapping in `dac_cc.rs` is right to well under 1 %.
  `fb_impl` sat at 1003–1005 mV (the chip regulating) right up to the limit.
* **The power stage, FETs, inductor, output shunt and the whole sense chain are
  healthy** — they deliver 115 W at 28 V.
* **The failure is purely the high-step-down corner.** It moves with input
  voltage, exactly as a duty-cycle / switching-frequency / current-sense
  limitation does, not with the setpoint or the limit.

### Why 48 V→12 V is the weak corner

* **R1 = 147 k ⇒ fOSC = 1.0 MHz** ([LT8390A datasheet Table 1](https://www.farnell.com/datasheets/2311639.pdf)).
* At 1 MHz the on-time at 48 V→12 V (D≈0.25) is ~250 ns; the LT8390A's
  TG1 minimum duty in buck region is 10 % (~100 ns), so the duty itself is
  legal, but the margin for current-sense leading-edge blanking / filter delay
  is small.
* L = 2.2 µH at 1 MHz gives ΔIL ≈ 4.1 A pk-pk at 48 V→12 V (vs ≈3.1 A at
  28 V→12 V), so the LSP/LSN sensed ramp is small (≈8 mV) relative to a
  high-VIN switching spike, and R14/R15/C25 = 47 Ω/47 Ω/1 nF is only τ≈47 ns.
* The datasheet's own product table rates the 2 MHz **LT8390A** at
  **"50 W+"**, where the 650 kHz **LT8390** is **"450 W+"** — i.e. this part is
  optimised for small size at moderate power, and the board is pushing it.

### Fixes, cheapest first

1. **Use the lowest clean PD rail, not 48 V.** For a 12 V output anything
   ≥16.2 V is a clean buck; ~20 V (`VIN/VOUT ≈ 1.67`) is the sweet spot and was
   available in both runs. `control::auto_track` already implements exactly this
   ("gentlest step-down" in Efficiency policy) — the 48 V runs happened because
   the controller was left on its boot-negotiated 48 V rail. **Switching the PD
   screen to Auto, or just selecting the 20 V preset, is a one-button test that
   should recover full current.** The new `supply: DEEP-BUCK OPERATING POINT`
   warning tells you when you are in the marginal corner.
2. **Hardware, only if 48 V→12 V is a requirement:** increase the LSP/LSN filter
   (R14/R15 → 100 Ω and/or C25 → 2.2 nF), increase L (2.2 → 3.3–4.7 µH), and/or
   drop fOSC to 0.6–0.8 MHz (RT 267 k / 191 k) for more on-time margin. Scope
   SW1/SW2 and LSP−LSN first to confirm the leading-edge spike.

### The residual output error

* **Fixed +0.4 V**: the no-load output was 12.4 V (DMM-verified) for a 12.000 V
  setpoint, `fb_impl` ≈ 1003 mV. That is a fixed open-loop calibration error in
  the DAC/reference/FB-divider chain (a few mV at the DAC pin ≈ 0.4 V at the
  output). It is trimmable in firmware with a CV gain/offset calibration.
* **Load-dependent ~+0.6 V at 48 V** (13.0 V at 5 A) vs **~0.05 V at 28 V**
  (12.45 V at 4 A). Since a fixed DAC and a fixed FB network cannot produce a
  load-dependent output, either the FB regulation point shifts in the marginal
  48 V corner (likely, given `fb_impl` rose 1003 → 1014) or the ADC reading
  rises under load. **DMM the output at the load terminals while loaded** to
  settle it: if the DMM says 12.4 V, it is telemetry; if it says 13.0 V, it is
  the 48 V operating corner again.

### Recommended next tests (in order)

1. **20 V rail, 12 V out, load to 10 A** — confirms the fix and that the CC
   limit holds. Highest information per minute.
2. **Scope SW1/SW2 + LSP−LSN at 48 V near the collapse** — pulse-skipping,
   minimum-on-time, subharmonic oscillation or leading-edge false-trips.
3. **DMM the output under load** — resolves the +1 V.
4. No need to re-test the CTRL pin: the 28 V CC transition at 9974 mA already
   validated it.

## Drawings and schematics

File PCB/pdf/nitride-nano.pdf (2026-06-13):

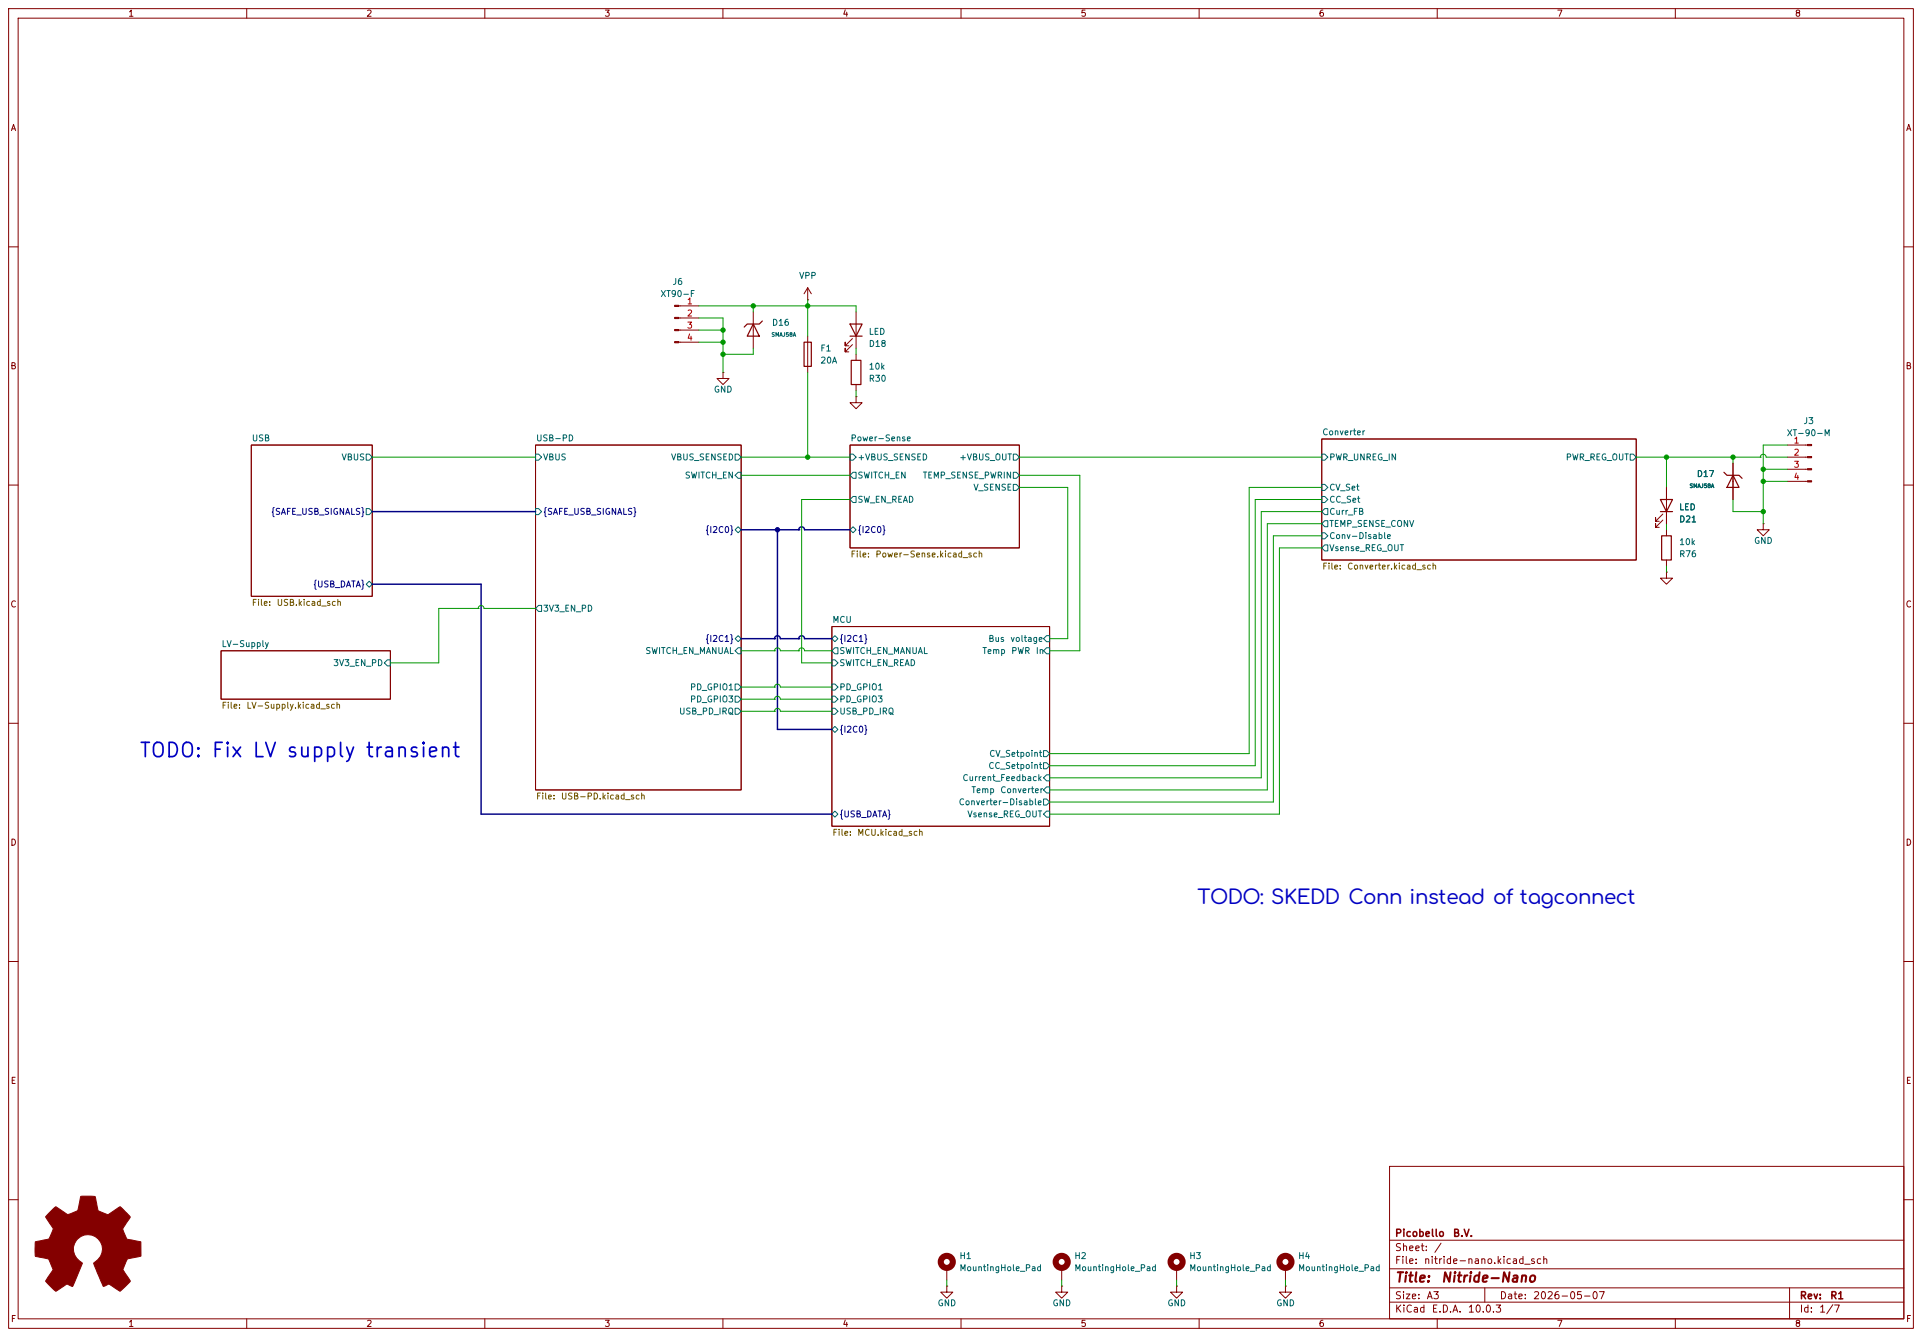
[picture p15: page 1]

LV-Supply File: LV-Supply.kicad_sch

TODO: Fix LV supply transient

Temp Converter Converter-Disable

TODO: SKEDD Conn instead of tagconnect

Size: A3 | Rev: R1
KiCad E.D.A. 10.0.3 | Id: 1/7 | F Date: 2026-05-07

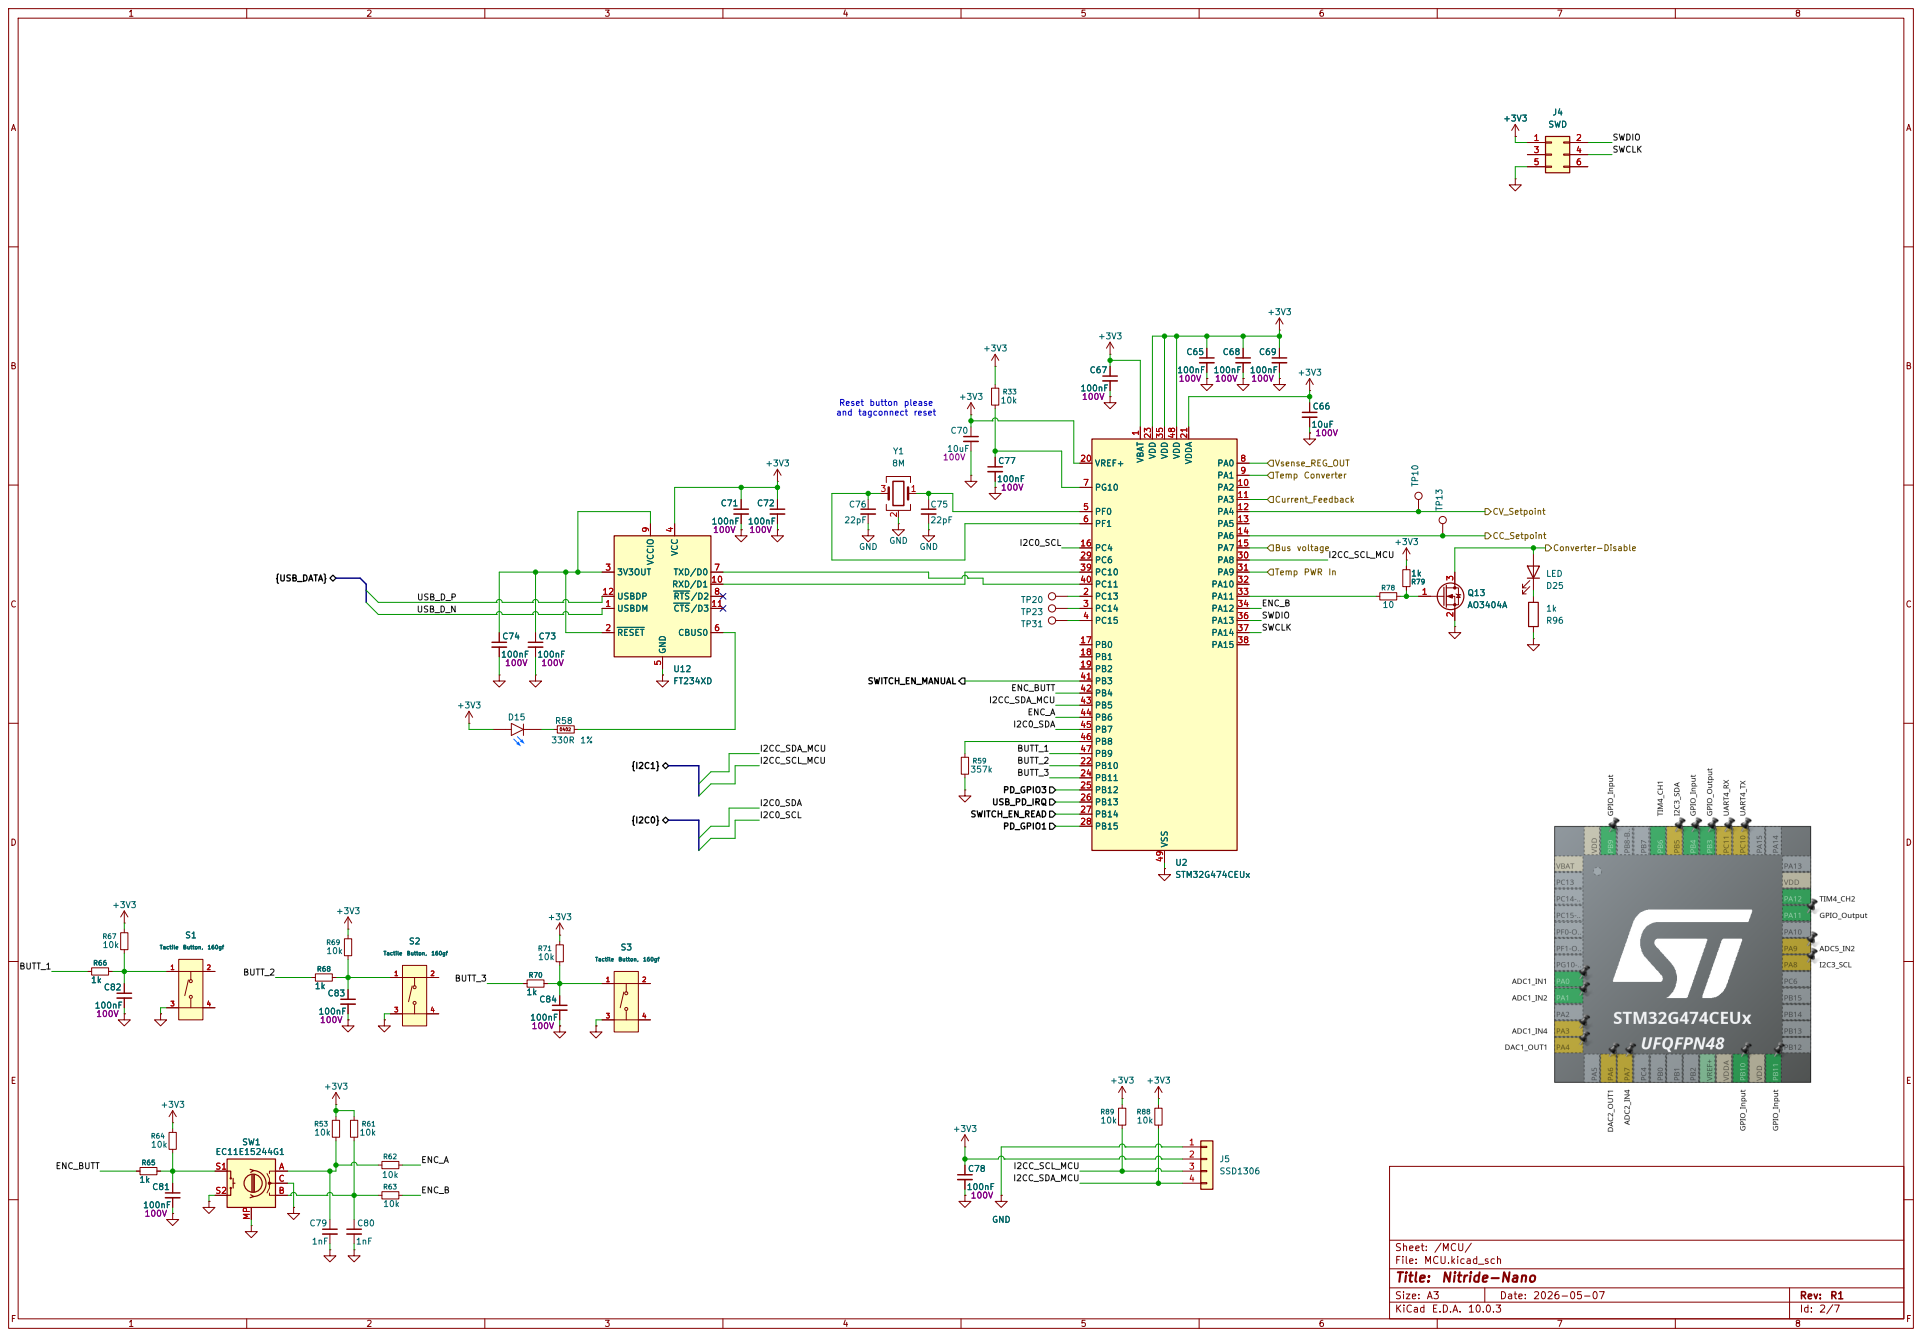
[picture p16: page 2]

9 RXD/D1 10 CTS/D3 11 USBDP 12 GND

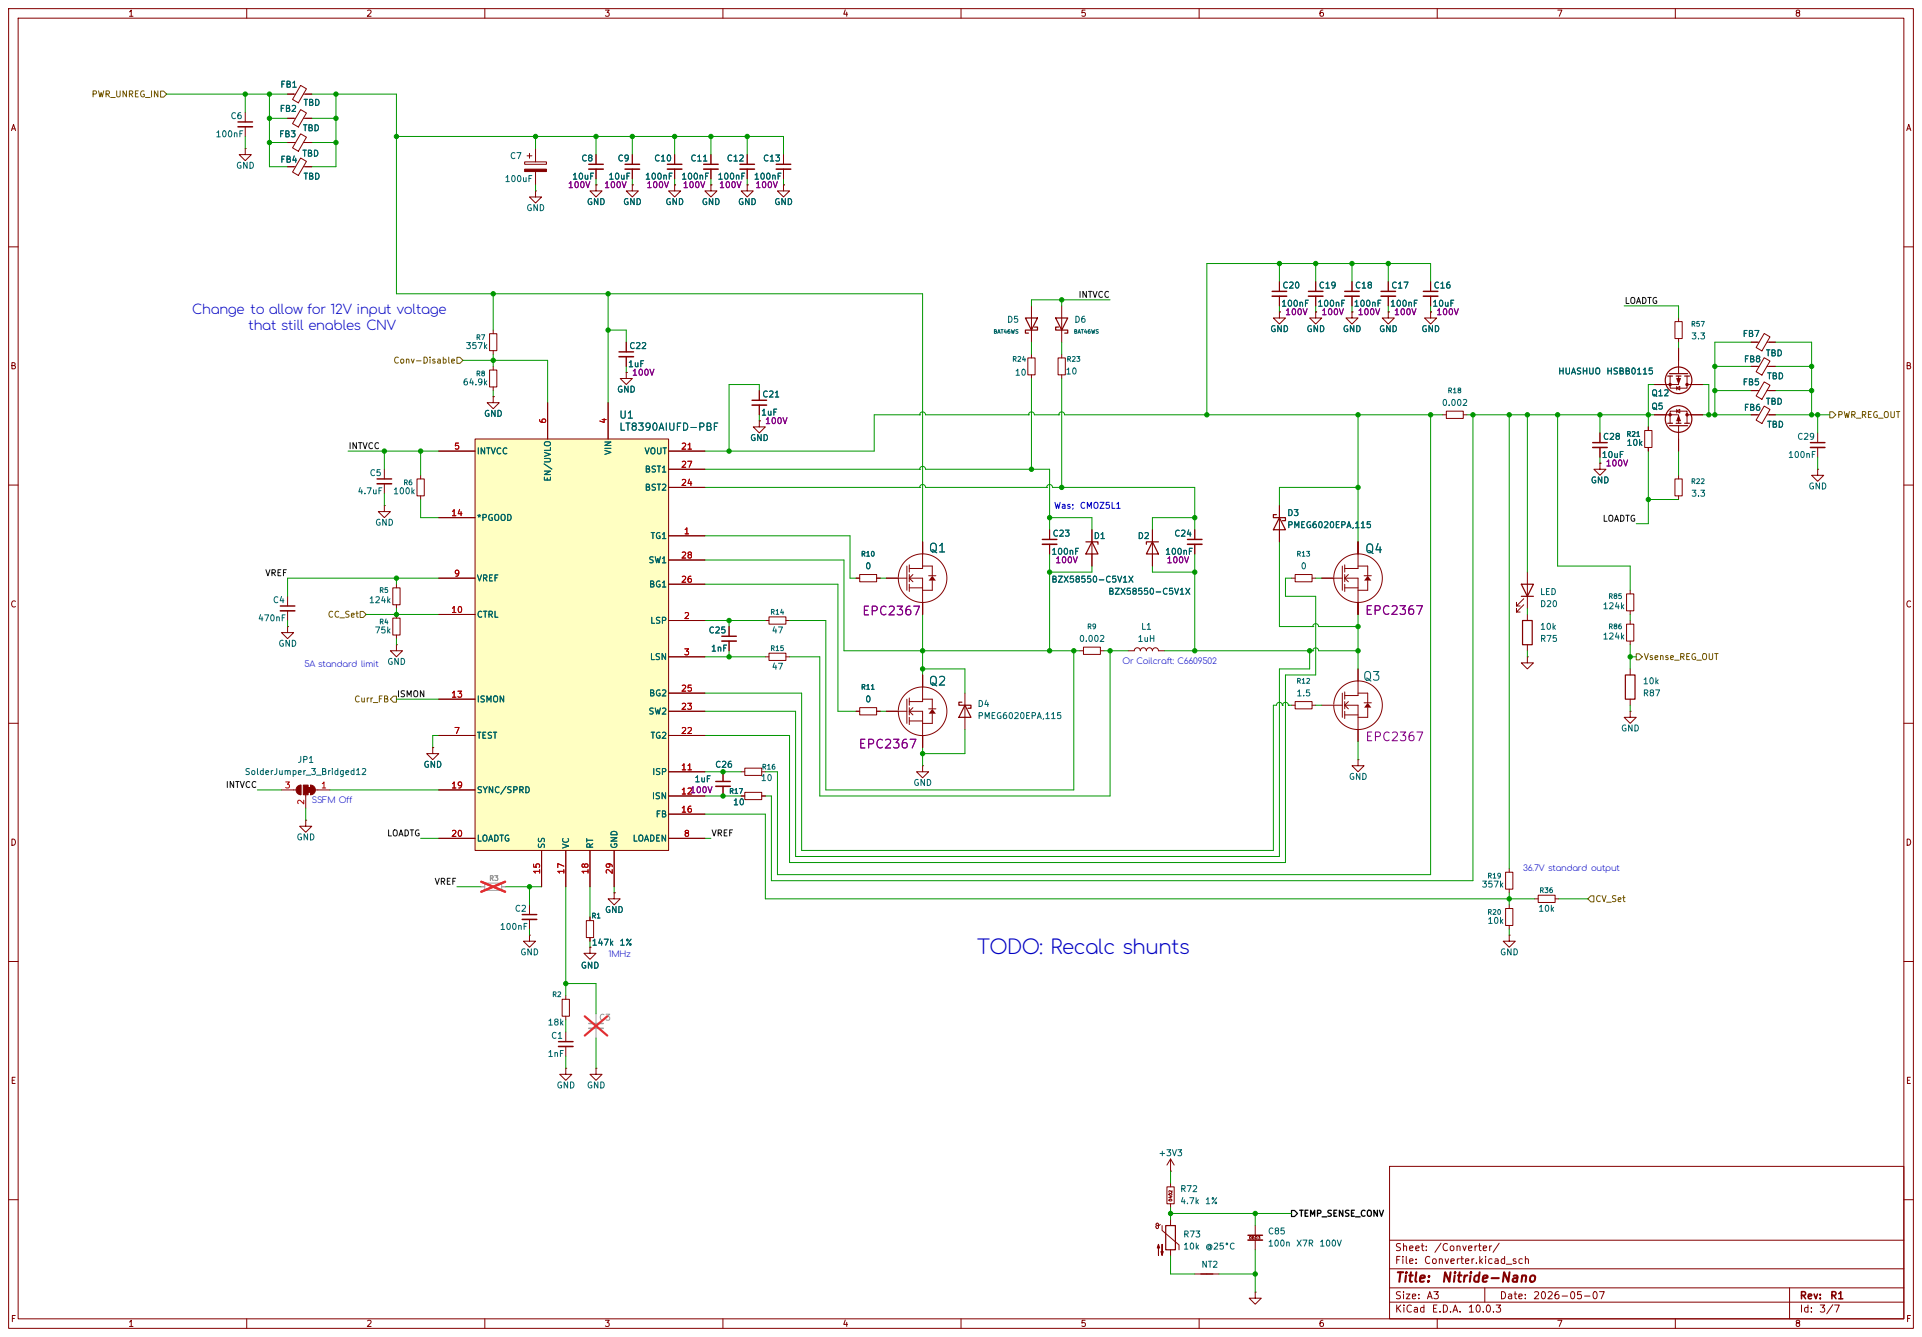
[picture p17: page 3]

Was; CMOZ5L1 Change to allow for 12V input voltage

that still enables CNV

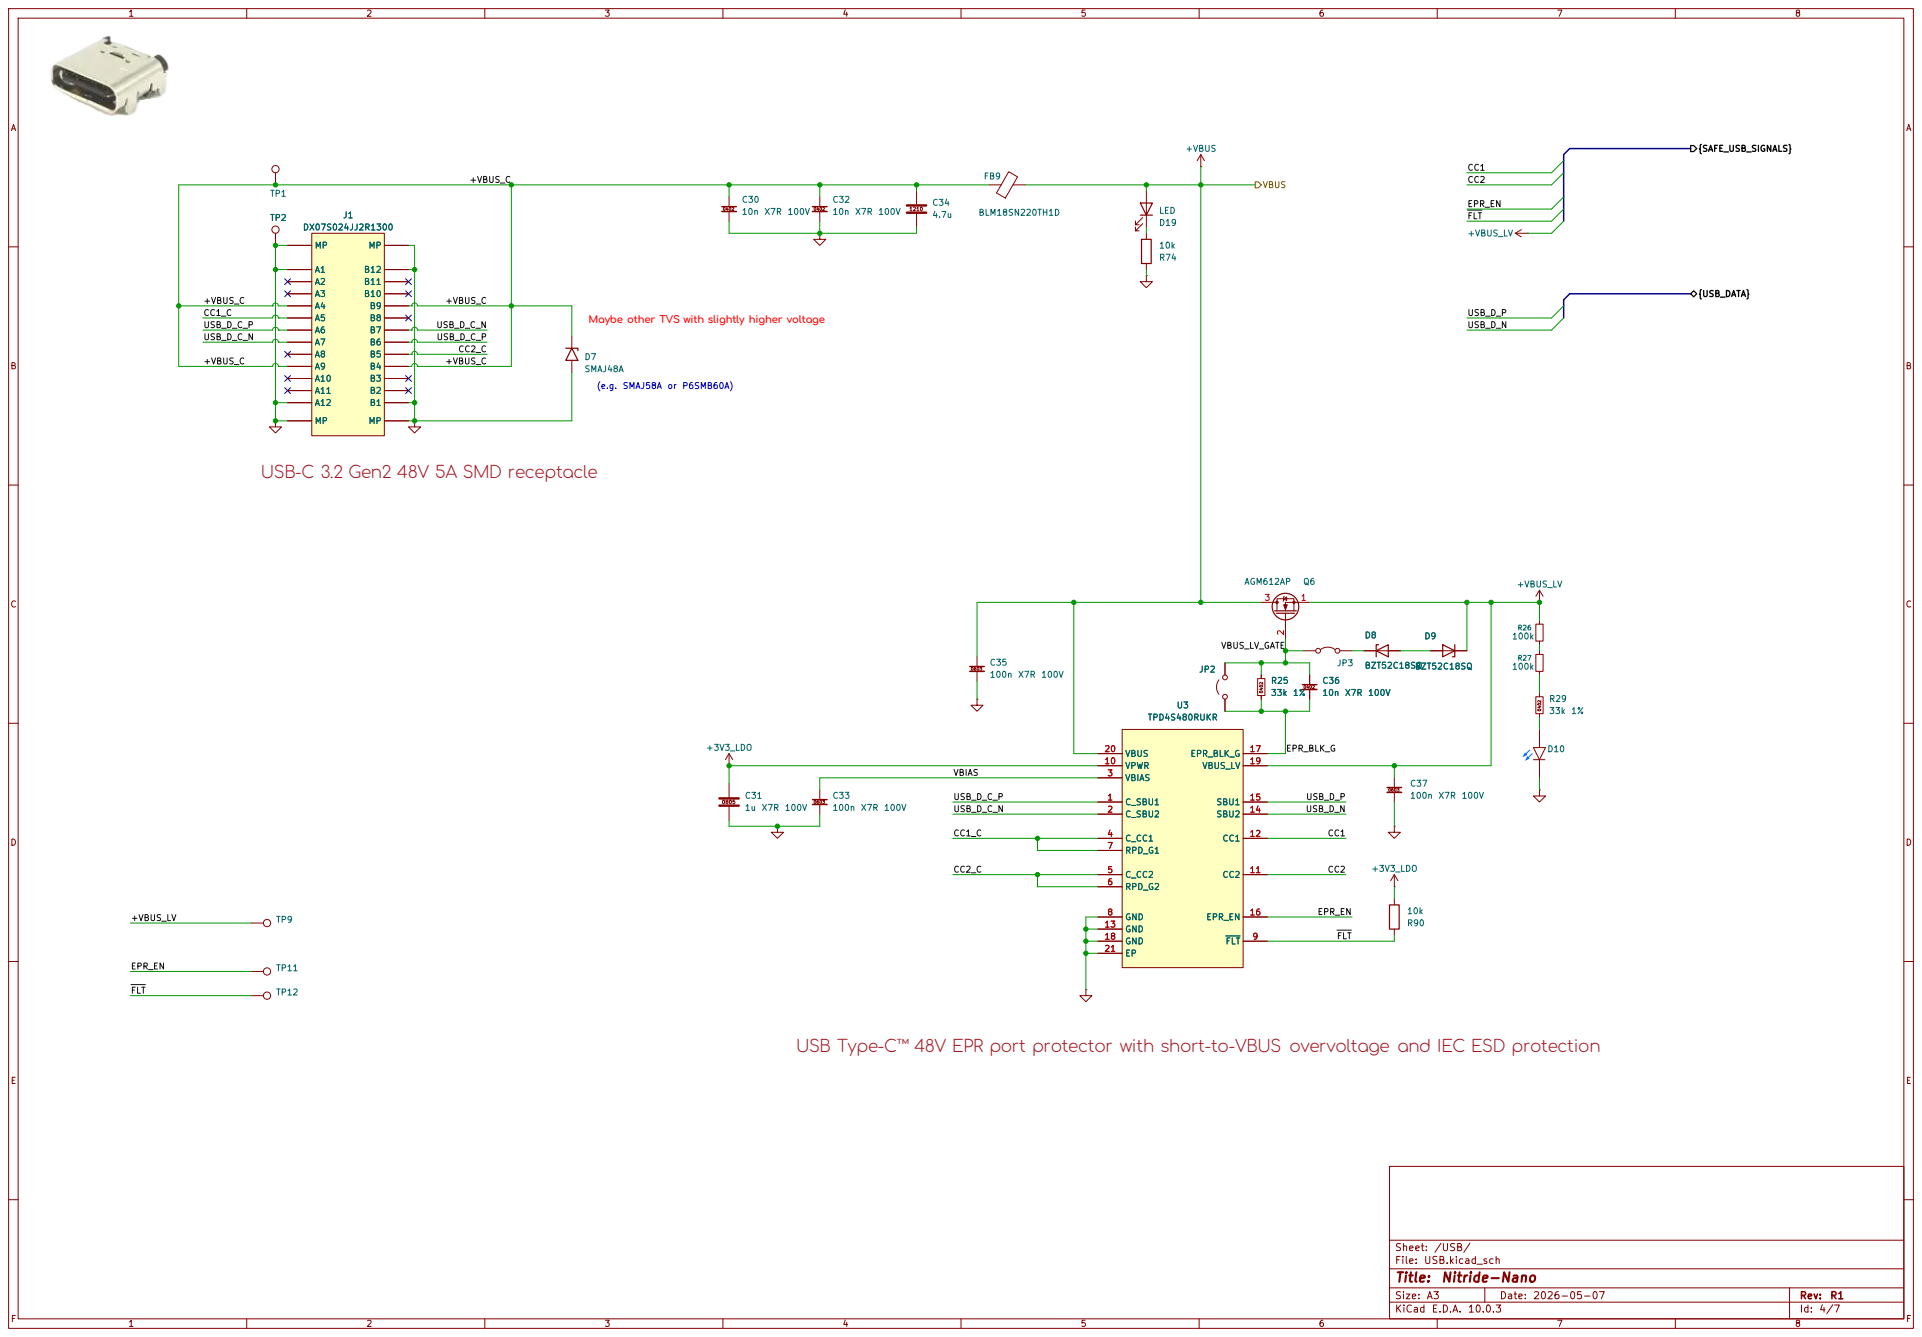
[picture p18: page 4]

EPR_BLK_G USB_D_P USB_D_N Maybe other TVS with slightly higher voltage

USB Type-C™ 48V EPR port protector with short-to-VBUS overvoltage and IEC ESD protection

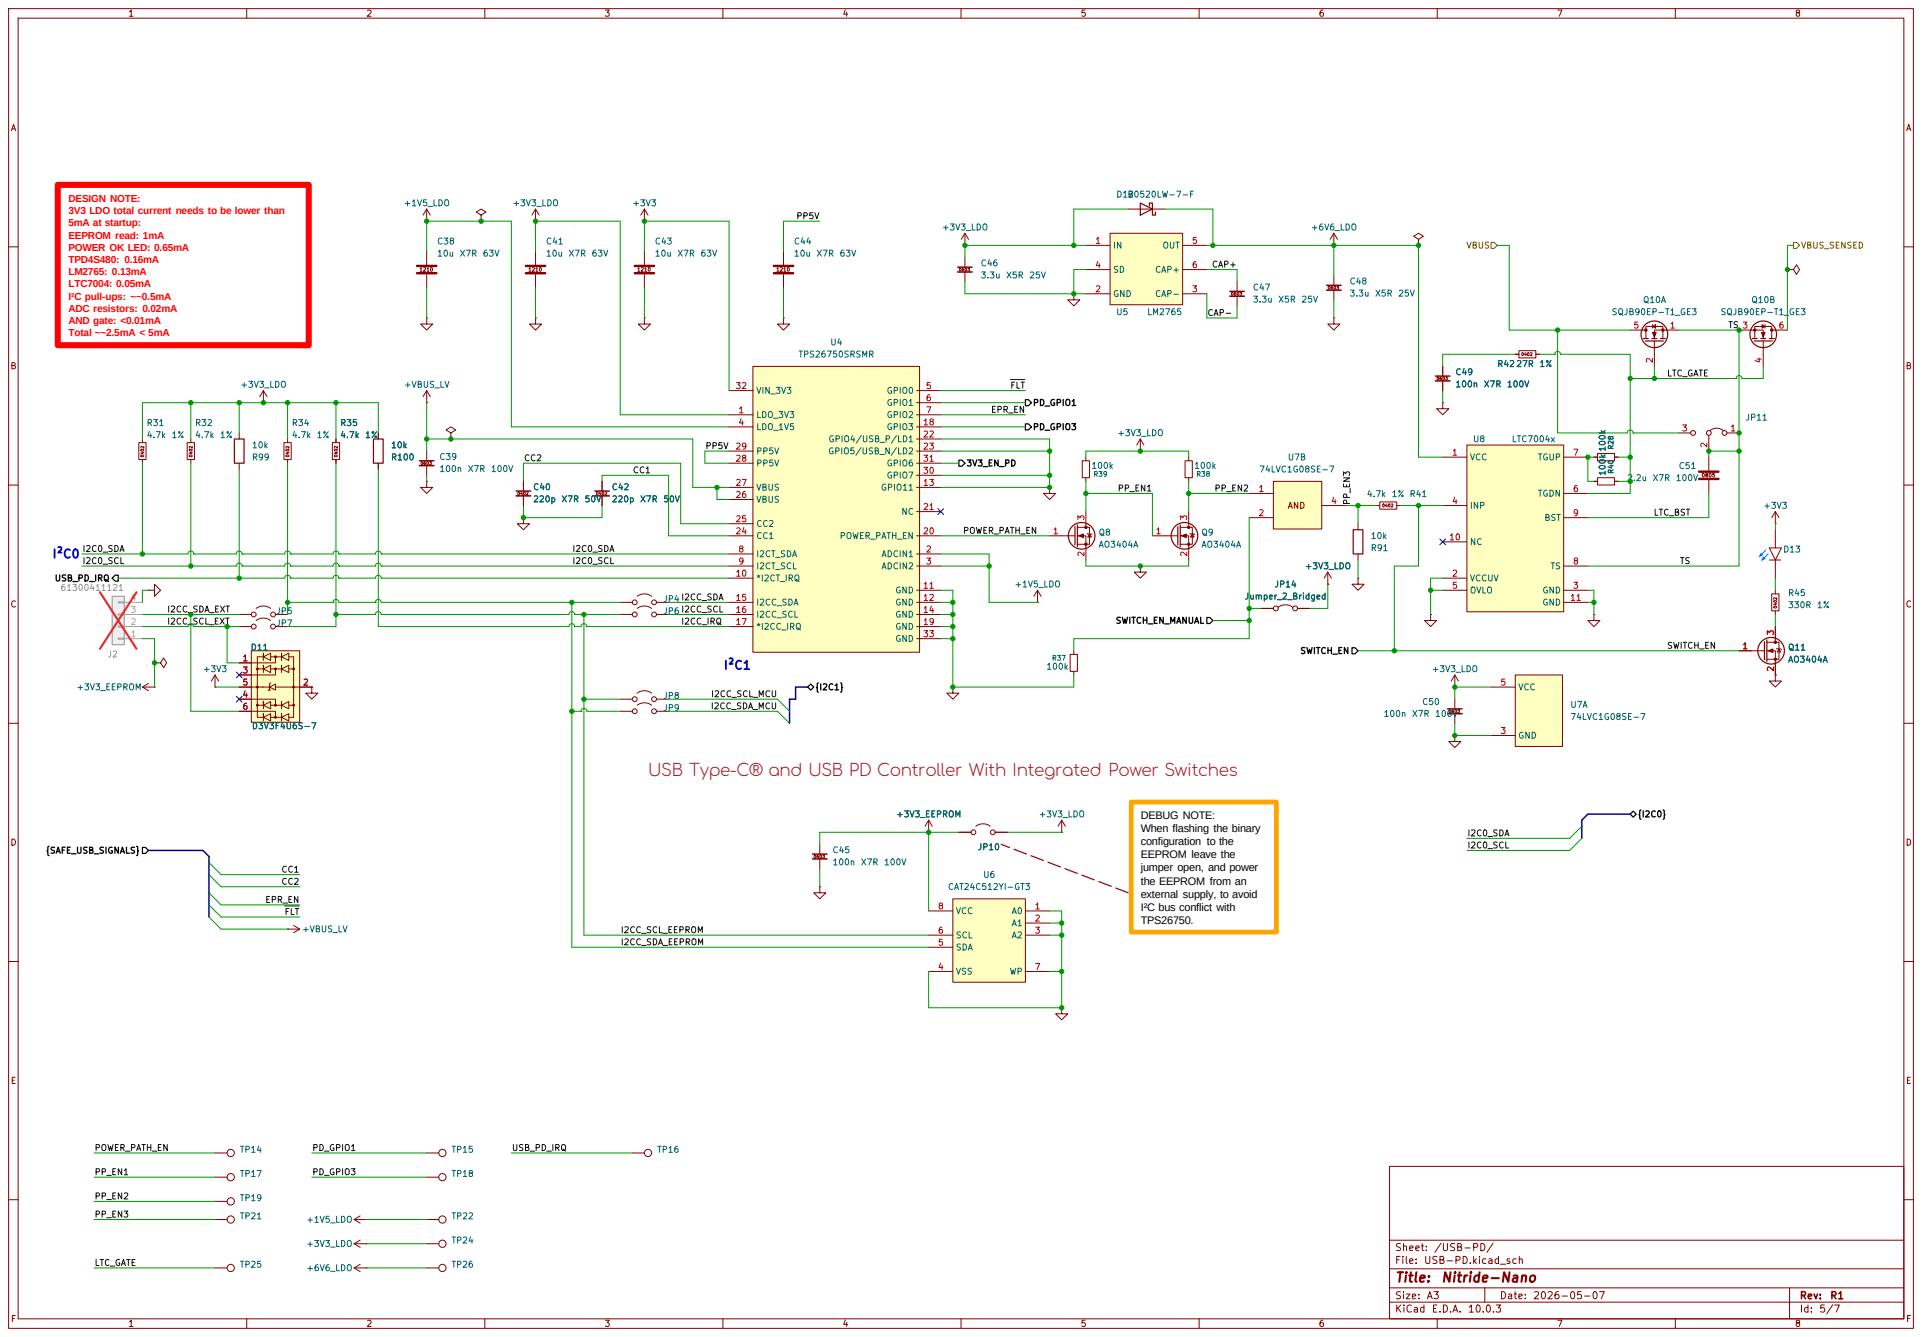
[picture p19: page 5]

DESIGN NOTE: 3V3 LDO total current needs to be lower than

5mA at startup: EEPROM read: 1mA

USB Type-C® and USB PD Controller With Integrated Power Switches

I2C0_SCL DEBUG NOTE:
When flashing the binary
configuration to the
EEPROM leave the
jumper open, and power
the EEPROM from an
external supply, to avoid
I²C bus conflict with
TPS26750.

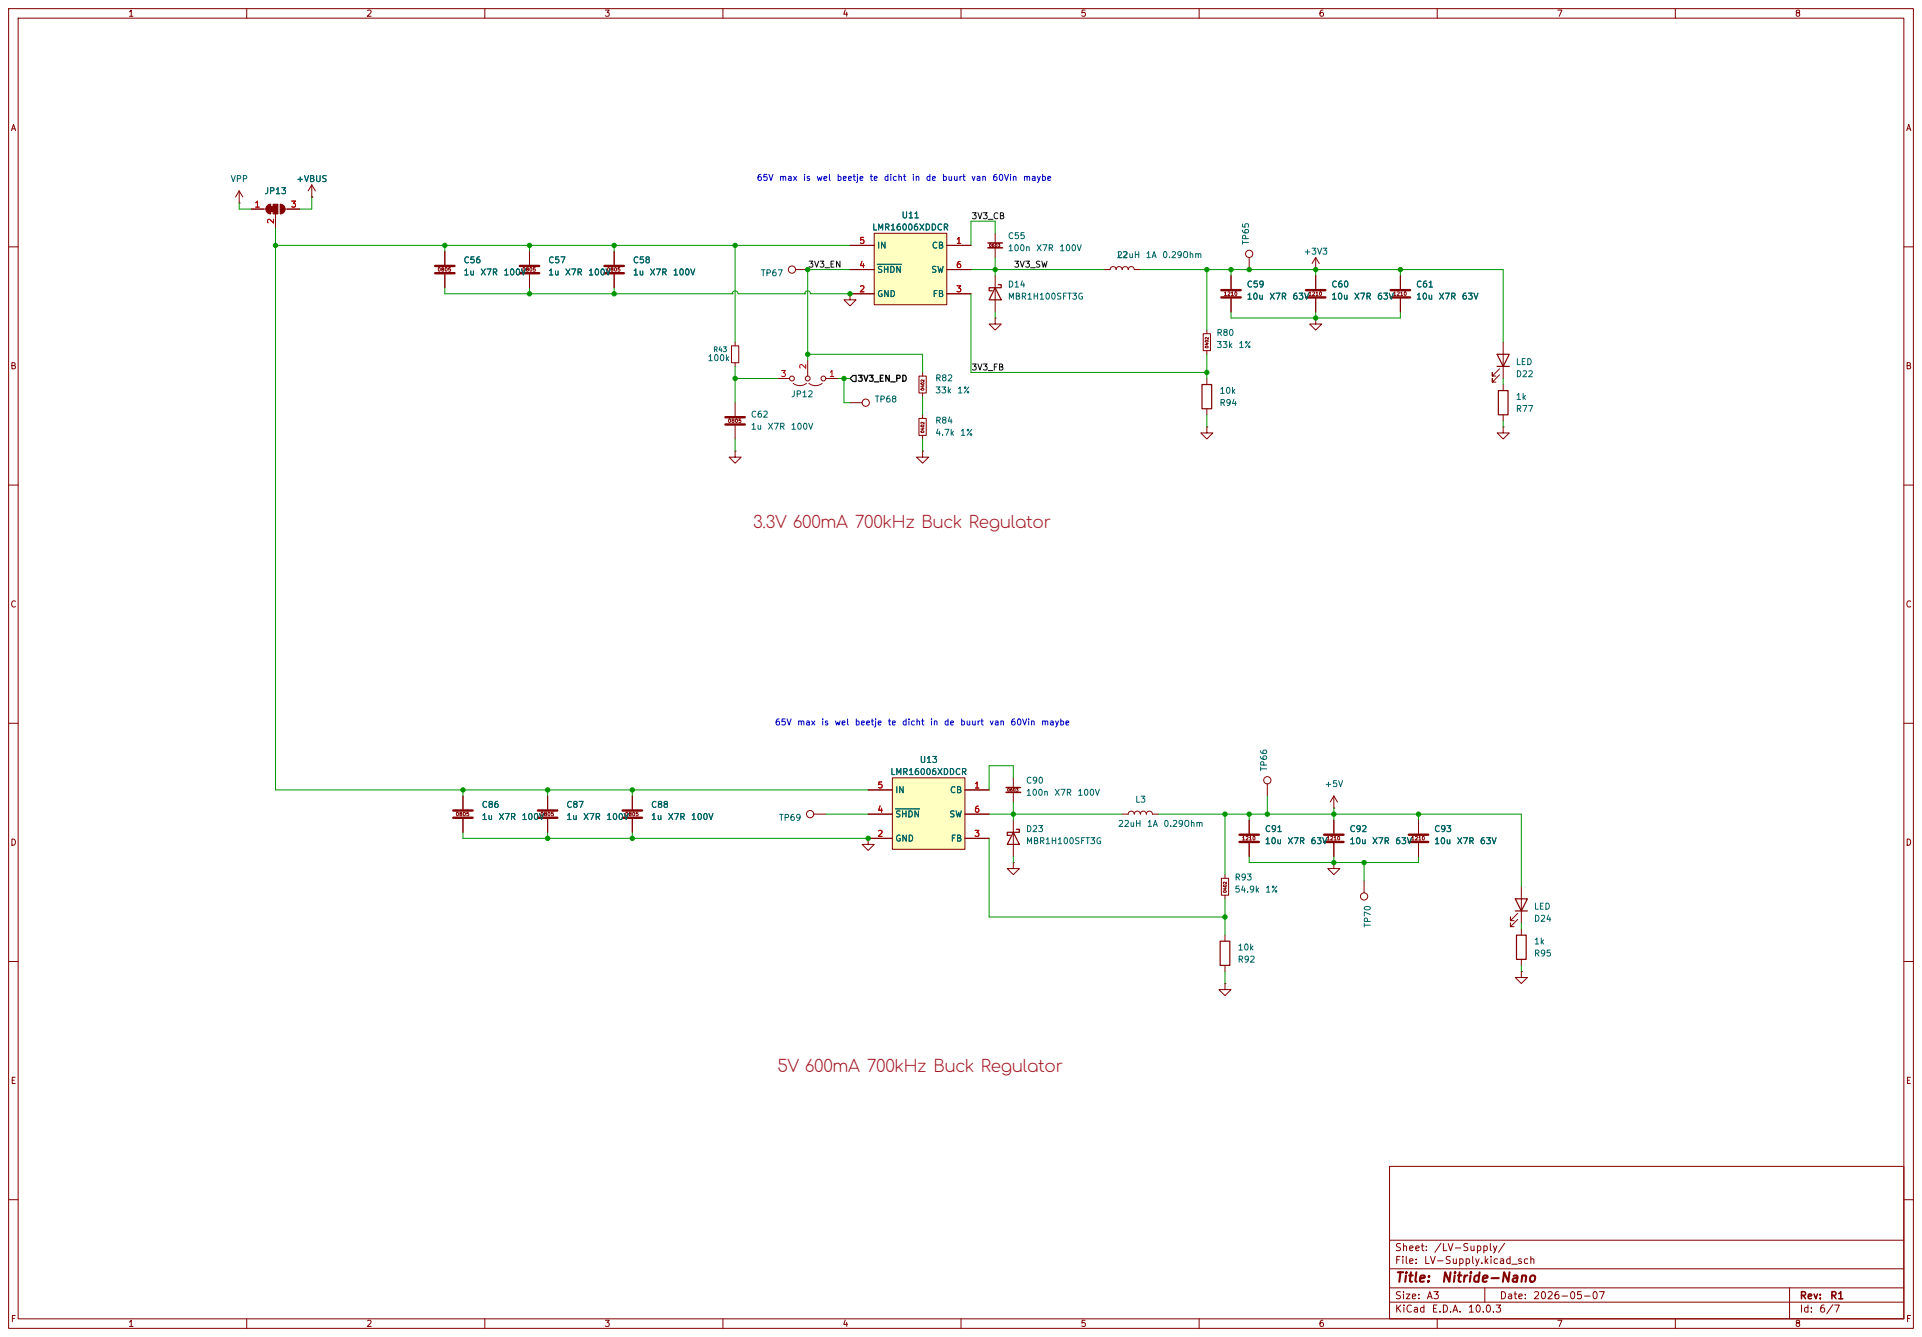
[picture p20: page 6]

65V max is wel beetje te dicht in de buurt van 60Vin maybe

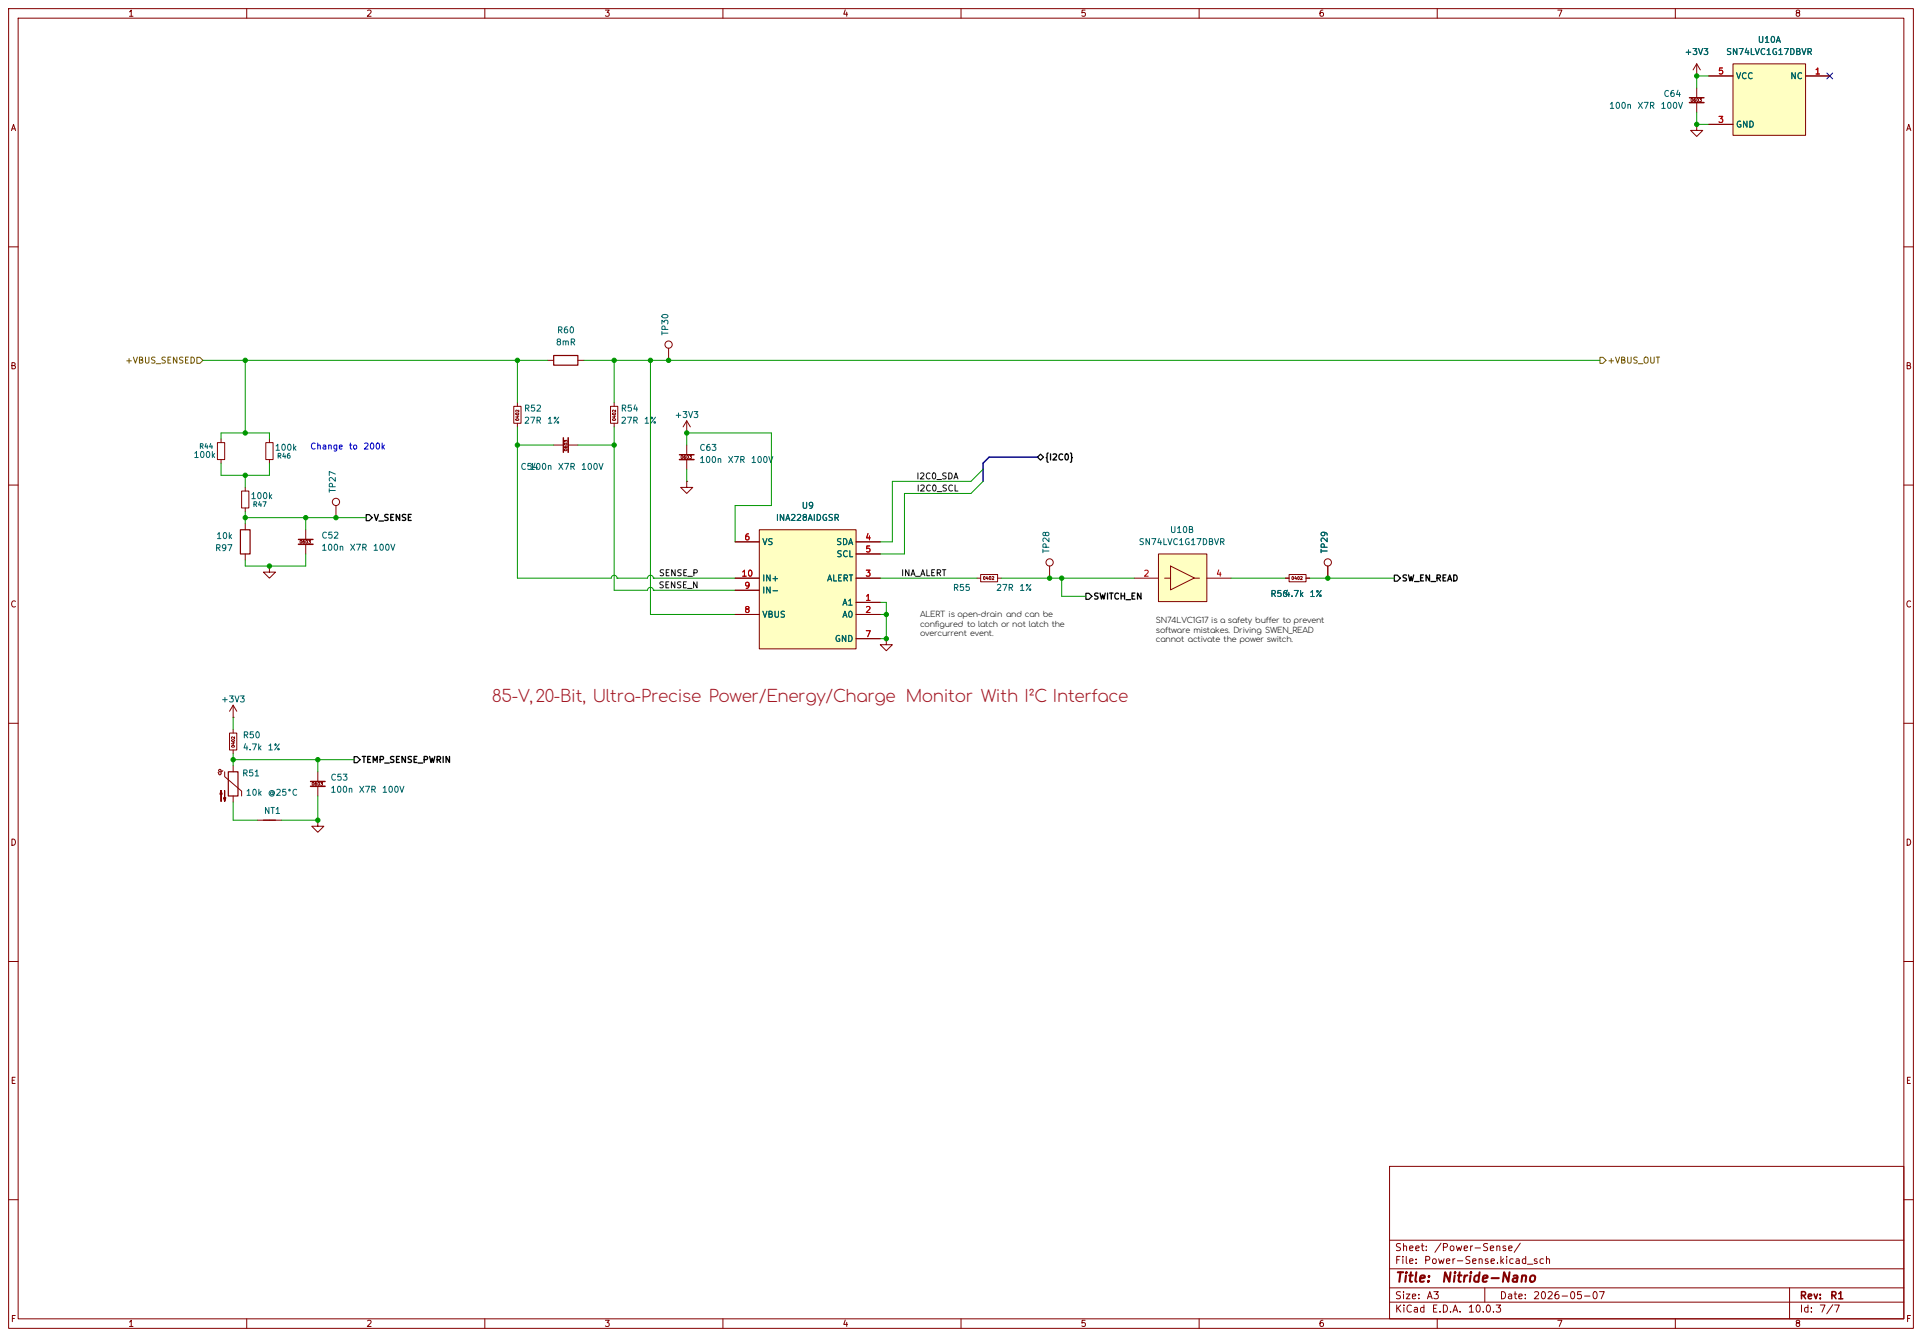
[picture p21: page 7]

cannot activate the power switch. ALERT is open-drain and can be

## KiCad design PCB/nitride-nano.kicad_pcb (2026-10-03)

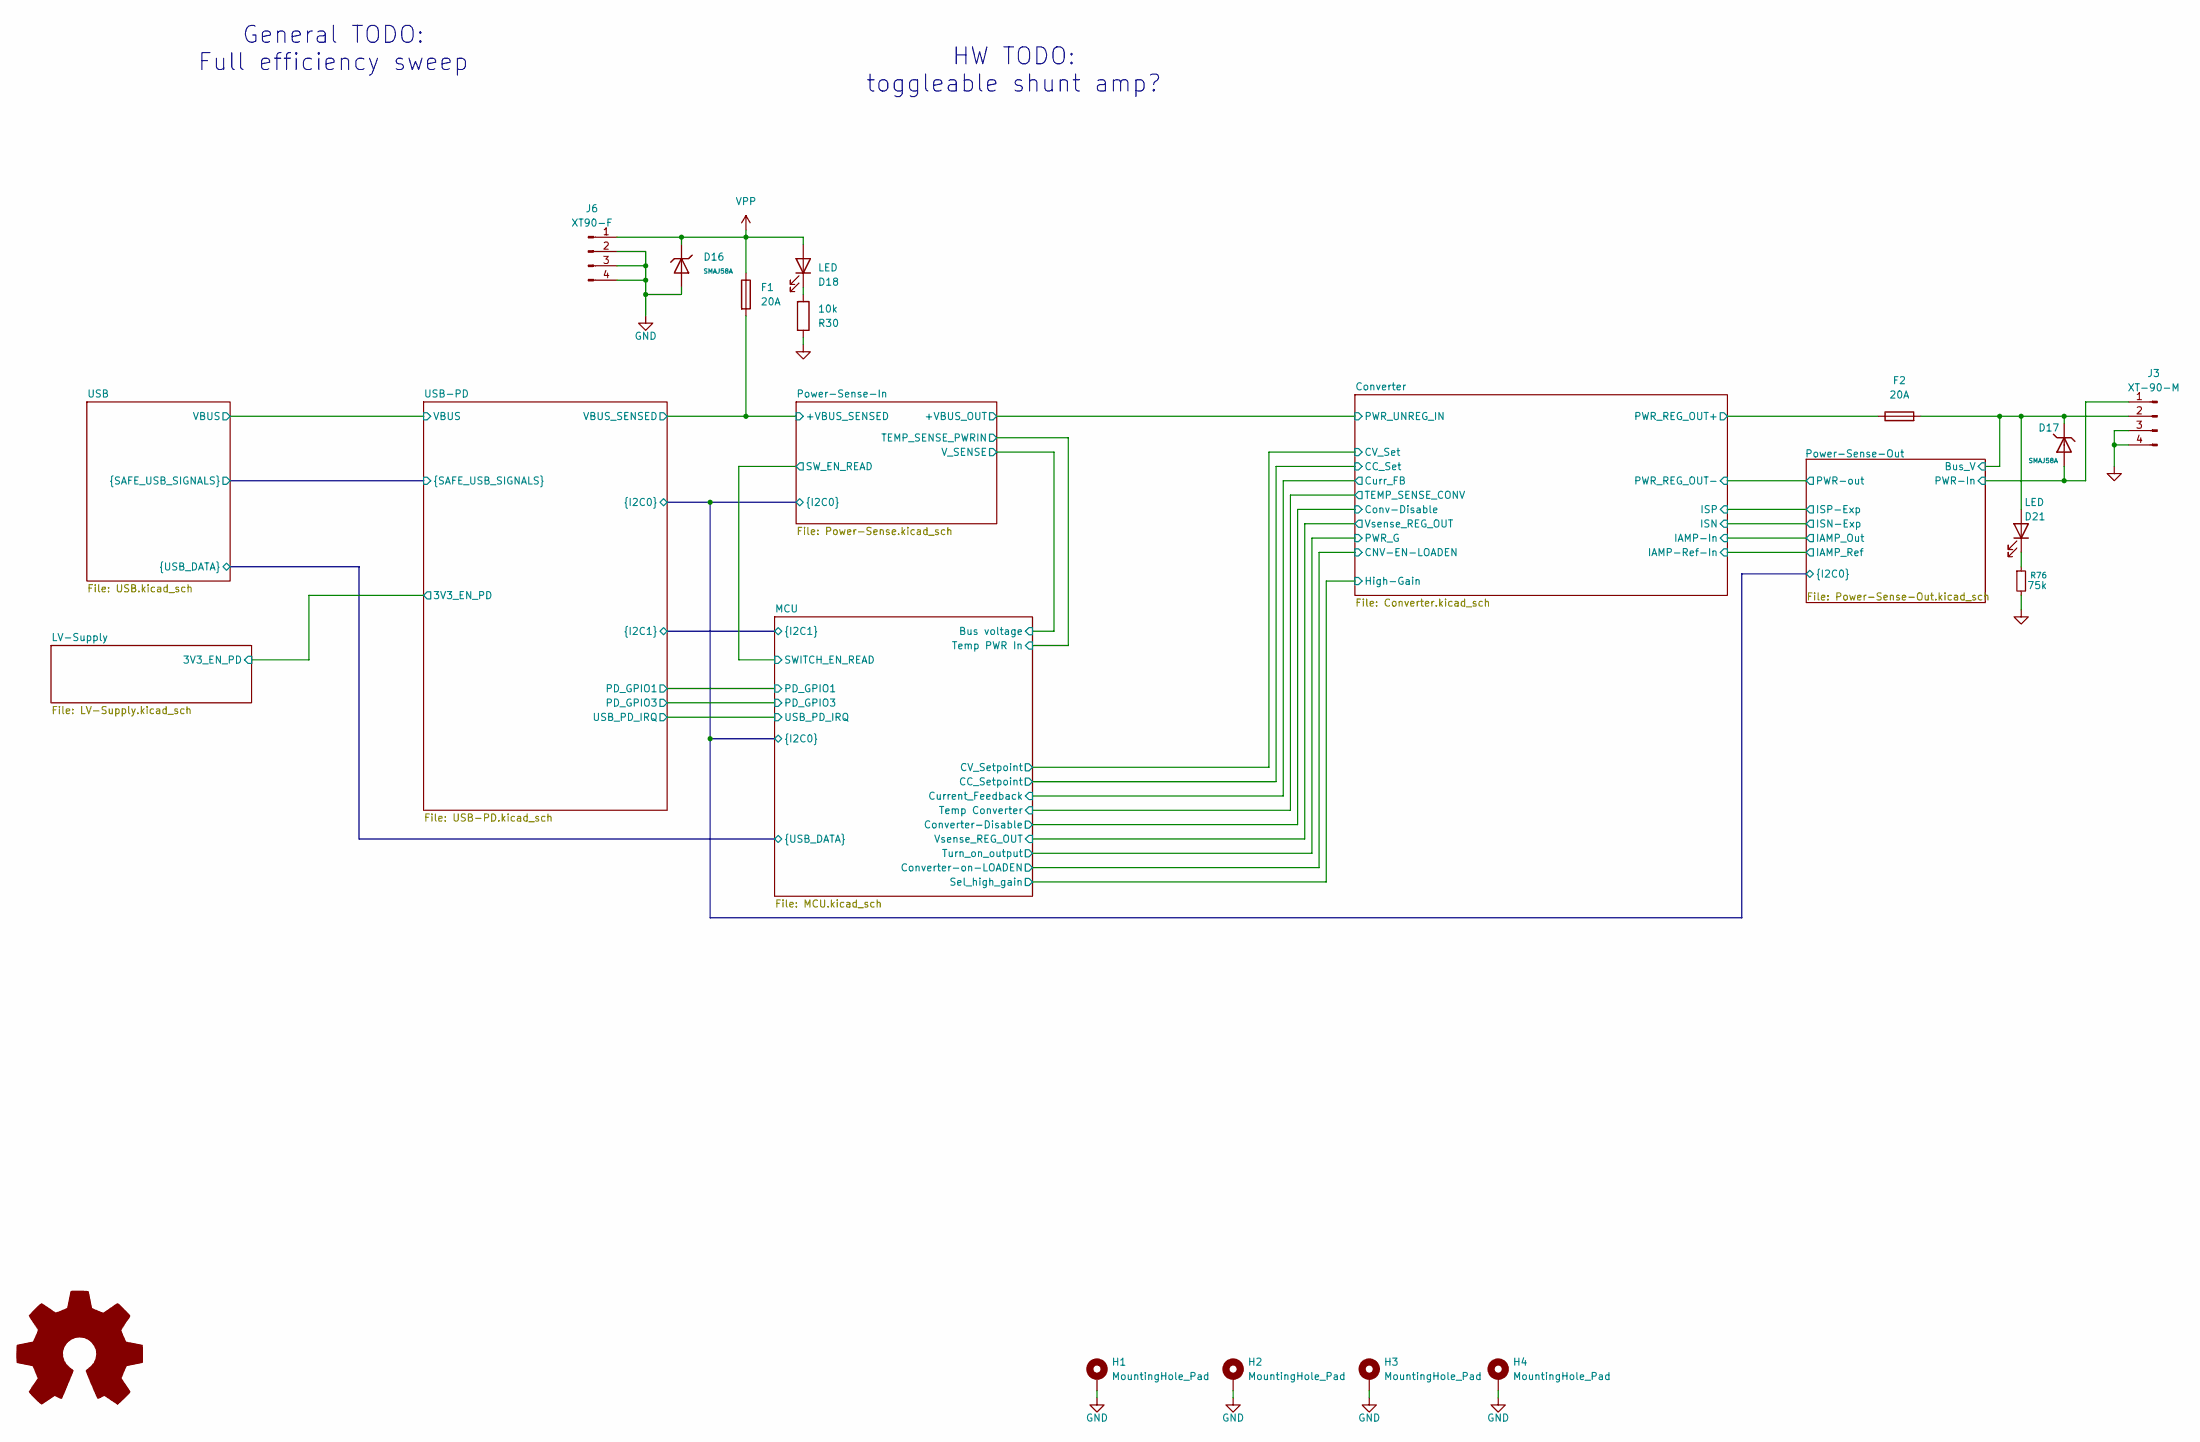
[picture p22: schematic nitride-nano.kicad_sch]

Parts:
D16, D17: SMAJ58A; D_SMA; Part SMAJ58A; LCSC C19077554
D18, D21: LED; LED_0603_1608Metric; LCSC C2286
F1, F2: 20A; Fuse_2512_6332Metric; LCSC C49269483
H1, H2, H3, H4: MountingHole_Pad; MountingHole_3.2mm_M3_Pad_Via
J3: XT-90-M; CONN-TH_XT90PW-M.G.Y; JLC C3040689
J6: XT90-F; CONN-TH_XT90PW-M; JLC C3040690
R30: 10k; R_0402_1005Metric; LCSC C2906861
R76: 75k; R_0402_1005Metric; LCSC C25798

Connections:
/Converter/PWR_REG_OUT+: F2.1; also elsewhere on the board
/Power-Sense-In/+VBUS_SENSED: F1.2; also elsewhere on the board
/Power-Sense-Out/Bus_V: D17.1, D21.2 (A), F2.2, J3.2; also elsewhere on the board
/Power-Sense-Out/PWR-In: D17.2, J3.1; also elsewhere on the board
GND: D16.2, H1.1 (1_1), H2.1 (1_1), H3.1 (1_1), H4.1 (1_1), J3.3, J3.4, J6.2, J6.3, J6.4, R30.1, R76.2; also elsewhere on the board
unnamed: D18.1 (K), R30.2
unnamed: D21.1 (K), R76.1
VPP: D16.1, D18.2 (A), F1.1, J6.1; also elsewhere on the board

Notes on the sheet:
HW TODO: toggleable shunt amp?
General TODO: Full efficiency sweep

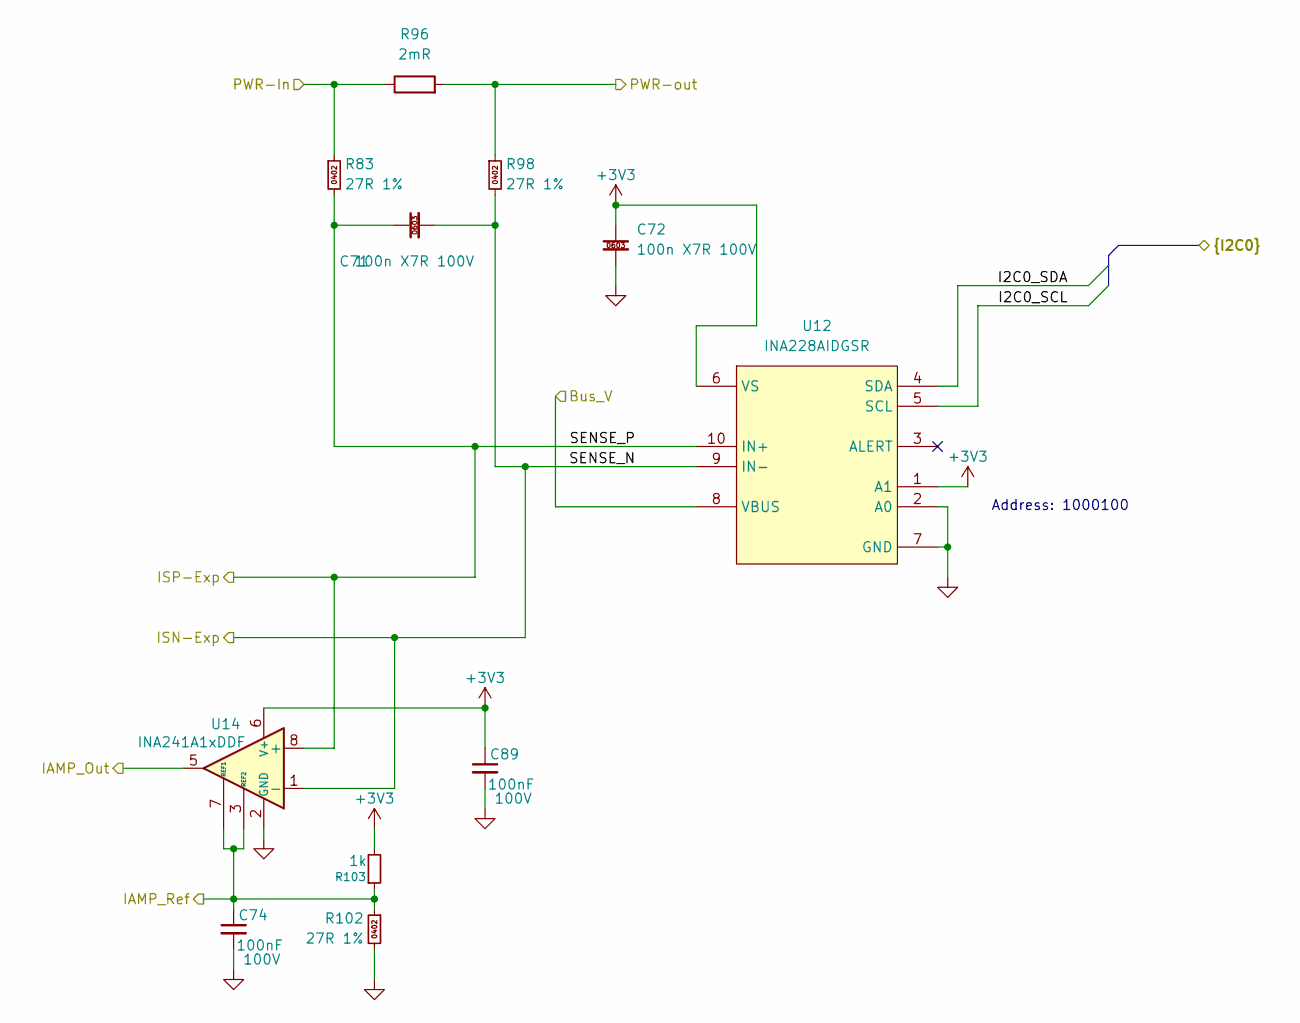
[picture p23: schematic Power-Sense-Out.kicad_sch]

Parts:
C71, C72: 100n X7R 100V; C_0603_1608Metric; Manufacturer Part Number CL10B104KC8NNNC; LCSC C15725
C74, C89: 100nF; C_0402_1005Metric; Voltage 100V; LCSC C162178
R83, R98, R102: 27R 1%; R_0402_1005Metric; Manufacturer Part Number RC0402FR-0727RL; LCSC C138021
R96: 2mR; R_2512_6332Metric; JLC C41382683
R103: 1k; R_0402_1005Metric; LCSC C106235
U12: INA228AIDGSR; vssop10_50p_300x300x110_mfg; Manufacturer Part Number INA228AIDGSR; LCSC C2887910
U14: INA241A1xDDF; SOT-23-8

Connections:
+3V3: C72.1, C89.1, R103.2, U12.1 (A1), U12.6 (VS), U14.6 (V+); also elsewhere on the board
/Converter/IAMP-In: U14.5; also elsewhere on the board
/Converter/IAMP-Ref-In: C74.1, R102.1, R103.1, U14.3 (REF2), U14.7 (REF1); also elsewhere on the board
/Converter/PWR_REG_OUT-: R96.2, R98.1; also elsewhere on the board
/MCU/I2C0_SCL: U12.5 (SCL); also elsewhere on the board
/MCU/I2C0_SDA: U12.4 (SDA); also elsewhere on the board
/Power-Sense-Out/Bus_V: U12.8 (VBUS); also elsewhere on the board
/Power-Sense-Out/PWR-In: R83.1, R96.1; also elsewhere on the board
/Power-Sense-Out/SENSE_N: C71.2, R98.2, U12.9 (IN-), U14.1 (-); also elsewhere on the board
/Power-Sense-Out/SENSE_P: C71.1, R83.2, U12.10 (IN+), U14.8 (+); also elsewhere on the board
GND: C72.2, C74.2, C89.2, R102.2, U12.2 (A0), U12.7 (GND), U14.2 (GND), U14.4 (GND); also elsewhere on the board

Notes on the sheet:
Address: 1000100

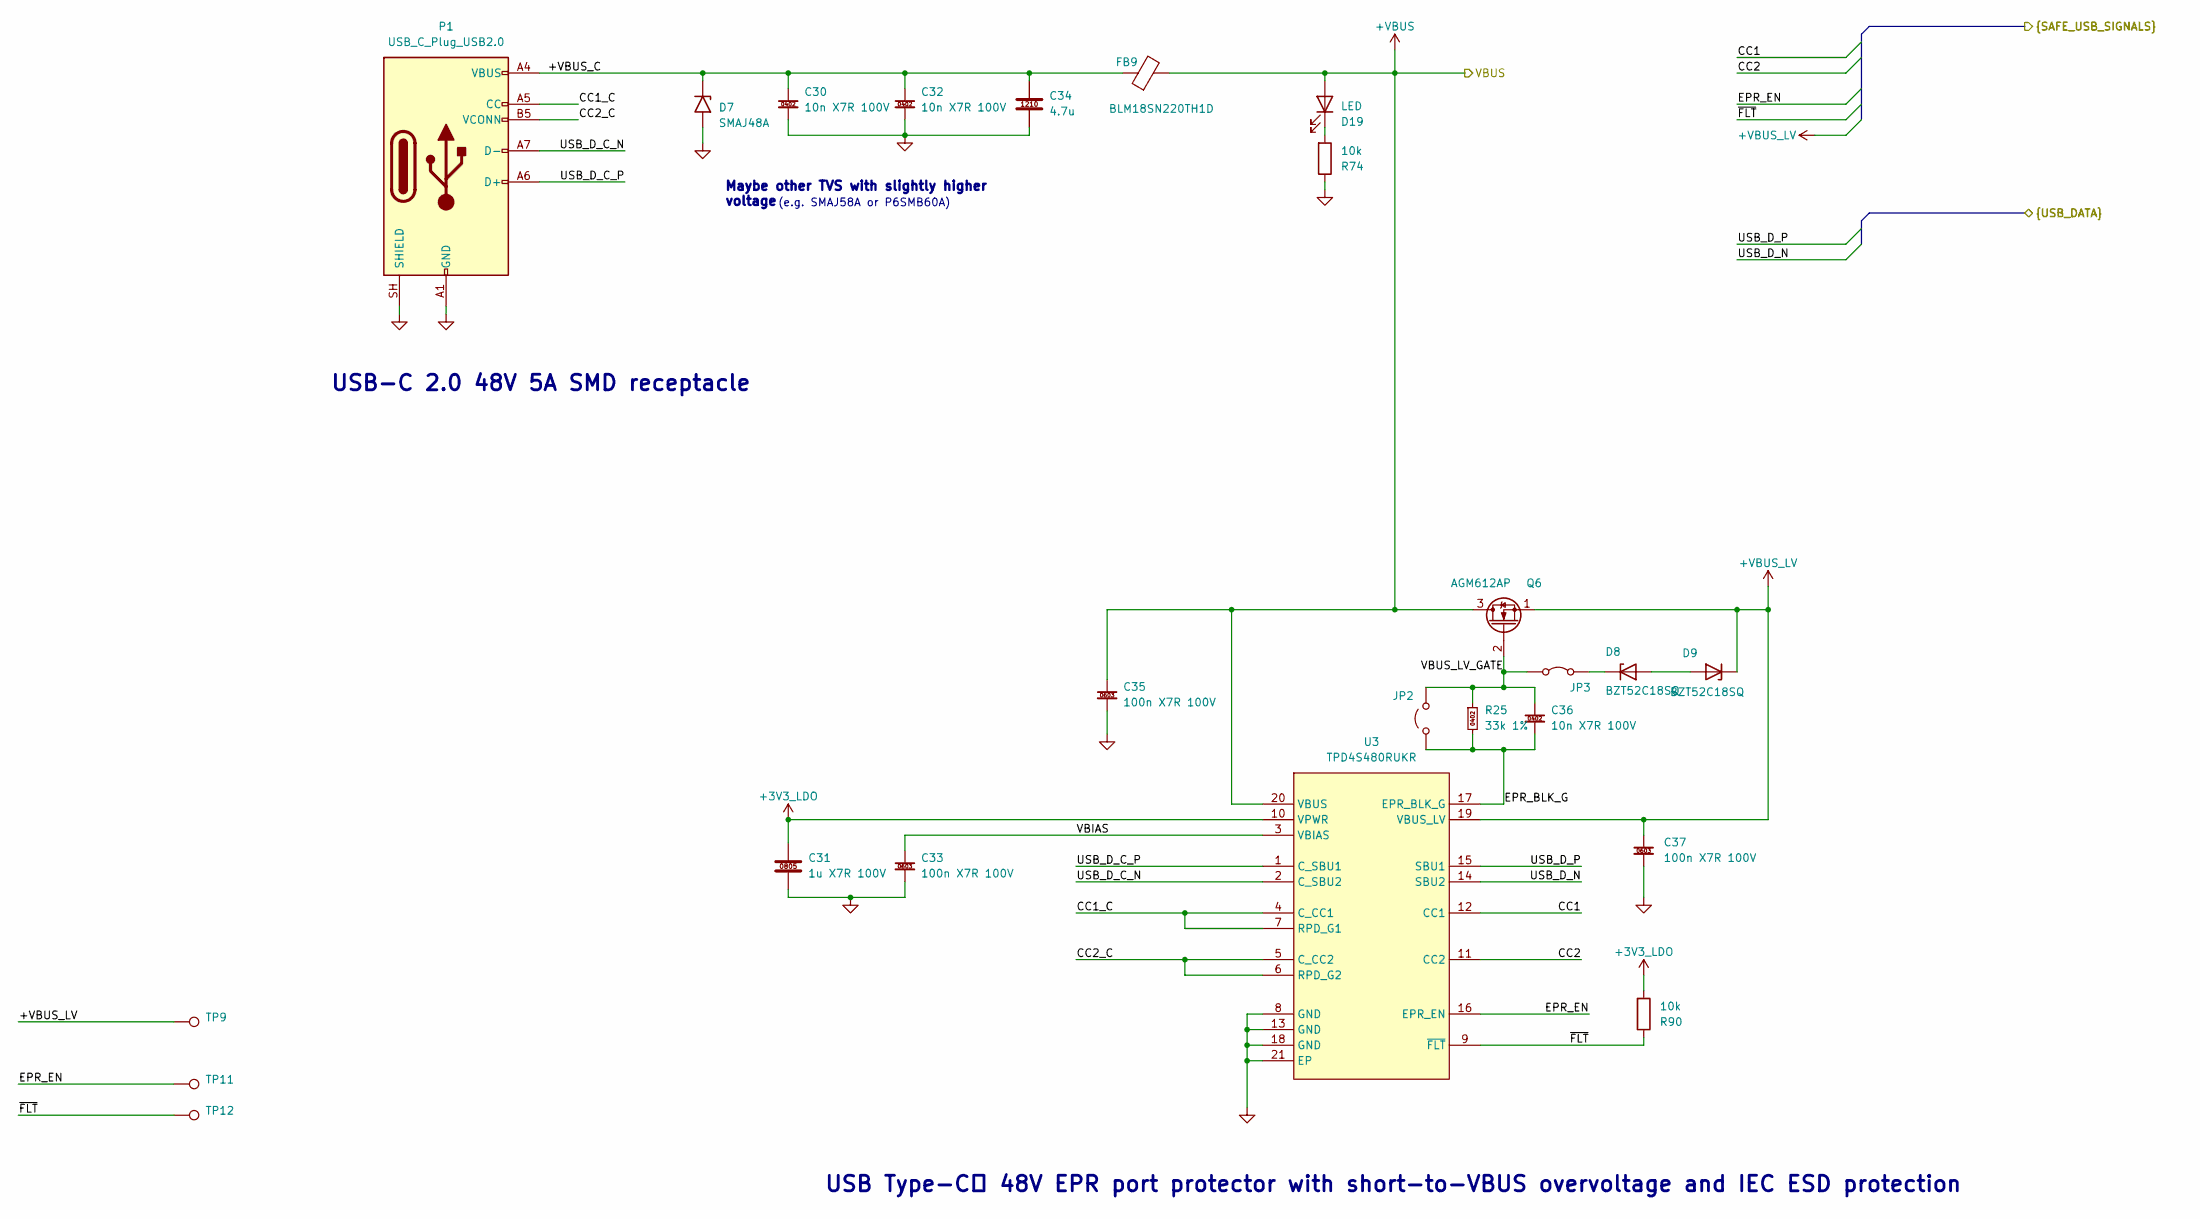
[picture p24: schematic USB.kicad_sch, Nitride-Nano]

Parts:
C30, C32, C36: 10n X7R 100V; C_0402_1005Metric; Manufacturer Part Number CC0402KRX7R0BB103; LCSC C527014
C31: 1u X7R 100V; C_0805_2012Metric; Manufacturer Part Number CC0805KKX7R0BB105; LCSC C5370002
C33, C35, C37: 100n X7R 100V; C_0603_1608Metric; Manufacturer Part Number CL10B104KC8NNNC; LCSC C15725
C34: 4.7u; C_1210_3225Metric; Manufacturer Part Number GCM32DC72A475KE02; LCSC C913445
D7: SMAJ48A; do-214ac_440p_430x250x230_n_p; Manufacturer Part Number SMAJ48A; LCSC C41376401
D8, D9: BZT52C18SQ; sod-323_230p_170x125x100_n; Manufacturer Part Number BZT52C18SQ; LCSC C2857090
D19: LED; LED_0603_1608Metric; LCSC C2286
FB9: BLM18SN220TH1D; fer_1608_09_n; Manufacturer Part Number BLM18SN220TH1D; LCSC C710392
JP2: jumper_solder_2pad_no; SolderJumper-2_P1.3mm_Open_RoundedPad1.0x1.5mm
JP3: jumper_solder_2pad_nc_kicad; SolderJumper-2_P1.3mm_Bridged2Bar_RoundedPad1.0x1.5mm
P1: USB_C_Plug_USB2.0; USB_C_Receptacle_GCT_USB4105-xx-A_16P_TopMnt_Horizontal; JLC C3025063
Q6: AGM612AP; vsonp8_65p_330x330x80_mfg; Manufacturer Part Number AGM612AP; LCSC C5349119
R25: 33k 1%; R_0402_1005Metric; Manufacturer Part Number RC0402FR-0733KL; LCSC C138003
R74, R90: 10k; R_0402_1005Metric; LCSC C2906861
TP9, TP11, TP12: tp_round_70; TestPoint_Pad_D1.0mm
U3: TPD4S480RUKR; wqfn20_40p_300x300x80_tp_170x170_n; Manufacturer Part Number TPD4S480RUKR; LCSC C43131250

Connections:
+3V3_LDO: C31.1, R90.2, U3.10 (VPWR); also elsewhere on the board
+VBUS: C35.1, D19.2 (A), FB9.2, Q6.3 (D), U3.20 (VBUS); also elsewhere on the board
+VBUS_LV: C37.1, D9.1 (K), Q6.1 (S), TP9.1 (1_1), U3.19 (VBUS_LV); also elsewhere on the board
/MCU/USB_D_N: U3.14 (SBU2); also elsewhere on the board
/MCU/USB_D_P: U3.15 (SBU1); also elsewhere on the board
/USB-PD/CC1: U3.12 (CC1); also elsewhere on the board
/USB-PD/CC2: U3.11 (CC2); also elsewhere on the board
/USB-PD/EPR_EN: TP11.1 (1_1), U3.16 (EPR_EN); also elsewhere on the board
/USB-PD/~FLT: R90.1, TP12.1 (1_1), U3.9 (~FLT); also elsewhere on the board
/USB/+VBUS_C: C30.1, C32.1, C34.1, D7.1 (A1), FB9.1, P1.A4 (VBUS), P1.A9 (VBUS), P1.B4 (VBUS), P1.B9 (VBUS)
/USB/CC1_C: P1.A5 (CC), U3.4 (C_CC1), U3.7 (RPD_G1)
/USB/CC2_C: P1.B5 (VCONN), U3.5 (C_CC2), U3.6 (RPD_G2)
/USB/EPR_BLK_G: C36.2, JP2.1 (A), R25.2, U3.17 (EPR_BLK_G)
/USB/USB_D_C_N: P1.A7 (D-), U3.2 (C_SBU2)
/USB/USB_D_C_P: P1.A6 (D+), U3.1 (C_SBU1)
/USB/VBIAS: C33.1, U3.3 (VBIAS)
/USB/VBUS_LV_GATE: C36.1, JP2.2 (B), JP3.1 (A), Q6.2 (G), R25.1
GND: C30.2, C31.2, C32.2, C33.2, C34.2, C35.2, C37.2, D7.2 (A2), P1.A1 (GND), P1.A12 (GND), P1.B1 (GND), P1.B12 (GND), P1.SH (SHIELD), R74.1, U3.8 (GND), U3.13 (GND), U3.18 (GND), U3.21 (EP); also elsewhere on the board
unnamed: D8.2 (A), D9.2 (A)
unnamed: D8.1 (K), JP3.2 (B)
unnamed: D19.1 (K), R74.2

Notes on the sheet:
USB Type-C™ 48V EPR port protector with short-to-VBUS overvoltage and IEC ESD protection
(e.g. SMAJ58A or P6SMB60A)
USB-C 2.0 48V 5A SMD receptacle
Maybe other TVS with slightly higher voltage

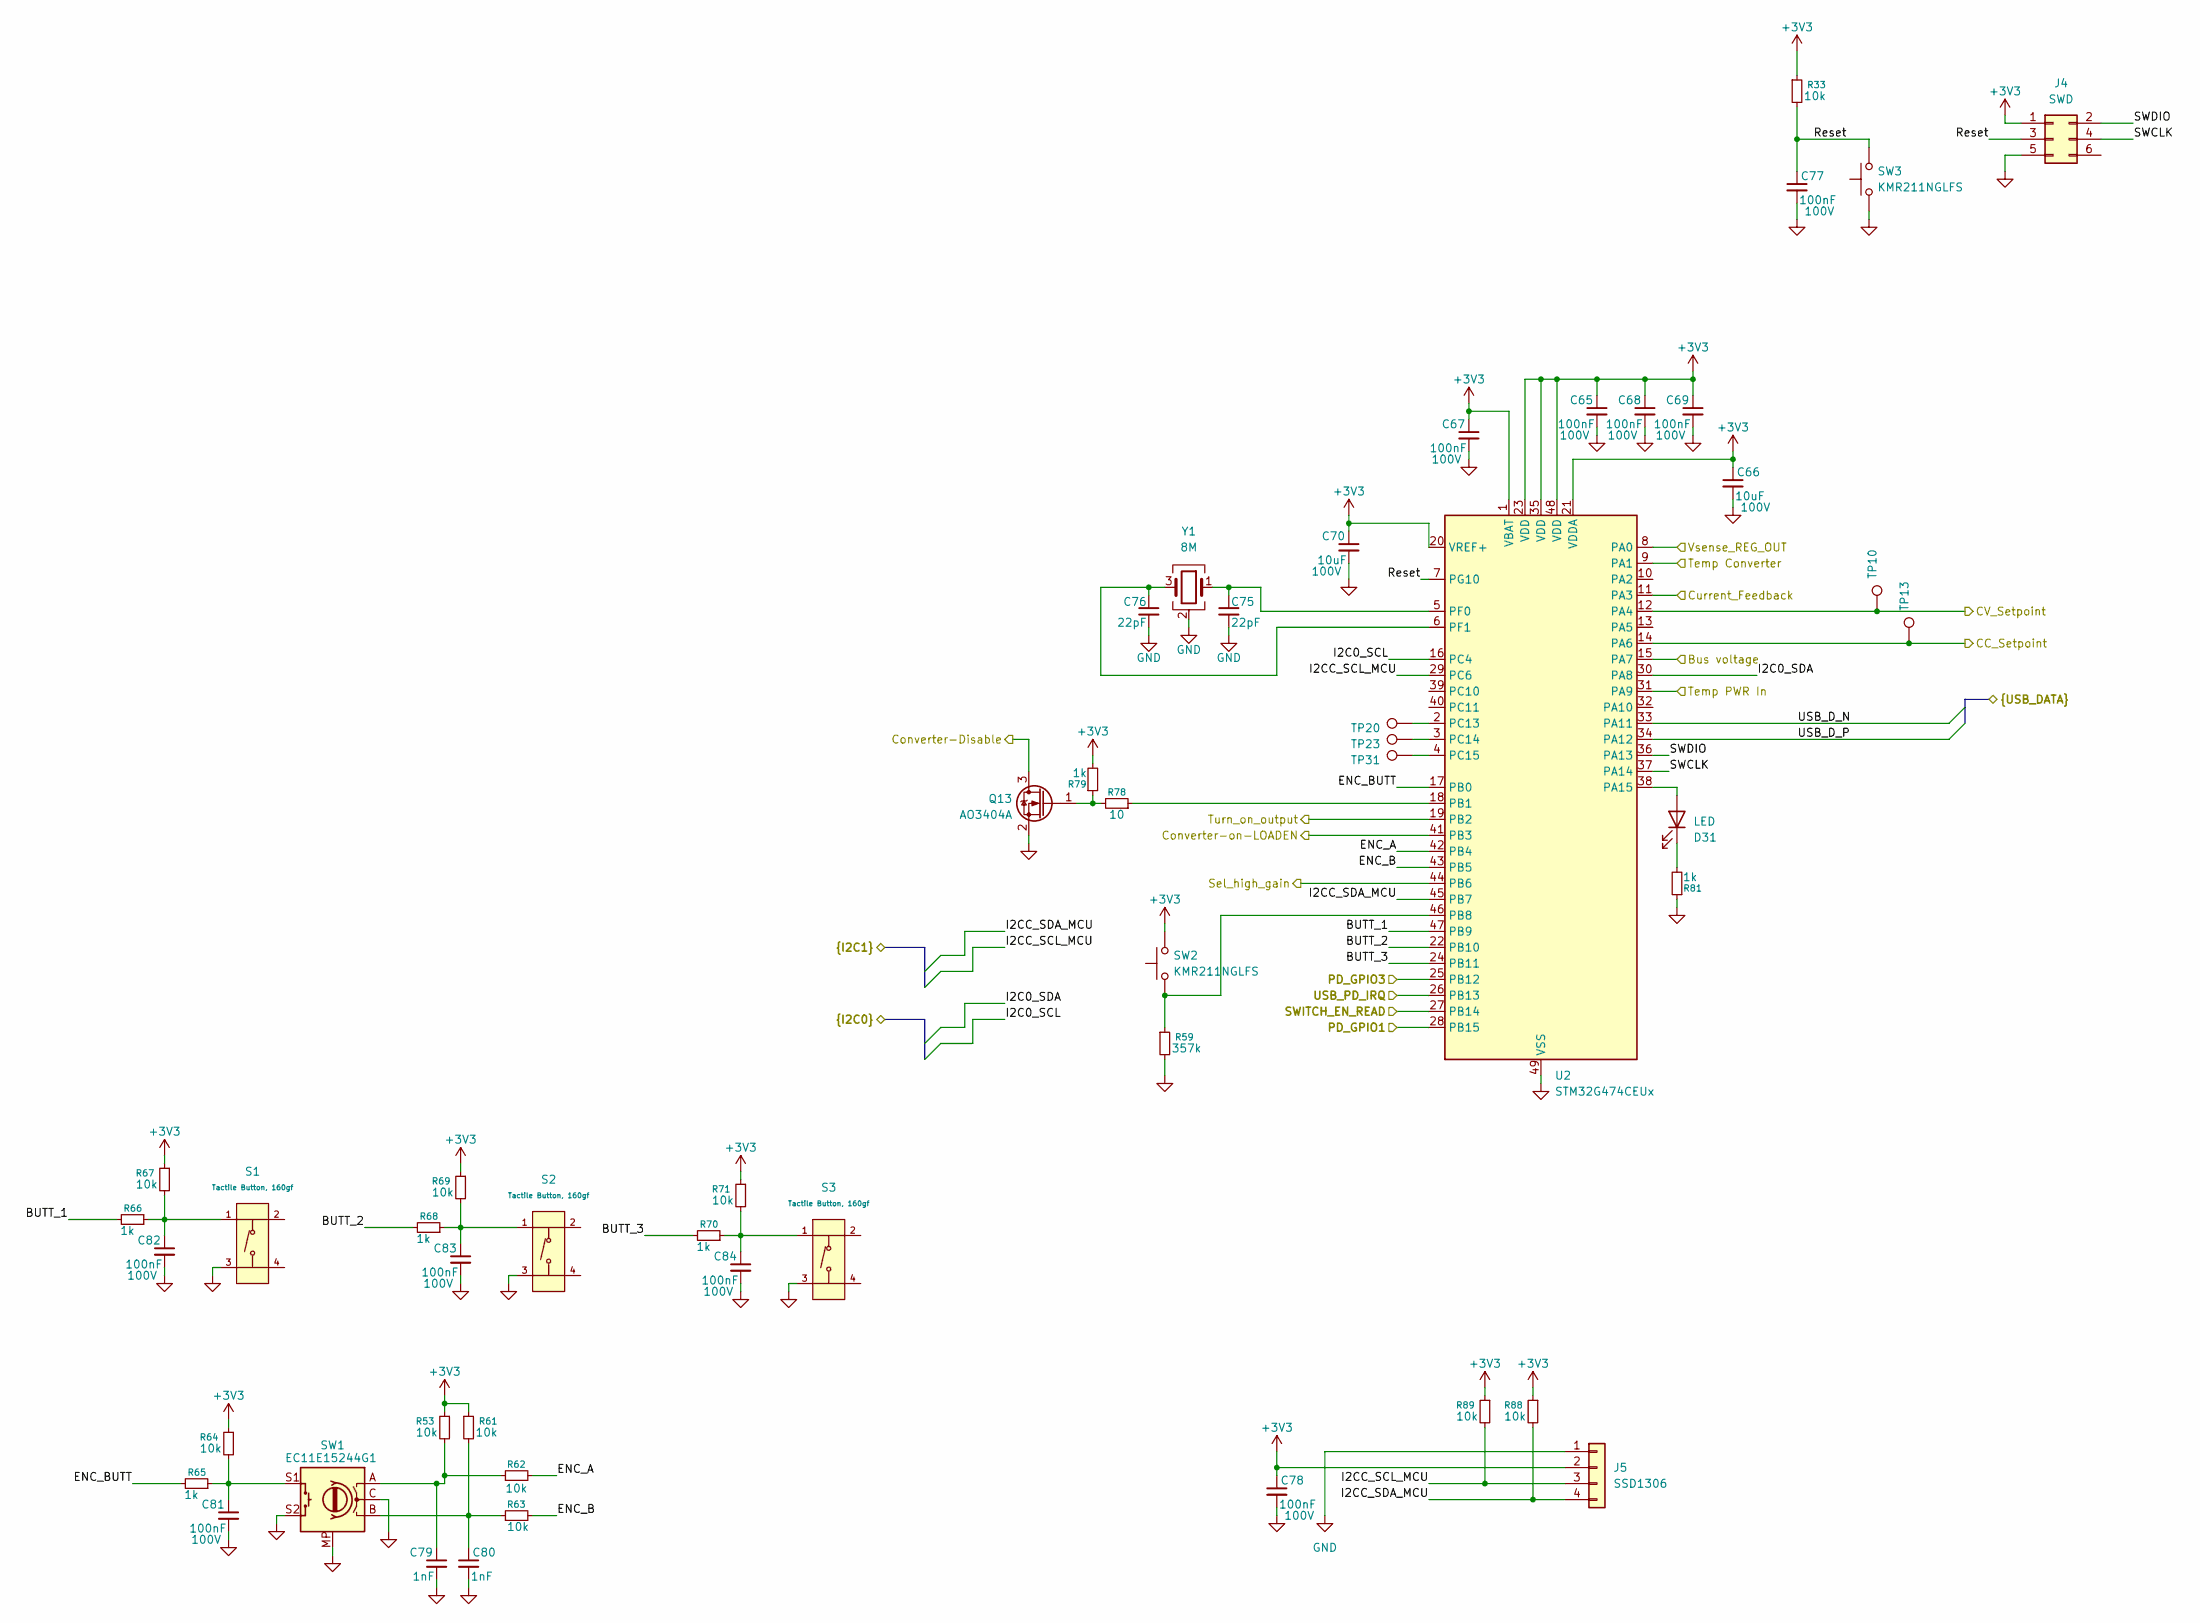
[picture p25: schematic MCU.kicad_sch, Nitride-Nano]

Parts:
C65, C67, C68, C69, C77, C78, C81, C82, C83, C84: 100nF; C_0402_1005Metric; Voltage 100V; LCSC C162178
C66, C70: 10uF; C_1210_3225Metric; Voltage 100V; LCSC C5156756
C75, C76: 22pF; C_0603_1608Metric; LCSC C1653
C79, C80: 1nF; C_0402_1005Metric; Voltage 50V; LCSC C1523
D31: LED; LED_0603_1608Metric; LCSC C2286
J4: SWD; Tag-Connect_TC2030-IDC-NL_2x03_P1.27mm_Vertical
J5: SSD1306; ssd13062
Q13: AO3404A; sot-23-3L_103p_300x130x110_n; Manufacturer Part Number AO3404A; LCSC C30010
R33, R53, R61, R62, R63, R64, R67, R69, R71, R88, R89: 10k; R_0402_1005Metric; LCSC C2906861
R59: 357k; R_0402_1005Metric; LCSC C27005
R65, R66, R68, R70, R79, R81: 1k; R_0402_1005Metric; LCSC C106235
R78: 10; R_0402_1005Metric; LCSC C25077
S1, S2, S3: Tactile Button, 160gf; SW-SMD_4P-L5.1-W5.1-P3.70-LS6.5-TL-2; Voltage Rating (Dc) 12V; Part TS-1187A-B-A-B; LCSC C318884
SW1: EC11E15244G1; RotaryEncoder_Alps_EC11E-Switch_Vertical_H20mm; JLC C370970
SW2, SW3: KMR211NGLFS; SW_Push_1P1T_NO_CK_KMR2; JLC C221676
TP10, TP13, TP20, TP23, TP31: tp_round_70; TestPoint_Pad_D1.0mm
U2: STM32G474CEUx; QFN-48-1EP_7x7mm_P0.5mm_EP5.6x5.6mm; JLC C1235412
Y1: 8M; Crystal_SMD_3225-4Pin_3.2x2.5mm; JLC C2682775

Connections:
+3V3: C65.1, C66.1, C67.1, C68.1, C69.1, C70.1, C78.1, J4.1, J5.2, R33.1, R53.1, R61.1, R64.1, R67.1, R69.1, R71.1, R79.2, R88.1, R89.1, SW2.2, U2.1 (VBAT), U2.20 (VREF+), U2.21 (VDDA), U2.23 (VDD), U2.35 (VDD), U2.48 (VDD); also elsewhere on the board
/Converter/CC_Set: TP13.1 (1_1), U2.14 (PA6); also elsewhere on the board
/Converter/CNV-EN-LOADEN: U2.41 (PB3); also elsewhere on the board
/Converter/CV_Set: TP10.1 (1_1), U2.12 (PA4); also elsewhere on the board
/Converter/Conv-Disable: Q13.3 (D); also elsewhere on the board
/Converter/High-Gain: U2.44 (PB6); also elsewhere on the board
/Converter/ISMON: U2.11 (PA3); also elsewhere on the board
/Converter/PWR_G: U2.19 (PB2); also elsewhere on the board
/Converter/TEMP_SENSE_CONV: U2.9 (PA1); also elsewhere on the board
/Converter/Vsense_REG_OUT: U2.8 (PA0); also elsewhere on the board
/MCU/BUTT_1: R66.2, U2.47 (PB9)
/MCU/BUTT_2: R68.2, U2.22 (PB10)
/MCU/BUTT_3: R70.2, U2.24 (PB11)
/MCU/Bus voltage: U2.15 (PA7); also elsewhere on the board
/MCU/ENC_A: R62.2, U2.42 (PB4)
/MCU/ENC_B: R63.2, U2.43 (PB5)
/MCU/ENC_BUTT: R65.2, U2.17 (PB0)
/MCU/I2C0_SCL: U2.16 (PC4); also elsewhere on the board
/MCU/I2C0_SDA: U2.30 (PA8); also elsewhere on the board
/MCU/I2CC_SCL_MCU: J5.3, R89.2, U2.29 (PC6); also elsewhere on the board
/MCU/I2CC_SDA_MCU: J5.4, R88.2, U2.45 (PB7); also elsewhere on the board
/MCU/Reset: C77.1, J4.3, R33.2, SW3.2, U2.7 (PG10)
/MCU/SWCLK: J4.4, U2.37 (PA14)
/MCU/SWDIO: J4.2, U2.36 (PA13)
/MCU/SWITCH_EN_READ: U2.27 (PB14)
/MCU/Temp PWR In: U2.31 (PA9); also elsewhere on the board
/MCU/USB_D_N: U2.33 (PA11); also elsewhere on the board
/MCU/USB_D_P: U2.34 (PA12); also elsewhere on the board
/USB-PD/PD_GPIO1: U2.28 (PB15); also elsewhere on the board
/USB-PD/PD_GPIO3: U2.25 (PB12); also elsewhere on the board
/USB-PD/USB_PD_IRQ: U2.26 (PB13); also elsewhere on the board
GND: C65.2, C66.2, C67.2, C68.2, C69.2, C70.2, C75.2, C76.2, C77.2, C78.2, C79.2, C80.2, C81.2, C82.2, C83.2, C84.2, J4.5, J5.1, Q13.2 (S), R59.2, R81.1, S1.3 (C), S2.3 (C), S3.3 (C), SW1.C, SW1.MP, SW1.S2, SW3.1, U2.49 (VSS), Y1.2 (G), Y1.4 (G); also elsewhere on the board
unnamed: C79.1, R53.2, R62.1, SW1.A
unnamed: C80.1, R61.2, R63.1, SW1.B
unnamed: C81.1, R64.2, R65.1, SW1.S1
unnamed: D31.2 (A), U2.38 (PA15)
unnamed: D31.1 (K), R81.2
unnamed: Q13.1 (G), R78.2, R79.1
unnamed: C82.1, R66.1, R67.2, S1.1 (A)
unnamed: C83.1, R68.1, R69.2, S2.1 (A)
unnamed: C84.1, R70.1, R71.2, S3.1 (A)
unnamed: R78.1, U2.18 (PB1)
unnamed: R59.1, SW2.1, U2.46 (PB8)
unnamed: TP20.1 (1_1), U2.2 (PC13)
unnamed: TP23.1 (1_1), U2.3 (PC14)
unnamed: TP31.1 (1_1), U2.4 (PC15)
unnamed: C75.1, U2.5 (PF0), Y1.1
unnamed: C76.1, U2.6 (PF1), Y1.3

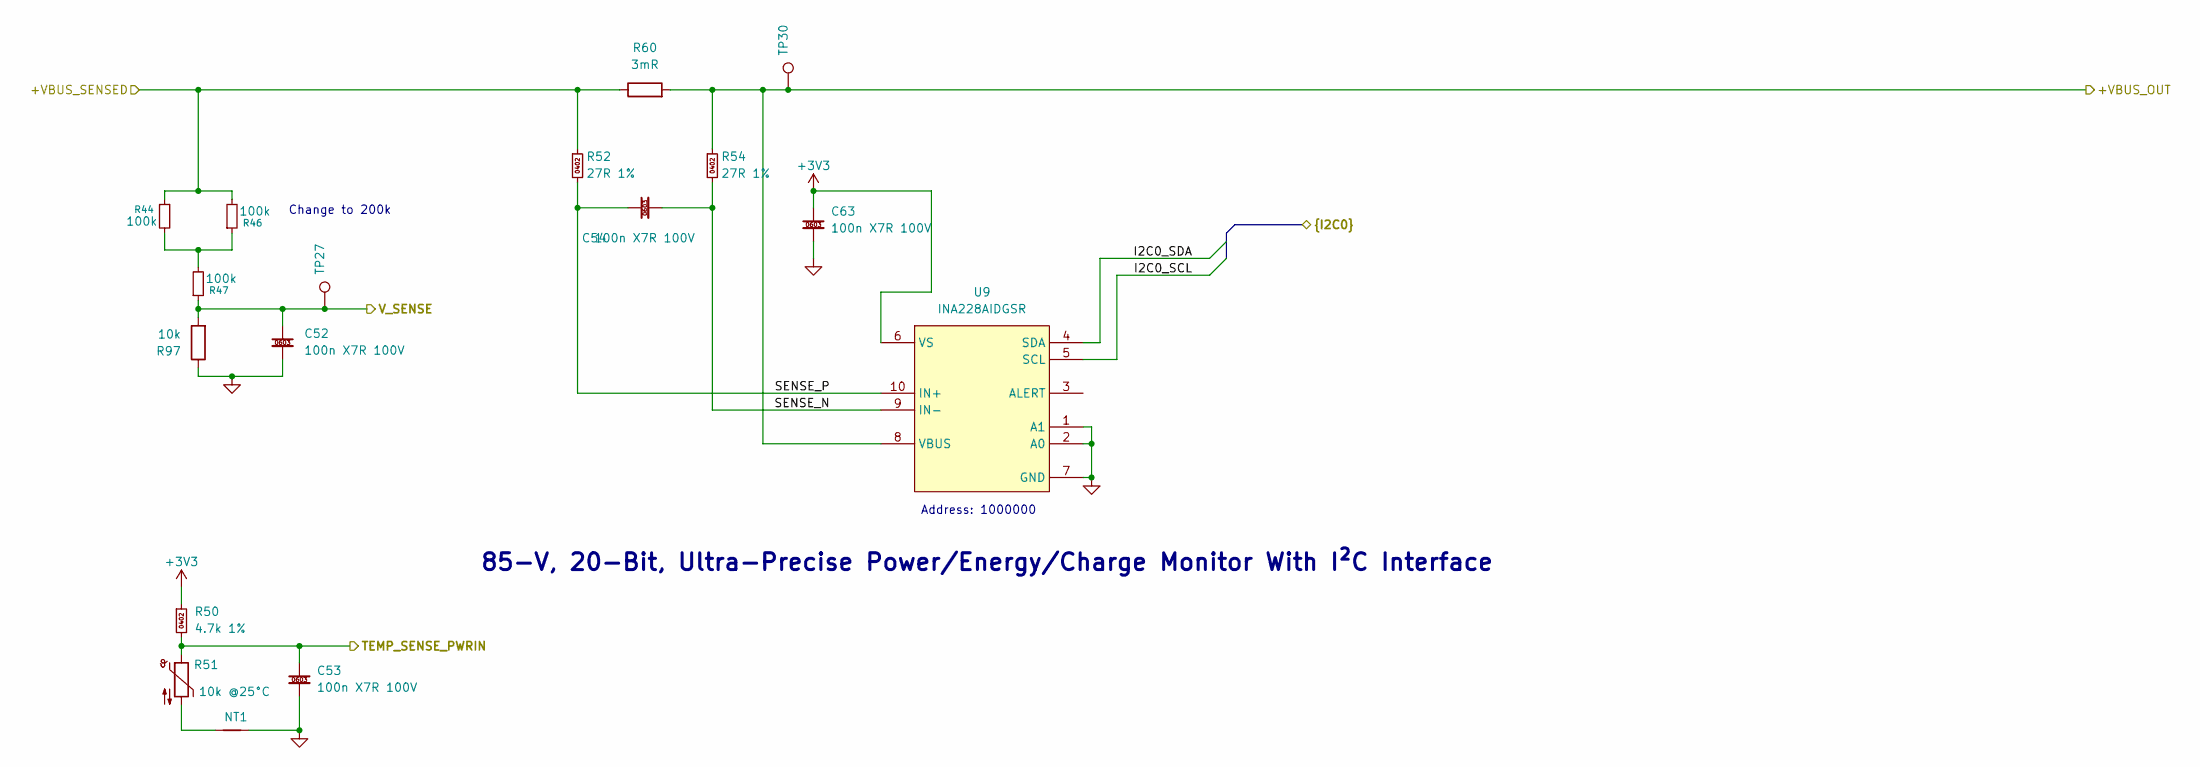
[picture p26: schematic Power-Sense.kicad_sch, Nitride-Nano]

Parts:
C52, C53, C54, C63: 100n X7R 100V; C_0603_1608Metric; Manufacturer Part Number CL10B104KC8NNNC; LCSC C15725
NT1: nt_2pad_20x20_20_60x20; NetTie-2_SMD_Pad0.5mm
R44, R46, R47: 100k; R_0402_1005Metric; LCSC C60491
R50: 4.7k 1%; R_0402_1005Metric; Manufacturer Part Number 0402WGF1003TCE; LCSC C105871
R51: 10k @25°C; R_0402_1005Metric; LCSC C77131
R52, R54: 27R 1%; R_0402_1005Metric; Manufacturer Part Number RC0402FR-0727RL; LCSC C138021
R60: 3mR; R_2512_6332Metric; JLC C41382684
R97: 10k; R_0402_1005Metric; LCSC C2906861
TP27, TP30: tp_round_70; TestPoint_Pad_D1.0mm
U9: INA228AIDGSR; vssop10_50p_300x300x110_mfg; Manufacturer Part Number INA228AIDGSR; LCSC C2887910

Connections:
+3V3: C63.1, R50.1, U9.6 (VS); also elsewhere on the board
/Converter/PWR_UNREG_IN: R54.1, R60.2, TP30.1 (1_1), U9.8 (VBUS); also elsewhere on the board
/MCU/Bus voltage: C52.1, R47.1, R97.2, TP27.1 (1_1); also elsewhere on the board
/MCU/I2C0_SCL: U9.5 (SCL); also elsewhere on the board
/MCU/I2C0_SDA: U9.4 (SDA); also elsewhere on the board
/MCU/Temp PWR In: C53.1, R50.2, R51.1; also elsewhere on the board
/Power-Sense-In/+VBUS_SENSED: R44.1, R46.2, R52.1, R60.1; also elsewhere on the board
/Power-Sense-In/SENSE_N: C54.2, R54.2, U9.9 (IN-)
/Power-Sense-In/SENSE_P: C54.1, R52.2, U9.10 (IN+)
GND: C52.2, C53.2, C63.2, NT1.1, NT1.2, R51.2, R97.1, U9.1 (A1), U9.2 (A0), U9.7 (GND); also elsewhere on the board
unnamed: R44.2, R46.1, R47.2

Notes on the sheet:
85-V, 20-Bit, Ultra-Precise Power/Energy/Charge Monitor With I²C Interface
Address: 1000000
Change to 200k

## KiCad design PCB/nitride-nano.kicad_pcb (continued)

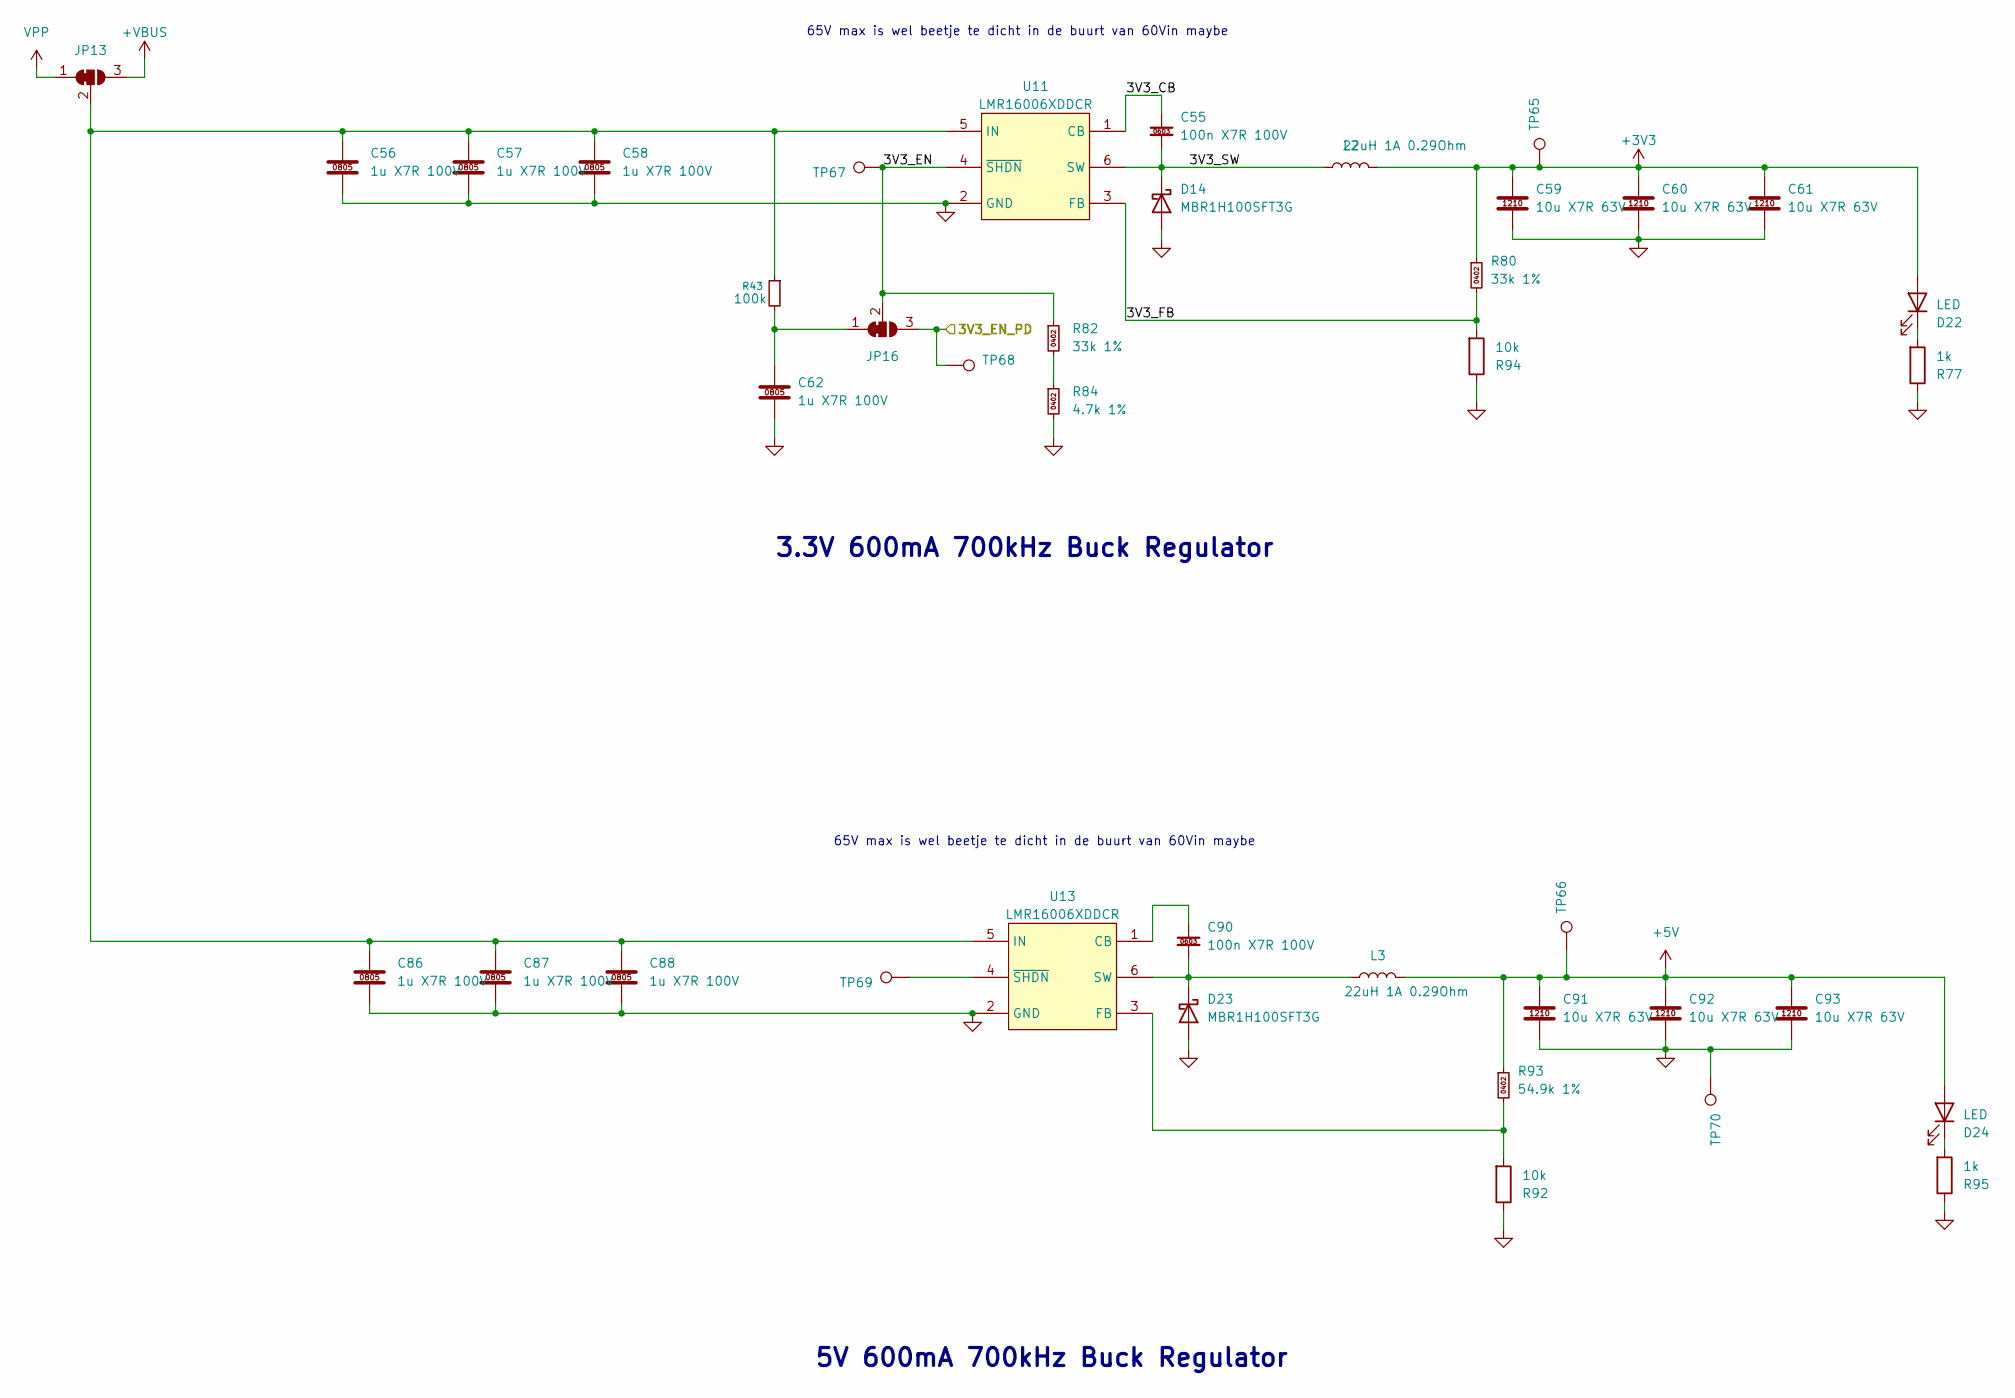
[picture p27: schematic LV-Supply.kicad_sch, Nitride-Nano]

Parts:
C55, C90: 100n X7R 100V; C_0603_1608Metric; Manufacturer Part Number CL10B104KC8NNNC; LCSC C15725
C56, C57, C58, C62, C86, C87, C88: 1u X7R 100V; C_0805_2012Metric; Manufacturer Part Number CC0805KKX7R0BB105; LCSC C5370002
C59, C60, C61, C91, C92, C93: 10u X7R 63V; C_1210_3225Metric; Manufacturer Part Number GRM32ER71J106KA12L; LCSC C437568
D14, D23: MBR1H100SFT3G; sod-123fl_305p_260x160x90_n; Manufacturer Part Number MBR1H100SFT3G; LCSC C235757
D22, D24: LED; LED_0603_1608Metric; LCSC C2286
JP13, JP16: SolderJumper_3_Bridged12; SolderJumper-3_P1.3mm_Bridged12_RoundedPad1.0x1.5mm_NumberL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
L2, L3: 22uH 1A 0.29Ohm; SWPA4030S220MT; Manufacturer Part Number SWPA4030S220MT; LCSC C83472
R43: 100k; R_0402_1005Metric; LCSC C60491
R77, R95: 1k; R_0402_1005Metric; LCSC C106235
R80, R82: 33k 1%; R_0402_1005Metric; Manufacturer Part Number RC0402FR-0733KL; LCSC C138003
R84: 4.7k 1%; R_0402_1005Metric; Manufacturer Part Number 0402WGF1003TCE; LCSC C105871
R92, R94: 10k; R_0402_1005Metric; LCSC C2906861
R93: 54.9k 1%; R_0402_1005Metric; LCSC C11626
TP65, TP66, TP67, TP68, TP69, TP70: tp_round_70; TestPoint_Pad_D1.0mm
U11, U13: LMR16006XDDCR; sot6_p95_290x180x110_n; Manufacturer Part Number LMR16006XDDCR; LCSC C87080

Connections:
+3V3: C59.1, C60.1, C61.1, D22.2 (A), L2.2, R80.1, TP65.1 (1_1); also elsewhere on the board
+5V: C91.1, C92.1, C93.1, D24.2 (A), L3.2, R93.1, TP66.1 (1_1); also elsewhere on the board
+VBUS: JP13.3 (B); also elsewhere on the board
/LV-Supply/3V3_CB: C55.1, U11.1 (CB)
/LV-Supply/3V3_EN: JP16.2 (C), R82.1, TP67.1 (1_1), U11.4 (~SHDN)
/LV-Supply/3V3_EN_PD: JP16.3 (B), TP68.1 (1_1); also elsewhere on the board
/LV-Supply/3V3_FB: R80.2, R94.2, U11.3 (FB)
/LV-Supply/3V3_SW: C55.2, D14.1 (K), L2.1, U11.6 (SW)
GND: C56.2, C57.2, C58.2, C59.2, C60.2, C61.2, C62.2, C86.2, C87.2, C88.2, C91.2, C92.2, C93.2, D14.2 (A), D23.2 (A), R77.1, R84.2, R92.1, R94.1, R95.1, TP70.1 (1_1), U11.2 (GND), U13.2 (GND); also elsewhere on the board
unnamed: D22.1 (K), R77.2
unnamed: C90.2, D23.1 (K), L3.1, U13.6 (SW)
unnamed: D24.1 (K), R95.2
unnamed: C56.1, C57.1, C58.1, C86.1, C87.1, C88.1, JP13.2 (C), R43.1, U11.5 (IN), U13.5 (IN)
unnamed: C62.1, JP16.1 (A), R43.2
unnamed: R82.2, R84.1
unnamed: C90.1, U13.1 (CB)
unnamed: R92.2, R93.2, U13.3 (FB)
unnamed: TP69.1 (1_1), U13.4 (~SHDN)
VPP: JP13.1 (A); also elsewhere on the board

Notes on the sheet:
65V max is wel beetje te dicht in de buurt van 60Vin maybe
3.3V 600mA 700kHz Buck Regulator
5V 600mA 700kHz Buck Regulator

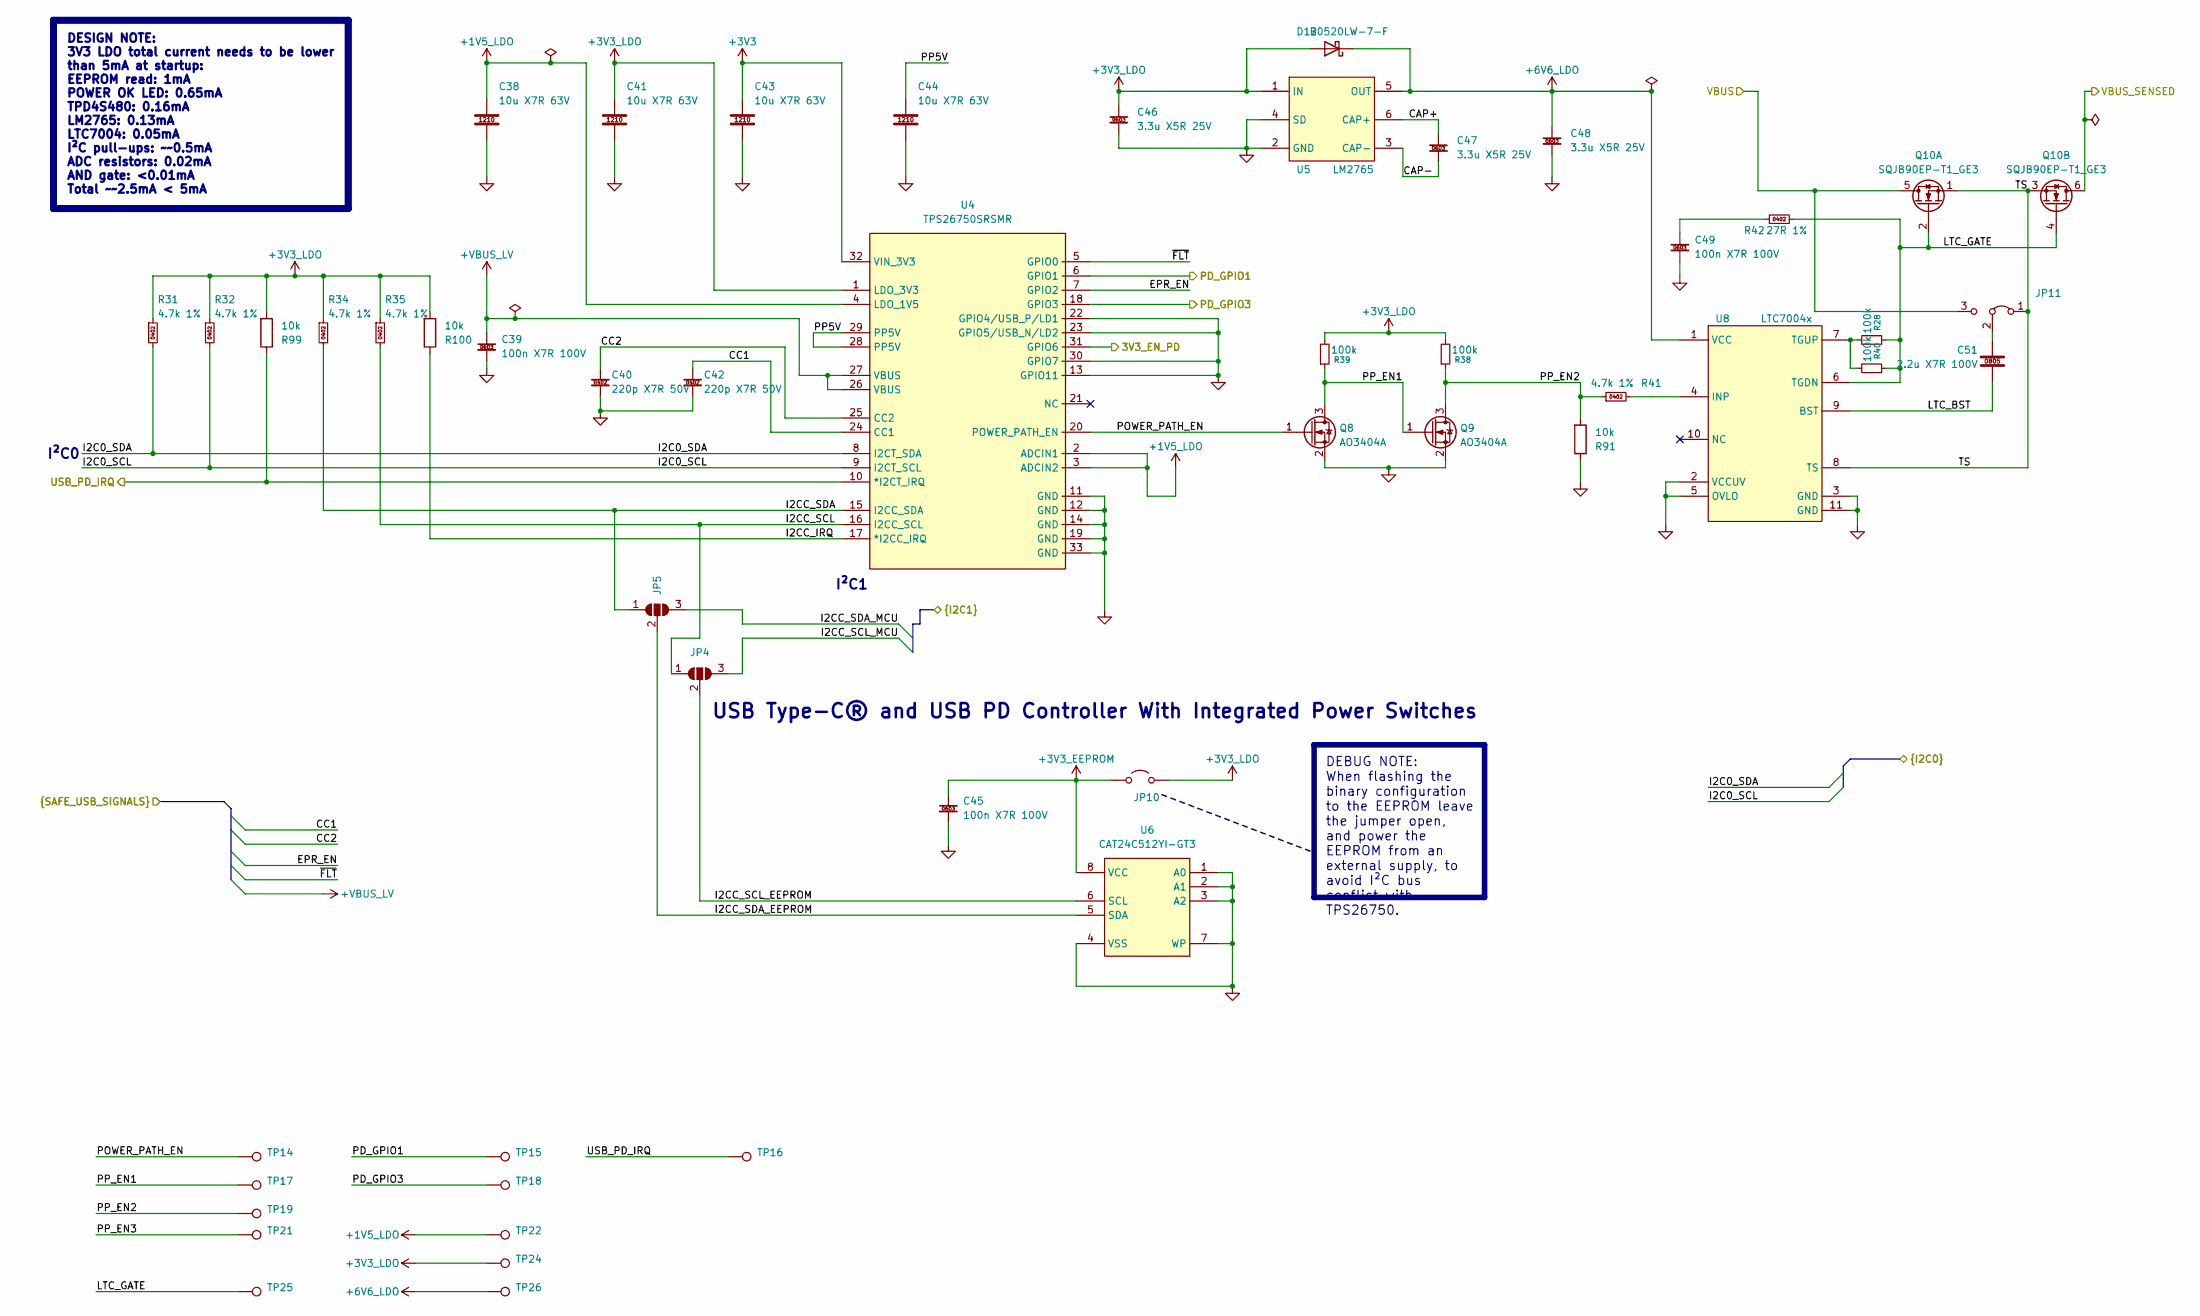
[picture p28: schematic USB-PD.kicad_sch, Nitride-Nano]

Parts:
C38, C41, C43, C44: 10u X7R 63V; C_1210_3225Metric; Manufacturer Part Number GRM32ER71J106KA12L; LCSC C437568
C39, C45, C49: 100n X7R 100V; C_0603_1608Metric; Manufacturer Part Number CL10B104KC8NNNC; LCSC C15725
C40, C42: 220p X7R 50V; C_0402_1005Metric; Manufacturer Part Number CL05B221KB5NNNC; LCSC C296710
C46, C47, C48: 3.3u X5R 25V; C_0603_1608Metric; Manufacturer Part Number TCC0603X5R335M250CT; LCSC C5360803
C51: 2.2u X7R 100V; C_0805_2012Metric; Manufacturer Part Number HHV0805R7225K101NSLJ; LCSC C22367838
D12: B0520LW-7-F; sod-123_270x155135_n; Manufacturer Part Number B0520LW-7-F; LCSC C155367
JP4, JP5: SolderJumper_3_Open; SolderJumper-3_P1.3mm_Open_RoundedPad1.0x1.5mm
JP10: jumper_solder_2pad_no_kicad; SolderJumper-2_P1.3mm_Open_RoundedPad1.0x1.5mm
JP11: jumper_solder_3pad_12nc_kicad; SolderJumper-3_P1.3mm_Bridged2Bar12_RoundedPad1.0x1.5mm
Q8, Q9: AO3404A; sot-23-3L_103p_300x130x110_n; Manufacturer Part Number AO3404A; LCSC C30010
Q10: SQJB90EP-T1_GE3; PowerPAKSO-8_127p_513x615x120_n; Manufacturer Part Number SQJB90EP-T1_GE3; LCSC C727731
R28, R38, R39, R40: 100k; R_0402_1005Metric; LCSC C60491
R31, R32, R34, R35, R41: 4.7k 1%; R_0402_1005Metric; Manufacturer Part Number 0402WGF1003TCE; LCSC C105871
R42: 27R 1%; R_0402_1005Metric; Manufacturer Part Number RC0402FR-0727RL; LCSC C138021
R91, R99, R100: 10k; R_0402_1005Metric; LCSC C2906861
TP14, TP15, TP16, TP17, TP18, TP19, TP21, TP22, TP24, TP25, TP26: tp_round_70; TestPoint_Pad_D1.0mm
U4: TPS26750SRSMR; qfn32_40p_400x400x100_tp_280x280_mfg; Manufacturer Part Number TPS26750SRSMR; LCSC C42166327
U5: LM2765; sot236_p95_290x160x110_n; Manufacturer Part Number LM2765M6X/NOPB; LCSC C140270
U6: CAT24C512YI-GT3; JEDEC_MO-153_AA; Manufacturer Part Number CAT24C512YI-GT3; LCSC C56096
U8: LTC7004x; msop_10p_300x490x110_tp168x188_n; Manufacturer Part Number LTC7004EMSE#TRPBF; LCSC C690106

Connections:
+1V5_LDO: C38.1, TP22.1 (1_1), U4.2 (ADCIN1), U4.3 (ADCIN2), U4.4 (LDO_1V5)
+3V3: C43.1, U4.32 (VIN_3V3); also elsewhere on the board
+3V3_EEPROM: C45.1, JP10.1 (A), U6.8 (VCC)
+3V3_LDO: C41.1, C46.1, D12.2 (A), JP10.2 (B), R31.1, R32.1, R34.1, R35.1, R38.2, R39.2, R99.2, R100.2, TP24.1 (1_1), U4.1 (LDO_3V3), U5.1 (IN); also elsewhere on the board
+6V6_LDO: C48.1, D12.1 (K), TP26.1 (1_1), U5.5 (OUT), U8.1 (VCC)
+VBUS: JP11.3 (B), Q10.5 (D); also elsewhere on the board
+VBUS_LV: C39.1, U4.26 (VBUS), U4.27 (VBUS); also elsewhere on the board
/LV-Supply/3V3_EN_PD: U4.31 (GPIO6); also elsewhere on the board
/MCU/I2C0_SCL: R32.2, U4.9 (I2CT_SCL); also elsewhere on the board
/MCU/I2C0_SDA: R31.2, U4.8 (I2CT_SDA); also elsewhere on the board
/MCU/I2CC_SCL_MCU: JP4.3 (B); also elsewhere on the board
/MCU/I2CC_SDA_MCU: JP5.3 (B); also elsewhere on the board
/Power-Sense-In/+VBUS_SENSED: Q10.6 (D); also elsewhere on the board
/USB-PD/CAP+: C47.1, U5.6 (CAP+)
/USB-PD/CAP-: C47.2, U5.3 (CAP-)
/USB-PD/CC1: C42.1, U4.24 (CC1); also elsewhere on the board
/USB-PD/CC2: C40.1, U4.25 (CC2); also elsewhere on the board
/USB-PD/EPR_EN: U4.7 (GPIO2); also elsewhere on the board
/USB-PD/I2CC_IRQ: R100.1, U4.17 (*I2CC_IRQ)
/USB-PD/I2CC_SCL: JP4.1 (A), R35.2, U4.16 (I2CC_SCL)
/USB-PD/I2CC_SCL_EEPROM: JP4.2 (C), U6.6 (SCL)
/USB-PD/I2CC_SDA: JP5.1 (A), R34.2, U4.15 (I2CC_SDA)
/USB-PD/I2CC_SDA_EEPROM: JP5.2 (C), U6.5 (SDA)
/USB-PD/LTC_BST: C51.2, U8.9 (BST)
/USB-PD/LTC_GATE: Q10.2 (G), Q10.4 (G), R28.1, R40.1, R42.2, TP25.1 (1_1), U8.6 (TGDN)
/USB-PD/PD_GPIO1: TP15.1 (1_1), U4.6 (GPIO1); also elsewhere on the board
/USB-PD/PD_GPIO3: TP18.1 (1_1), U4.18 (GPIO3); also elsewhere on the board
/USB-PD/POWER_PATH_EN: Q8.1 (G), TP14.1 (1_1), U4.20 (POWER_PATH_EN)
/USB-PD/PP5V: C44.1, U4.28 (PP5V), U4.29 (PP5V)
/USB-PD/PP_EN1: Q8.3 (D), Q9.1 (G), R39.1, TP17.1 (1_1)
/USB-PD/PP_EN2: Q9.3 (D), R38.1, R41.1, R91.2, TP19.1 (1_1)
/USB-PD/PP_EN3: TP21.1 (1_1)
/USB-PD/TS: JP11.1 (A), Q10.1 (S), Q10.3 (S), U8.8 (TS)
/USB-PD/USB_PD_IRQ: R99.1, TP16.1 (1_1), U4.10 (*I2CT_IRQ); also elsewhere on the board
/USB-PD/~FLT: U4.5 (GPIO0); also elsewhere on the board
GND: C38.2, C39.2, C40.2, C41.2, C42.2, C43.2, C44.2, C45.2, C46.2, C48.2, C49.2, Q8.2 (S), Q9.2 (S), R91.1, U4.11 (GND), U4.12 (GND), U4.13 (GPIO11), U4.14 (GND), U4.19 (GND), U4.22 (GPIO4/USB_P/LD1), U4.23 (GPIO5/USB_N/LD2), U4.30 (GPIO7), U4.33 (GND), U5.2 (GND), U5.4 (SD), U6.1 (A0), U6.2 (A1), U6.3 (A2), U6.4 (VSS), U6.7 (WP), U8.2 (VCCUV), U8.3 (GND), U8.5 (OVLO), U8.11 (GND); also elsewhere on the board
unnamed: C49.1, R42.1
unnamed: C51.1, JP11.2 (C)
unnamed: R41.2, U8.4 (INP)
unnamed: R28.2, R40.2, U8.7 (TGUP)

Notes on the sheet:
USB Type-C® and USB PD Controller With Integrated Power Switches
I²C1
I²C0
DEBUG NOTE: When flashing the binary configuration to the EEPROM leave the jumper open, and power the EEPROM from an external supply, to avoid I²C bus conflict with TPS26750.
DESIGN NOTE: 3V3 LDO total current needs to be lower than 5mA at startup: EEPROM read: 1mA POWER OK LED: 0.65mA TPD4S480: 0.16mA LM2765: 0.13mA LTC7004: 0.05mA I²C pull-ups: ~~0.5mA ADC resistors: 0.02mA AND gate: <0.01mA Total ~~2.5mA < 5mA

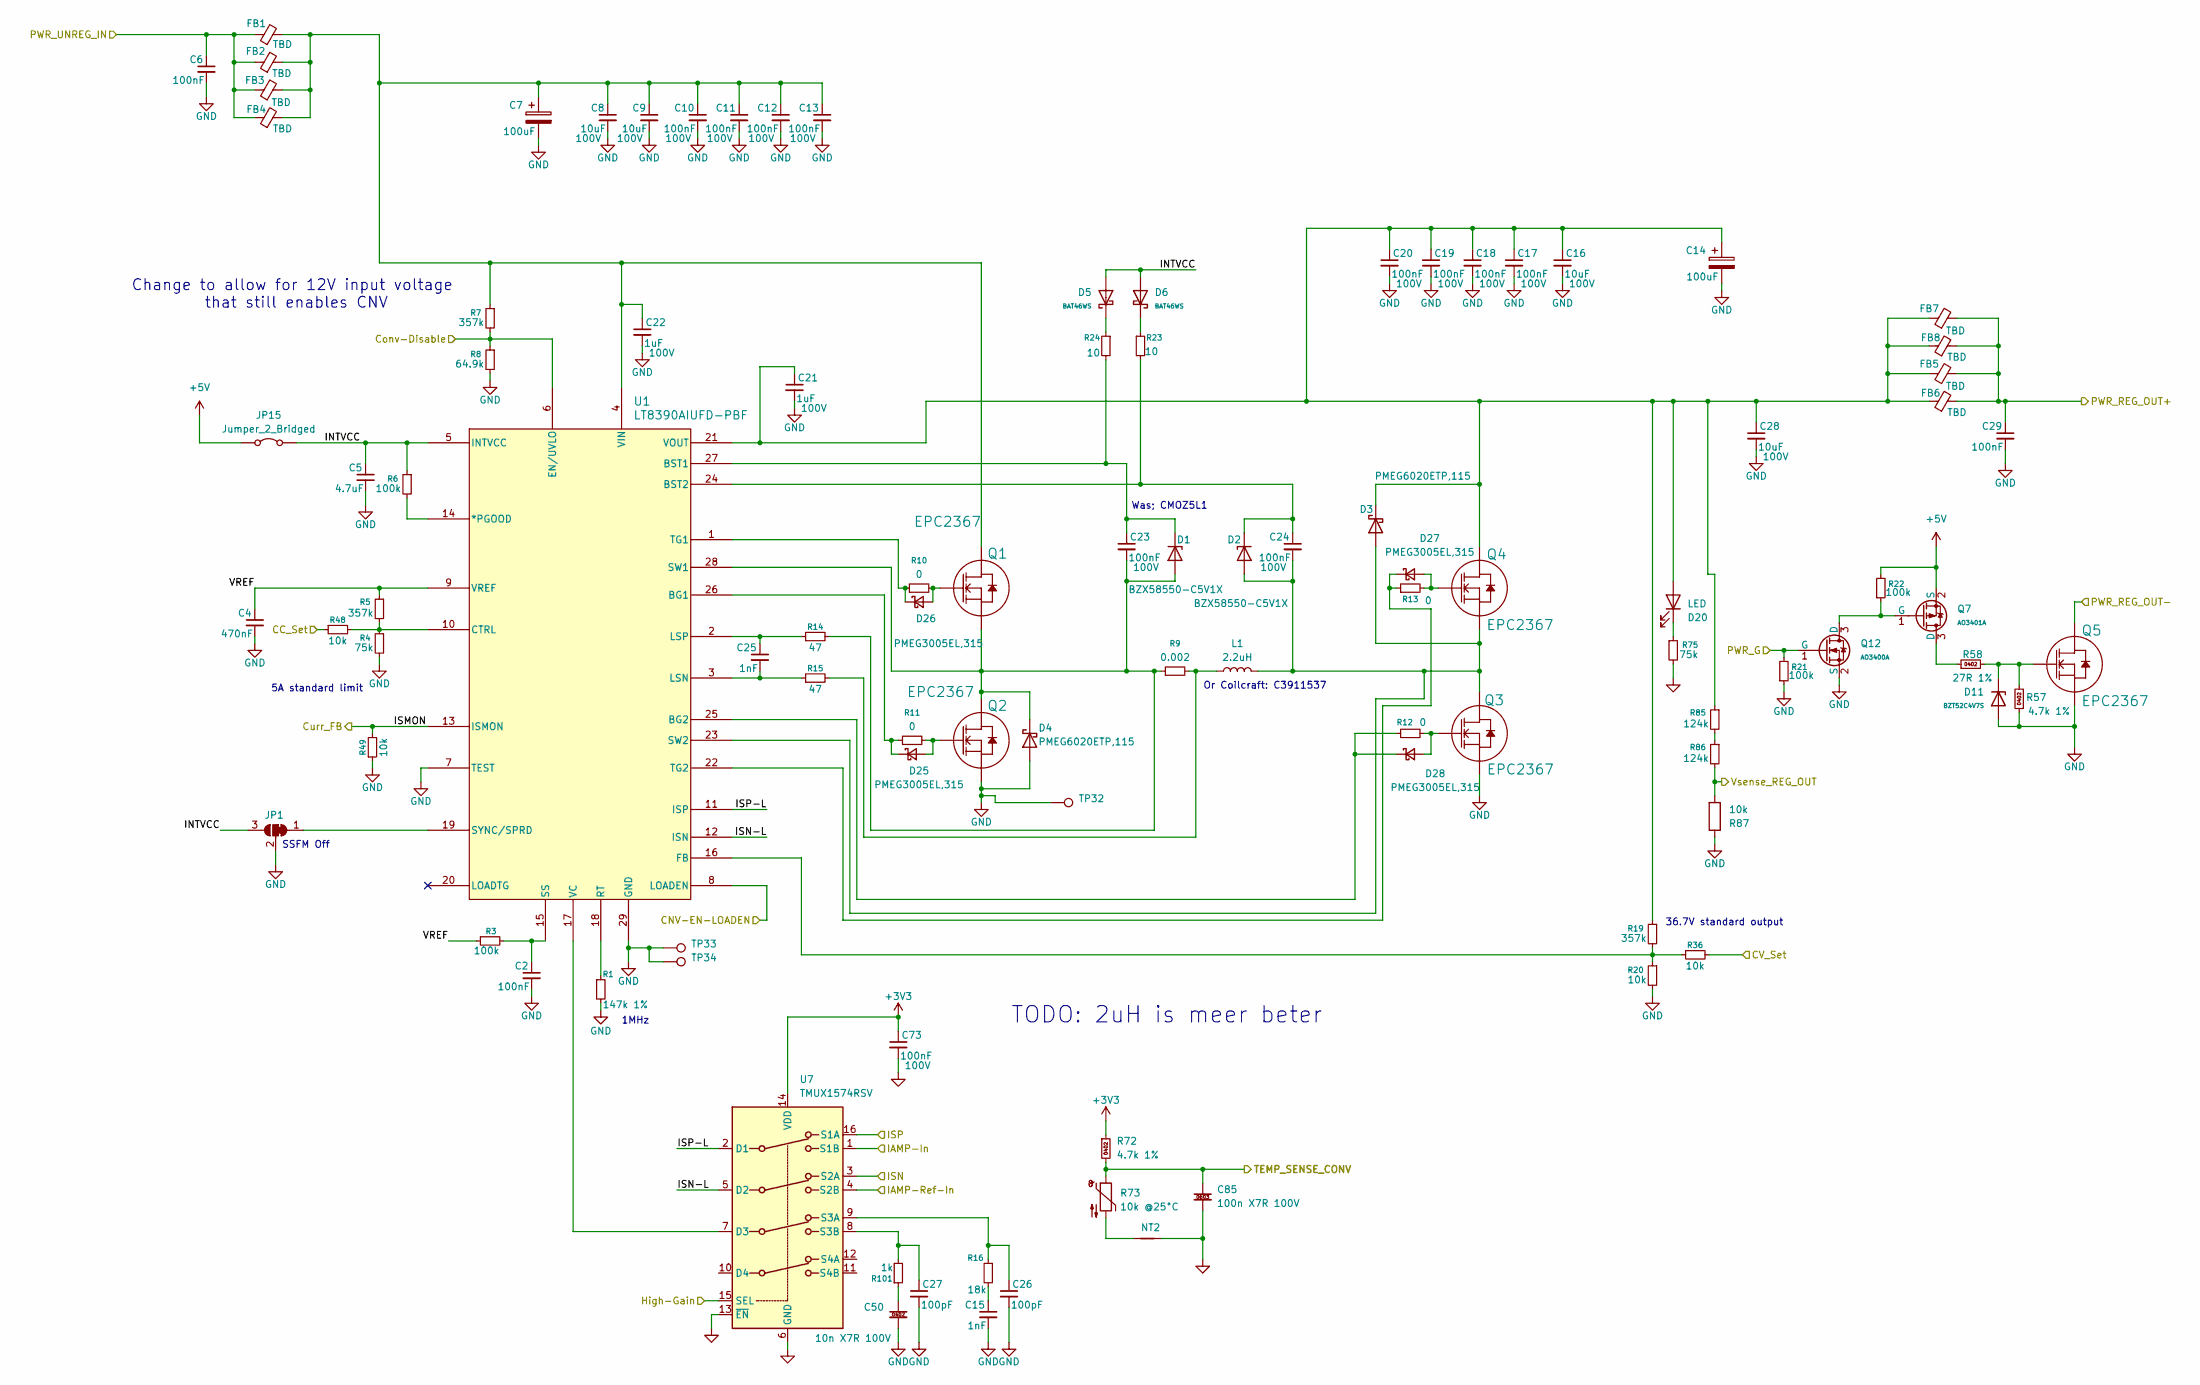
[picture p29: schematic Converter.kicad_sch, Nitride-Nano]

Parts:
C2, C6, C29: 100nF; C_0402_1005Metric; LCSC C162178
C4: 470nF; C_0402_1005Metric; LCSC C7393859
C5: 4.7uF; C_0402_1005Metric; LCSC C23733
C7, C14: 100uF; CP_Elec_10x12.6; Voltage 100V; JLC C3274502
C8, C9, C16, C28: 10uF; C_1210_3225Metric; Voltage 100V; LCSC C5156756
C10, C11, C12, C13, C17, C18, C19, C20, C23, C24, C73: 100nF; C_0402_1005Metric; Voltage 100V; LCSC C162178
C15, C25: 1nF; C_0402_1005Metric; Voltage 50V; LCSC C1523
C21, C22: 1uF; C_0603_1608Metric; Voltage 100V; LCSC C23829972
C26, C27: 100pF; C_0402_1005Metric
C50: 10n X7R 100V; C_0402_1005Metric; Manufacturer Part Number CC0402KRX7R0BB103; LCSC C527014
C85: 100n X7R 100V; C_0603_1608Metric; Manufacturer Part Number CL10B104KC8NNNC; LCSC C15725
D1, D2: BZX58550-C5V1X; D_SOD-523; JLC C3736541
D3, D4: PMEG6020ETP,115; D_SOD-128; LCSC C179434
D5, D6: BAT46WS; D_SOD-323; Forward Voltage (Vf@If) 1V@250mA; Reverse Voltage (Vr) 100V; Part BAT46WS; LCSC C7502692
D11: BZT52C4V7S; D_SOD-323; Part BZT52C4V7S; LCSC C19077439
D20: LED; LED_0603_1608Metric; LCSC C2286
D25, D26, D27, D28: PMEG3005EL,315; D_SOD-882; JLC C282565
FB1, FB2, FB3, FB4, FB5, FB6, FB7, FB8: TBD; L_1210_3225Metric; LCSC C48543473
JP1: SolderJumper_3_Bridged12; SolderJumper-3_P1.3mm_Bridged12_RoundedPad1.0x1.5mm_NumberL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
JP15: Jumper_2_Bridged; SolderJumper-2_P1.3mm_Bridged_RoundedPad1.0x1.5mm
L1: 2.2uH; IND-SMD_L7.5-W7.2-1; JLC C5125746
NT2: nt_2pad_20x20_20_60x20; NetTie-2_SMD_Pad0.5mm
Q1, Q2, Q3, Q4, Q5: EPC2367; D1068; Part Number EPC2367
Q7: AO3401A; Q_SOT-23; Part AO3401A; LCSC C15127
Q12: AO3400A; Q_SOT-23; Part AO3400A; LCSC C20917
R1: 147k 1%; R_0402_1005Metric; LCSC C64171
R3, R21, R22: 100k; R_0402_1005Metric
R4, R75: 75k; R_0402_1005Metric; LCSC C25798
R5, R7, R19: 357k; R_0402_1005Metric; LCSC C27005
R6: 100k; R_0402_1005Metric; LCSC C60491
R8: 64.9k; R_0402_1005Metric; LCSC C26984
R9: 0.002; R_1206_3216Metric; JLC C46635910
R10: 0; R_0402_1005Metric; JLC C60485
R11, R13: 0; R_0402_1005Metric; LCSC C60485
R12: 0; R_0402_1005Metric; LCSC C25148
R14, R15: 47; R_0402_1005Metric; LCSC C25118
R16: 18k; R_0402_1005Metric; LCSC C25762
R20, R36, R48, R49, R87: 10k; R_0402_1005Metric; LCSC C2906861
R23, R24: 10; R_0402_1005Metric; LCSC C25077
R57, R72: 4.7k 1%; R_0402_1005Metric; Manufacturer Part Number 0402WGF1003TCE; LCSC C105871
R58: 27R 1%; R_0402_1005Metric; Manufacturer Part Number RC0402FR-0727RL; LCSC C138021
R73: 10k @25°C; R_0402_1005Metric; LCSC C77131
R85, R86: 124k; R_0402_1005Metric; LCSC C36777
R101: 1k; R_0402_1005Metric; LCSC C106235
TP32, TP33, TP34: tp_round_70; TestPoint_Pad_D1.0mm
U1: LT8390AIUFD-PBF; UFD_28_ADI; LCSC C673800
U7: TMUX1574RSV; UQFN-16_1.8x2.6mm_P0.4mm; JLC C2673120

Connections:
+3V3: C73.1, R72.1, U7.14 (VDD); also elsewhere on the board
+5V: JP15.1 (A), Q7.2 (S), R22.2; also elsewhere on the board
/Converter/CC_Set: R48.1; also elsewhere on the board
/Converter/CNV-EN-LOADEN: U1.8 (LOADEN); also elsewhere on the board
/Converter/CV_Set: R36.2; also elsewhere on the board
/Converter/Conv-Disable: R7.2, R8.1, U1.6 (EN/UVLO); also elsewhere on the board
/Converter/High-Gain: U7.15 (SEL); also elsewhere on the board
/Converter/IAMP-In: U7.1 (S1B); also elsewhere on the board
/Converter/IAMP-Ref-In: U7.4 (S2B); also elsewhere on the board
/Converter/INTVCC: C5.1, D5.2, D6.2, JP1.3 (B), JP15.2 (B), R6.1, U1.5 (INTVCC)
/Converter/ISMON: R49.2, U1.13 (ISMON); also elsewhere on the board
/Converter/ISN-L: U1.12 (ISN), U7.5 (D2)
/Converter/ISP-L: U1.11 (ISP), U7.2 (D1)
/Converter/PWR_G: Q12.1 (G), R21.2; also elsewhere on the board
/Converter/PWR_REG_OUT+: C29.1, FB5.2, FB6.2, FB7.2, FB8.2; also elsewhere on the board
/Converter/PWR_REG_OUT-: Q5.3 (D), Q5.5 (D); also elsewhere on the board
/Converter/PWR_UNREG_IN: C6.1, FB1.1, FB2.1, FB3.1, FB4.1; also elsewhere on the board
/Converter/TEMP_SENSE_CONV: C85.1, R72.2, R73.1; also elsewhere on the board
/Converter/VREF: C4.1, R3.1, R5.1, U1.9 (VREF)
/Converter/Vsense_REG_OUT: R86.2, R87.2; also elsewhere on the board
/Power-Sense-Out/SENSE_N: U7.3 (S2A); also elsewhere on the board
/Power-Sense-Out/SENSE_P: U7.16 (S1A); also elsewhere on the board
GND: C2.2, C4.2, C5.2, C6.2, C7.2, C8.2, C9.2, C10.2, C11.2, C12.2, C13.2, C14.2, C15.2, C16.2, C17.2, C18.2, C19.2, C20.2, C21.2, C22.2, C26.2, C27.2, C28.2, C29.2, C50.2, C73.2, C85.2, D4.2 (A), D11.2, JP1.2 (C), NT2.2, Q2.2 (S), Q2.4 (S), Q3.2 (S), Q3.4 (S), Q5.2 (S), Q5.4 (S), Q12.2 (S), R1.2, R4.2, R8.2, R20.2, R21.1, R49.1, R57.1, R75.2, R87.1, TP32.1 (1_1), TP33.1 (1_1), TP34.1 (1_1), U1.7 (TEST), U1.29 (GND), U7.6 (GND), U7.13 (~EN); also elsewhere on the board
unnamed: C15.1, R16.2
unnamed: C50.1, R101.1
unnamed: C23.2, D1.2 (A), D4.1 (K), Q1.2 (S), Q1.4 (S), Q2.3 (D), Q2.5 (D), R9.1, R14.2, U1.28 (SW1)
unnamed: C23.1, D1.1 (K), R24.2, U1.27 (BST1)
unnamed: C24.2, D2.2 (A), D3.2 (A), L1.2, Q3.3 (D), Q3.5 (D), Q4.2 (S), Q4.4 (S), U1.23 (SW2)
unnamed: C24.1, D2.1 (K), R23.2, U1.24 (BST2)
unnamed: D5.1, R24.1
unnamed: D6.1, R23.1
unnamed: C14.1, C16.1, C17.1, C18.1, C19.1, C20.1, C21.1, C28.1, D3.1 (K), D20.2 (A), FB5.1, FB6.1, FB7.1, FB8.1, Q4.3 (D), Q4.5 (D), R19.1, R85.1, U1.21 (VOUT)
unnamed: D20.1 (K), R75.1
unnamed: D25.2 (A), Q2.1 (G), R11.2
unnamed: D25.1 (K), R11.1, U1.26 (BG1)
unnamed: D26.2 (A), Q1.1 (G), R10.2
unnamed: D26.1 (K), R10.1, U1.1 (TG1)
unnamed: D27.2 (A), Q4.1 (G), R13.2
unnamed: D27.1 (K), R13.1, U1.22 (TG2)
unnamed: D28.2 (A), Q3.1 (G), R12.2
unnamed: D28.1 (K), R12.1, U1.25 (BG2)
unnamed: JP1.1 (A), U1.19 (SYNC/SPRD)
unnamed: L1.1, R9.2, R15.2
unnamed: NT2.1, R73.2
unnamed: D11.1, Q5.1 (G), R57.2, R58.2
unnamed: Q7.3 (D), R58.1
unnamed: Q7.1 (G), Q12.3 (D), R22.1
unnamed: R85.2, R86.1
unnamed: R6.2, U1.14 (*PGOOD)
unnamed: R4.1, R5.2, R48.2, U1.10 (CTRL)
unnamed: R19.2, R20.1, R36.1, U1.16 (FB)
unnamed: C25.2, R15.1, U1.3 (LSN)
unnamed: C25.1, R14.1, U1.2 (LSP)
unnamed: R1.1, U1.18 (RT)
unnamed: C2.1, R3.2, U1.15 (SS)
unnamed: U1.17 (VC), U7.7 (D3)
unnamed: C7.1, C8.1, C9.1, C10.1, C11.1, C12.1, C13.1, C22.1, FB1.2, FB2.2, FB3.2, FB4.2, Q1.3 (D), Q1.5 (D), R7.1, U1.4 (VIN)
unnamed: C26.1, R16.1, U7.9 (S3A)
unnamed: C27.1, R101.2, U7.8 (S3B)

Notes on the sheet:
Or Coilcraft: C3911537
1MHz
Was; CMOZ5L1
5A standard limit
36.7V standard output
SSFM Off
TODO: 2uH is meer beter
Change to allow for 12V input voltage that still enables CNV

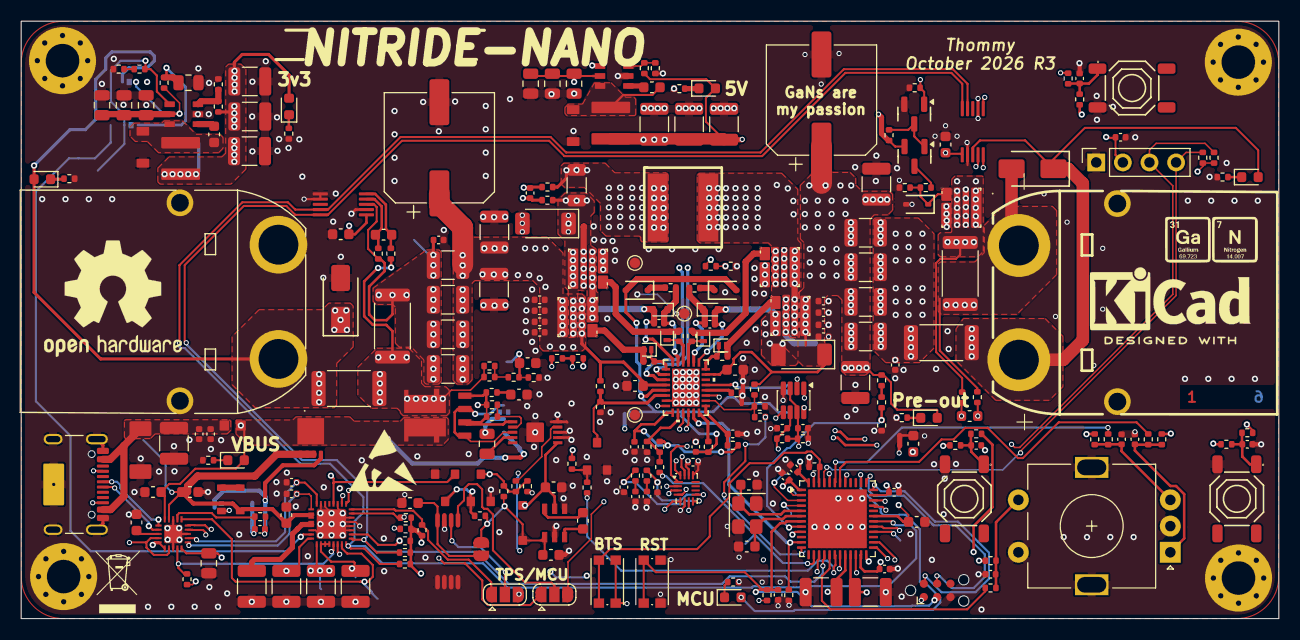
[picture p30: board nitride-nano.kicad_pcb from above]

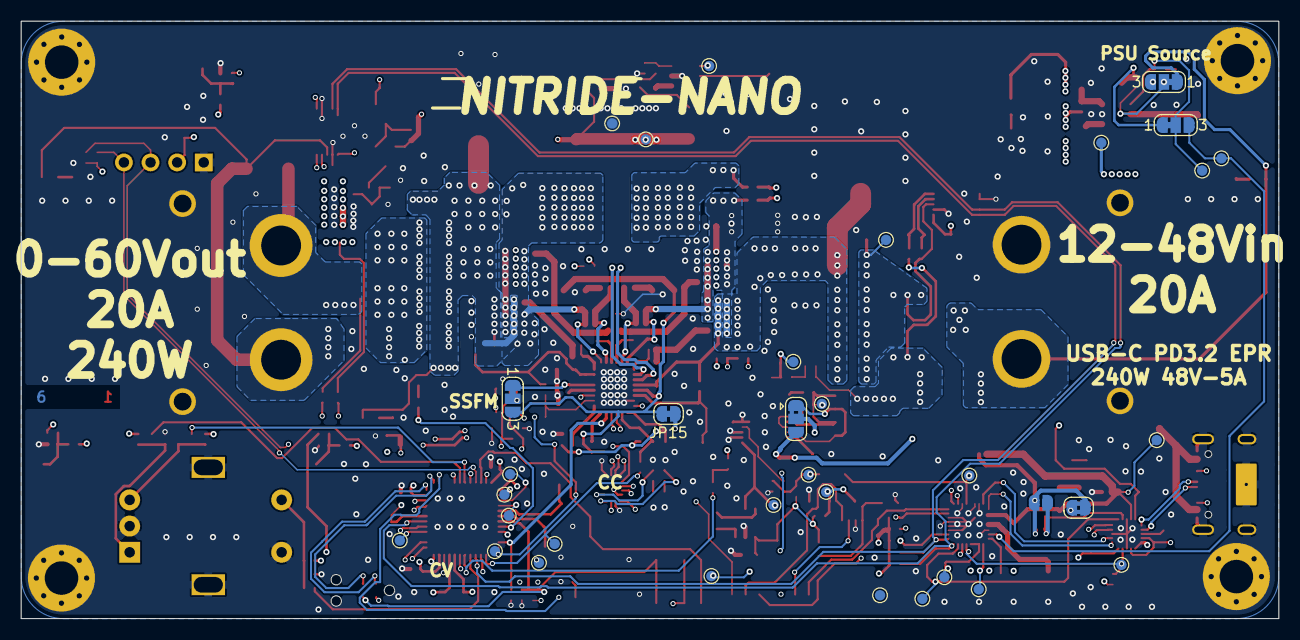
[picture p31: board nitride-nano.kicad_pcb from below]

Board: 6 copper layers, 120.0 x 57.0 mm, 305 parts (34 on the bottom side), 157 nets.

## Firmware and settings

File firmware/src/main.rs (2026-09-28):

//! nitride-nano — USB-PD bench power supply firmware (STM32G474, Embassy).
//!
//! Structure: this entry point owns all peripherals and runs the cooperative
//! main loop (input → ADC → sweep/supply tick → PD poll → EEPROM step). A single
//! Embassy task (`ui_task`) renders the OLED. Shared state flows through the
//! `APP_STATE` mutex and the two I2C bus mutexes in [`nitride_firmware::runtime`];
//! the lock order (APP_STATE before either bus, never both buses) documented
//! there is load-bearing.
//!
//! Timing contract (do not change without re-tuning the control loop):
//! input 5 ms, ADC 2 ms, supply tick 1 ms, PD/INA228 100 ms, EEPROM step every
//! pass, plus a 100 µs yield at the bottom of the loop.
//!
//! Service mode ([`nitride_firmware::service`]) lets a running board hand off to
//! the ST ROM bootloader so it can be reflashed over UART; see
//! [`nitride_firmware::hal::bootloader`].

#![no_std]
#![no_main]

use core::sync::atomic::Ordering;

use defmt_rtt as _;
use embassy_executor::Spawner;
use embassy_stm32::adc::{Adc, Resolution, SampleTime};
use embassy_stm32::dac::{DacCh1, DacChannel, Value};
use embassy_stm32::exti::ExtiInput;
use embassy_stm32::gpio::{Input, Level, Output, OutputType, Pull, Speed};
use embassy_stm32::i2c::{Config as I2cConfig, I2c};
use embassy_stm32::rcc::*;
use embassy_stm32::timer::low_level::CountingMode;
use embassy_stm32::timer::qei::{Qei, QeiPin};
use embassy_stm32::timer::simple_pwm::{PwmPin, SimplePwm};
use embassy_stm32::usart::{Config as UartConfig, Uart};
use embassy_stm32::{bind_interrupts, peripherals, Config};
use embassy_sync::mutex::Mutex;
use embassy_time::{Duration, Instant, Timer};
use panic_probe as _;

use nitride_firmware::board;
use nitride_firmware::control::dac_cc::CcDac;
use nitride_firmware::control::dac_cv::CvDac;
use nitride_firmware::control::supply::SupplyController;
use nitride_firmware::control::sweep::SweepController;
use nitride_firmware::drivers::tps26750::Tps26750;
use nitride_firmware::eeprom_workflow::{EepromWorkflow, WorkflowState};
use nitride_firmware::hal::bootloader;
use nitride_firmware::hal::converter_enable::ConverterEnable;
use nitride_firmware::pd::manager::PdManager;
use nitride_firmware::runtime::{APP_STATE, I2C_PD_BUS, I2C_UI_BUS};
use nitride_firmware::sense::adc_sense::{AdcSense, TelemetryFilter};
use nitride_firmware::sense::ina_sense::InaSense;
use nitride_firmware::service::{self, service_uart_task};
use nitride_firmware::state::{AppState, EepromUiSnapshot, MenuScreen};
use nitride_firmware::ui::input::InputHandler;
use nitride_firmware::ui::led::led_task;
use nitride_firmware::ui::menu::apply_input;
use nitride_firmware::ui::task::ui_task;

bind_interrupts!(struct Irqs {
    I2C1_EV => embassy_stm32::i2c::EventInterruptHandler<peripherals::I2C1>;
    I2C1_ER => embassy_stm32::i2c::ErrorInterruptHandler<peripherals::I2C1>;
    I2C3_EV => embassy_stm32::i2c::EventInterruptHandler<peripherals::I2C3>;
    I2C3_ER => embassy_stm32::i2c::ErrorInterruptHandler<peripherals::I2C3>;
    USART3 => embassy_stm32::usart::InterruptHandler<peripherals::USART3>;
});

/// Copy the workflow's display-facing fields into the shared state so the UI
/// task can render them without ever touching the workflow itself.
fn sync_eeprom_ui(app: &mut AppState, workflow: &EepromWorkflow) {
    app.eeprom_ui = EepromUiSnapshot {
        title: workflow.title(),
        message: workflow.message(),
        progress_percent: workflow.progress_percent(),
        busy: workflow.state == WorkflowState::Flashing,
        failed: workflow.state == WorkflowState::Error,
    };
}

#[embassy_executor::main]
async fn main(spawner: Spawner) {
    // Service mode, handoff leg: a previous boot recorded a request in `.uninit`
    // RAM and reset. Take it here — before the executor starts or any peripheral
    // is touched — so the ROM bootloader is entered from a pristine machine
    // state. Diverges.
    //
    // Diagnostics: the raw marker words, a count of valid requests consumed
    // since power-on, the reset-cause flags read before anything can clear
    // them, and the ROM bootloader's vector words. Together these split
    // "marker never written" from "marker consumed then jump failed".
    let csr_early = unsafe { core::ptr::read_volatile(0x4002_1094 as *const u32) };
    let (service_pending, marker_magic, marker_inv, jump_count) = bootloader::take_request_diag();
    let rom_sp = unsafe { core::ptr::read_volatile(0x1FFF_0000 as *const u32) };
    let rom_pc = unsafe { core::ptr::read_volatile(0x1FFF_0004 as *const u32) };
    if service_pending {
        defmt::info!("service mode: entering ROM bootloader");
        bootloader::jump_to_system_bootloader();
    }

    let mut config = Config::default();
    config.rcc.mux.adc12sel = mux::Adcsel::SYS;
    config.rcc.mux.adc345sel = mux::Adcsel::SYS;

    let p = embassy_stm32::init(config);
    defmt::info!("boot: clocks up");

    // VREF+ is hard-tied to +3V3 on this board, so the ADC/DAC reference is the
    // 3.3 V rail and the internal VREFBUF must NOT drive the pin. Leave VREFBUF
    // untouched in its reset state (external-reference mode: ENVR=0, HIZ=1) —
    // that is the correct configuration for this board and, unlike
    // `VoltageReferenceBuffer::new(..)` with `Hiz::HIGH_Z`/`CONNECTED`, it has
    // no `while VRR { }` wait loop in it. See `board::DAC_VREF_MV`.
    // NOTE: do not re-enable VREFBUF here — if VRR reads high at that point the
    // embassy init loop never exits and the firmware hangs before the OLED is
    // ever initialised.

    let mut dac_cv: DacCh1<'_, embassy_stm32::peripherals::DAC1, embassy_stm32::mode::Blocking> =
        DacChannel::new_blocking(p.DAC1, p.PA4);
    let mut dac_cc: DacCh1<'_, embassy_stm32::peripherals::DAC2, embassy_stm32::mode::Blocking> =
        DacChannel::new_blocking(p.DAC2, p.PA6);
    // The CV DAC is inverted: full-scale code = minimum output. Park it there
    // before anything else can enable the converter.
    dac_cv.set(Value::Bit12Right(board::DAC_MAX_CODE));
    dac_cc.set(Value::Bit12Right(0));
    defmt::info!("boot: dac parked");

    let mut adc1 = Adc::new(p.ADC1);
    adc1.set_resolution(Resolution::BITS12);
    adc1.set_sample_time(SampleTime::CYCLES640_5);
    let mut adc2 = Adc::new(p.ADC2);
    adc2.set_resolution(Resolution::BITS12);
    adc2.set_sample_time(SampleTime::CYCLES47_5);
    let mut adc5 = Adc::new(p.ADC5);
    adc5.set_resolution(Resolution::BITS12);
    adc5.set_sample_time(SampleTime::CYCLES47_5);

    let mut pin_vout = p.PA0;
    let mut pin_temp_conv = p.PA1;
    let mut pin_isense = p.PA3;
    let mut pin_vbus = p.PA7;
    let mut pin_temp_in = p.PA9;

    defmt::timestamp!("{=u64:us}", { embassy_time::Instant::now().as_micros() });

    let mut conv_en = ConverterEnable::new(Output::new(
        p.PA11,
        if board::CONVERTER_DISABLE_ACTIVE_HIGH {
            Level::High
        } else {
            Level::Low
        },
        Speed::Low,
    ));
    conv_en.set_enabled(false);

    let btn1 = Input::new(p.PB9, Pull::Up);
    let btn2 = Input::new(p.PB10, Pull::Up);
    let btn3 = Input::new(p.PB11, Pull::Up);
    let enc_btn = Input::new(p.PB4, Pull::Up);

    // Service mode, trigger #2: BTN1 held through power-up. Deterministic and
    // needs no UART, so it doubles as the bring-up test for the handoff path.
    // The output is already parked (DACs and converter disable above), and the
    // subsequent boot consumes the request before this check, so it cannot loop.
    //
    // Confirm the level twice: a single early sample can catch a still-settling
    // pin or contact bounce, and this path resets the MCU.
    if board::SERVICE_BOOT_HOLD {
        Timer::after(Duration::from_millis(50)).await;
        if btn1.is_low() {
            Timer::after(Duration::from_millis(200)).await;
            if btn1.is_low() {
                defmt::info!("service mode: BTN1 held at boot");
                bootloader::request_on_next_boot();
            }
        }
    }

    let qei = Qei::new(p.TIM4, QeiPin::new(p.PB6), QeiPin::new(p.PA12));
    let mut enc_last: u16 = qei.count();
    // Carries the leftover quadrature counts between polls so a detent split
    // across two 5 ms windows still produces exactly one `EncTurn` event.
    let mut enc_accum: i32 = 0;
    let mut pd_irq = ExtiInput::new(p.PB13, p.EXTI13, Pull::Up);

    // Status LED: D31 on PA15 (TIM2_CH1). Driven as hardware PWM so the pattern
    // engine in `ui::led` can dim the healthy heartbeat precisely and keep it
    // steady even while a blocking I2C timeout stalls the executor.
    let led_pwm = SimplePwm::new(
        p.TIM2,
        Some(PwmPin::new(p.PA15, OutputType::PushPull)),
        None,
        None,
        None,
        embassy_stm32::time::Hertz::hz(board::LED_PWM_HZ),
        CountingMode::EdgeAlignedUp,
    );
    let led_ch = led_pwm.split().ch1;

    // I2C configs are per-bus because the two buses need opposite timeout
    // behaviour.
    //
    // embassy's I2C waits in a *blocking* spin loop (`wait_af`/`wait_rxne`/...
    // call `timeout.check()`), AND its async DMA path wraps the transfer in that
    // same deadline. So a long timeout on a dead bus freezes the executor, while
    // a short timeout on the UI bus aborts OLED transactions that were simply
    // unlucky enough to be in flight while the main loop was blocked polling the
    // PD bus — which truncates `flush_partial` and leaves whole GDDRAM pages
    // unwritten (random speckle).
    //
    // UI bus (I2C3, OLED/EEPROM): generous. A healthy transfer is <1 ms; this
    // only has to outlast the main loop's worst-case PD poll.
    let mut i2c_ui_config = I2cConfig::default();
    i2c_ui_config.frequency = embassy_stm32::time::Hertz::khz(400);
    i2c_ui_config.timeout = Duration::from_millis(250);

    // PD bus (I2C1, TPS26750/INA228): short, so a missing or stuck PD controller
    // fails fast instead of freezing the executor (and the OLED) for a second.
    let mut i2c_pd_config = I2cConfig::default();
    i2c_pd_config.frequency = embassy_stm32::time::Hertz::khz(400);
    i2c_pd_config.timeout = Duration::from_millis(20);

    // UI bus (I2C3): SSD1306 OLED, plus the CAT24C512 config EEPROM when
    // JP8/JP9 are bridged.
    let i2c_ui = I2c::new(
        p.I2C3, p.PA8, p.PB5, Irqs, p.DMA1_CH3, p.DMA1_CH4, i2c_ui_config,
    );
    let ui_bus = I2C_UI_BUS.init(Mutex::new(i2c_ui));

    // PD bus (I2C1): TPS26750 USB-PD controller and INA228 input monitor.
    // rev2 routes these to PC4/PB7, an I2C pin pair no single peripheral can
    // drive, so SCL is bodged to PB8 and SDA stays on PB7.
    let i2c_pd = I2c::new(
        p.I2C1, p.PB8, p.PB7, Irqs, p.DMA1_CH1, p.DMA1_CH2, i2c_pd_config,
    );
    let pd_bus = I2C_PD_BUS.init(Mutex::new(i2c_pd));
    defmt::info!("boot: i2c up");

    // Service mode, trigger #1: the on-board FT234XD sits on USART3
    // (TX=PC10, RX=PC11) — the same port the ROM bootloader listens on. We only
    // receive here, watching for the AN3155 sync byte so that merely opening
    // the programmer hands the device over. DMA1_CH5/CH6 are the channels left
    // free by the two I2C buses.
    //
    // RX MUST be pulled up: with the FT234XD unpowered (USB detached) its TXD is
    // high-Z, and a floating RX generates framing/noise bytes that can include
    // the 0x7F sync value — which would park the output and reset into the ROM
    // bootloader on an otherwise normal power-up.
    let mut service_uart = if board::SERVICE_UART_AUTODETECT {
        let mut uart_config = UartConfig::default();
        uart_config.baudrate = board::SERVICE_UART_BAUD;
        uart_config.rx_pull = Pull::Up;
        match Uart::new(
            p.USART3,
            p.PC11,
            p.PC10,
            Irqs,
            p.DMA1_CH5,
            p.DMA1_CH6,
            uart_config,
        ) {
            Ok(uart) => Some(uart),
            Err(_) => {
                defmt::error!("service UART init failed; UART handoff disabled");
                None
            }
        }
    } else {
        None
    };
    defmt::info!(
        "boot: service uart {}",
        if service_uart.is_some() { "up" } else { "off" }
    );

    // Service-mode bring-up diagnostic: print the marker words, the request
    // counter, the reset-cause flags (captured at the top of main, before
    // anything can RMVF-clear them) and the ROM bootloader's vector words over
    // the FT234XD, where a plain terminal can read them with no probe attached
    // (and none possible: a live probe freezes every handoff reset with its
    // reset vector catch). Keep until service mode is bench-verified (§11).
    if let Some(uart) = service_uart.as_mut() {
        defmt::info!(
            "boot diag: csr={=u32:x} magic={=u32:x} inv={=u32:x} cnt={=u32} romsp={=u32:x} rompc={=u32:x}",
            csr_early,
            marker_magic,
            marker_inv,
            jump_count,
            rom_sp,
            rom_pc
        );
        let mut msg = [0u8; 128];
        let mut i = 0;
        put(&mut msg, &mut i, b"DIAG csr=");
        puth(&mut msg, &mut i, csr_early);
        put(&mut msg, &mut i, b" magic=");
        puth(&mut msg, &mut i, marker_magic);
        put(&mut msg, &mut i, b" inv=");
        puth(&mut msg, &mut i, marker_inv);
        put(&mut msg, &mut i, b" p=");
        put(&mut msg, &mut i, if service_pending { b"1" } else { b"0" });
        put(&mut msg, &mut i, b" cnt=");
        puth(&mut msg, &mut i, jump_count);
        put(&mut msg, &mut i, b" romsp=");
        puth(&mut msg, &mut i, rom_sp);
        put(&mut msg, &mut i, b" rompc=");
        puth(&mut msg, &mut i, rom_pc);
        put(&mut msg, &mut i, b"\r\n");
        if uart.write(&msg[..i]).await.is_err() {
            defmt::error!("boot diag uart write failed");
        }
    }

    let app = AppState::default();
    let app_state = APP_STATE.init(Mutex::new(app));

    let mut supply = SupplyController::new();
    let mut sweep = SweepController::new();
    let mut sense = AdcSense::new();
    let mut input = InputHandler::new();
    let mut tele_filter = TelemetryFilter::new();
    let mut pd_mgr = PdManager::new();
    let mut tps = Tps26750::new(board::TPS26750_ADDR);
    let mut ina = InaSense::new();
    let mut eeprom_workflow = EepromWorkflow::new();

    {
        let mut i2c = pd_bus.lock().await;
        let _ = ina.init(&mut i2c).await;
        // The TPS26750 loads its application firmware from EEPROM and is not
        // guaranteed to answer this early, so it is not probed here: PdManager
        // owns a presence watchdog that re-probes it until it responds.
    }
    defmt::info!("boot: ina init done");

    // The ISMON zero is a bench-calibrated constant (`board::ISENSE_ZERO_MV`),
    // deliberately NOT learned here: the LT8390A powers its ISMON buffer down
    // with the rest of the chip while EN/UVLO is low, so a sample taken with the
    // converter parked does not see the operating offset. Log what is in use.
    defmt::info!(
        "boot: isense zero = {} counts ({} mV), gain {} mV/A",
        sense.zero_raw(),
        board::ISENSE_ZERO_MV,
        board::ISENSE_MV_PER_A
    );

    // Converter-enable pin and the two open-loop maps, logged once so a bench
    // measurement can be checked against the exact numbers the firmware used.
    // The enable line is worth verifying on the board: the firmware drives PA11,
    // while the rev2 schematic routes the Q13 gate / EN/UVLO disable to PB1.
    // If the converter cannot actually be parked, that mismatch is why.
    defmt::info!(
        "boot: conv-disable pin PA11 (active_high={}), CV dac PA4, CC dac PA6",
        board::CONVERTER_DISABLE_ACTIVE_HIGH
    );
    defmt::info!(
        "boot: cv map: code0 -> {} mV, code{} -> {} mV (VREF {} mV, R19 {} R20 {} R36 {})",
        CvDac::vout_at_code_zero_mv(),
        board::DAC_MAX_CODE,
        CvDac::code_to_vout_mv(board::DAC_MAX_CODE),
        board::DAC_VREF_MV,
        board::CV_FB_TOP_OHM,
        board::CV_FB_BOTTOM_OHM,
        board::CV_SUM_OHM
    );
    defmt::info!(
        "boot: cc ctrl net R48={} R5={} R4={} VREF={} mV; bench CC offset {} mA; set {} mA -> code {} (ctrl {} mV); set {} mA -> code {} (ctrl {} mV); code0 ctrl {} mV (latchoff {})",
        board::CTRL_SERIES_OHM,
        board::CTRL_VREF_OHM,
        board::CTRL_GND_OHM,
        board::LT8390_VREF_MV,
        board::CC_CURRENT_OFFSET_MA,
        board::CC_SET_MIN_MA,
        CcDac::setpoint_to_code(board::CC_SET_MIN_MA),
        CcDac::ctrl_mv_for_code(CcDac::setpoint_to_code(board::CC_SET_MIN_MA)),
        board::CC_SET_MAX_MA,
        CcDac::setpoint_to_code(board::CC_SET_MAX_MA),
        CcDac::ctrl_mv_for_code(CcDac::setpoint_to_code(board::CC_SET_MAX_MA)),
        CcDac::ctrl_mv_for_code(0),
        board::LT8390_CTRL_LATCHOFF_MV
    );
    // The CC window is the part's, not the firmware's: report the settable range
    // next to what the chip can *sustain* and what it needs to cold-start. The
    // settable floor is deliberately low (see `board::CC_SET_MIN_MA`) because a
    // lower setpoint is the only route to a lower actual current.
    defmt::info!(
        "boot: cc range settable {}..{} mA; sustain {}..{} mA; datasheet cold-start {} mA (R18={} mOhm, ISMON {} mV/A); ctrl {}..{} mV",
        board::CC_SET_MIN_MA,
        board::CC_SET_MAX_MA,
        board::CC_MIN_MA,
        board::CC_MAX_MA,
        board::CC_START_MIN_MA,
        board::ISENSE_SHUNT_MOHM,
        board::ISENSE_MV_PER_A,
        board::LT8390_CTRL_LATCHOFF_MV,
        board::LT8390_CTRL_SAT_MV
    );
    defmt::info!(
        "boot: iout software trip margin {}%; supply snapshot every {} ms",
        board::IOUT_TRIP_MARGIN_PCT,
        board::SUPPLY_LOG_MS
    );

    spawner.spawn(led_task(app_state, led_ch)).unwrap();
    spawner.spawn(ui_task(app_state, ui_bus)).unwrap();
    if let Some(uart) = service_uart {
        spawner.spawn(service_uart_task(uart)).unwrap();
    }

    let mut t_adc = Instant::now();
    let mut t_supply = Instant::now();
    let mut t_input = Instant::now();
    let mut t_pd = Instant::now();
    // Bring-up ISMON diagnostic cadence (see the `isense:` log below).
    let mut t_isense_log = Instant::now();
    // PD poll period. Backed off to a slow retry while the bus is not answering.
    let mut pd_period = Duration::from_millis(board::INA228_POLL_MS);

    loop {
        // Service mode, handoff leg: park the output, let it settle, then reset
        // with a request recorded so the next boot enters the ROM bootloader.
        // Reusing `supply.tick` keeps the inverted-CV and CC-zero behaviour in
        // one place; the APP_STATE lock is dropped before the settle delay.
        if service::SERVICE_REQUEST.swap(false, Ordering::SeqCst) {
            let was_enabled = {
                let mut app = app_state.lock().await;
                let was_enabled = app.supply.enabled;
                app.supply.enabled = false;
                supply.tick(&mut app, &mut dac_cv, &mut dac_cc, &mut conv_en);
                was_enabled
            };
            conv_en.set_enabled(false);
            defmt::info!("service mode: parking output before handoff");
            // The settle wait only buys something when the converter was actually
            // driving. Skipping it when the output was already parked cuts the
            // handoff to reset time (~2 ms), well inside the host tools' retry
            // window: stm32flash 0.7 resends 0x7F exactly once, 500 ms after the
            // first byte (TERMIOS_TIMEOUT_MS in serial_posix.c), then gives up.
            if was_enabled {
                Timer::after(Duration::from_millis(board::SERVICE_PARK_SETTLE_MS)).await;
            }
            bootloader::request_on_next_boot();
        }

        let now = Instant::now();

        if now.duration_since(t_input) >= Duration::from_millis(board::INPUT_POLL_MS) {
            t_input = now;
            let c = qei.count();
            enc_accum += (c.wrapping_sub(enc_last) as i16) as i32;
            enc_last = c;
            // Convert raw quadrature counts to detents. The remainder is kept so
            // a detent straddling two polls is not lost or double-counted.
            let detents = (enc_accum / board::ENCODER_COUNTS_PER_DETENT) as i16;
            enc_accum -= detents as i32 * board::ENCODER_COUNTS_PER_DETENT;
            input.poll(&btn1, &btn2, &btn3, &enc_btn, detents);
            if let Some(ev) = input.last_event {
                let mut app = app_state.lock().await;
                let previous_screen = app.ui.screen;
                if app.ui.screen == MenuScreen::EepromFlash {
                    eeprom_workflow.handle_input(ev);
                }
                apply_input(&mut app, ev);
                if previous_screen != app.ui.screen && app.ui.screen == MenuScreen::EepromFlash {
                    defmt::info!("Entered EEPROM flash screen");
                    sync_eeprom_ui(&mut app, &eeprom_workflow);
                }
            }
            input.clear_event();
        }
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

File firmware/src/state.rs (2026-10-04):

//! Shared runtime state between tasks.

use crate::board;
use crate::drivers::tps26750::SourceCapability;

/// Output stage operating mode: which control loop drives the converter.
#[derive(Clone, Copy, Debug, PartialEq, Eq)]
pub enum SupplyMode {
    Off,
    Cv,
    Cc,
}

/// Latched hardware fault. Set by [`crate::control::supply::SupplyController`];
/// cleared from the UI (BTN2 on the main screen).
#[derive(Clone, Copy, Debug, PartialEq, Eq)]
pub enum Fault {
    None,
    OverCurrent,
    OverVoltage,
    OverPower,
    OverTemp,
    /// Input-bus overcurrent from the INA228 (beyond the PD contract cap).
    InputOverCurrent,
    /// Input-bus overvoltage from the INA228.
    InputOverVoltage,
    // TODO(dead-code): reserved for a "user switched the output off" state, but the
    // UI toggles `SupplyState::enabled` directly instead of raising a fault. Never
    // constructed or matched anywhere.
    // UserOff,
}

impl Fault {
    /// Short display label for the OLED header, replacing the temperature badges
    /// while a fault is latched. Returns `None` when no fault prevents turn-on.
    pub fn label(self) -> Option<&'static str> {
        match self {
            Fault::None => None,
            Fault::OverCurrent => Some("OVERCURRENT"),
            Fault::OverVoltage => Some("OVERVOLTAGE"),
            Fault::OverPower => Some("OVERPOWER"),
            Fault::OverTemp => Some("OVERTEMP"),
            Fault::InputOverCurrent => Some("IN OCP"),
            Fault::InputOverVoltage => Some("IN OVP"),
        }
    }
}

/// USB-PD connection state machine, driven by [`crate::pd::manager::PdManager`].
#[derive(Clone, Copy, Debug, PartialEq, Eq)]
pub enum PdState {
    NoCable,
    Negotiating,
    ContractActive,
    // TODO(dead-code): no PD error path currently transitions into this state;
    // failures are only logged via defmt. Preserved for future error reporting.
    // Fault,
}

/// How the PD input rail is chosen: manually from the preset list, or
/// automatically from the output setpoint by [`crate::pd::auto_track`].
#[derive(Clone, Copy, Debug, PartialEq, Eq)]
pub enum PdMode {
    Manual,
    Auto,
}

/// Optimisation target for Auto-tracking PD.
#[derive(Clone, Copy, Debug, PartialEq, Eq)]
pub enum AutoPolicy {
    /// Stay outside the LT8390A 4-switch buck-boost region; fall back to the
    /// most capable rail only when no clean rail can supply the requested power.
    Efficiency,
    /// Always pick the rail that can deliver the most power, accepting 4-switch
    /// losses when the closest rail sits near Vout.
    Power,
}

/// Which LT8390A operating region a chosen rail is expected to produce.
#[derive(Clone, Copy, Debug, PartialEq, Eq)]
pub enum RailRegion {
    Buck,
    Boost,
    /// Efficiency-first policy had to fall back to a rail that does not clear
    /// the 4-switch band because the clean options could not supply the power.
    FallbackPower,
    Unavailable,
}

/// Why Auto-tracking could not produce a rail.
#[derive(Clone, Copy, Debug, PartialEq, Eq)]
pub enum PdAutoError {
    None,
    NoCable,
    NoRail,
}

/// PD rail-selection state shared with the UI.
#[derive(Clone, Copy, Debug, PartialEq, Eq)]
pub struct PdControl {
    pub mode: PdMode,
    pub policy: AutoPolicy,
    /// Rail currently requested (0 when none).
    pub target_mv: u32,
    pub region: RailRegion,
    pub error: PdAutoError,
    /// Set by the UI when the user changes the mode/preset/policy; the PD
    /// manager consumes it and renegotiates once.
    pub renegotiate_request: bool,
    /// One-shot "MAX" request: ignore the preset and ask for the highest rail the
    /// source offers (highest EPR PDO when EPR is available, else the highest SPR
    /// fixed PDO). Set by BTN2 in Manual mode; cleared once the manager plans it.
    pub max_request: bool,
}

impl Default for PdControl {
    fn default() -> Self {
        Self {
            mode: PdMode::Manual,
            policy: AutoPolicy::Efficiency,
            target_mv: 0,
            region: RailRegion::Unavailable,
            error: PdAutoError::NoCable,
            renegotiate_request: false,
            max_request: false,
        }
    }
}

/// USB-PD contract preset voltages in millivolts.
pub const PD_PRESET_VOLTAGES_MV: [u32; 6] = [12_000, 15_000, 20_000, 28_000, 36_000, 48_000];

#[derive(Clone, Copy, Debug, PartialEq, Eq)]
pub enum MenuScreen {
    Main,
    CcLimit,
    PdContract,
    Settings,
    EepromFlash,
}

#[derive(Clone, Copy, Debug, PartialEq, Eq)]
pub enum StepMode {
    Fine,
    Coarse,
}

/// One entry in the fullscreen CFG (Settings) list.
///
/// Adding an option is a four-step change: a new variant here, its label in
/// [`CfgItem::label`], an activation arm in `ui::menu::cfg_activate`, and the
/// element appended to [`CFG_ITEMS`].
///
/// `PD CONTRACT` is deliberately *not* an entry: that screen already has its own
/// stop in the BTN3 screen cycle (Main → I-LIM → PD → CFG → Main).
#[derive(Clone, Copy, Debug, PartialEq, Eq)]
pub enum CfgItem {
    EepromWrite,
    OutputSweep,
}

impl CfgItem {
    /// Display label for the CFG list row. Must stay within the 128 px panel at
    /// the list's x offset (21 characters max) — keep it short.
    pub fn label(self) -> &'static str {
        match self {
            CfgItem::EepromWrite => "EEPROM WRITE",
            CfgItem::OutputSweep => "OUTPUT V SWEEP",
        }
    }
}

/// Fullscreen CFG list contents, in display order.
pub const CFG_ITEMS: [CfgItem; 2] = [CfgItem::EepromWrite, CfgItem::OutputSweep];

/// Number of CFG rows that fit on screen at once; the list scrolls when
/// [`CFG_ITEMS`] grows past this.
pub const CFG_VISIBLE_ROWS: u8 = 4;

/// Lifecycle of the CFG "Output V sweep" option.
///
/// `Armed` is entered by selecting the option in the CFG list (which returns to
/// the Main screen); the encoder button confirms and starts the sweep. `Done`
/// is the parked end state, dismissed by any button press.
#[derive(Clone, Copy, Debug, PartialEq, Eq)]
pub enum SweepPhase {
    Off,
    Armed,
    Running,
    Done,
}

/// User-visible sweep state, mirrored from `control::sweep::SweepController`.
///
/// The controller owns the `Instant`-based step timing; only the phase, the
/// 0-based point index, and the one-shot start request live here so the UI task
/// can render progress from a plain `AppState` clone.
#[derive(Clone, Copy, Debug)]
pub struct SweepState {
    pub phase: SweepPhase,
    /// 0-based index of the point currently commanded (`Running`/`Done`).
    pub index: u8,
    /// Set by the UI when the encoder button confirms an armed sweep; consumed
    /// by the controller on the next supply tick.
    pub start_request: bool,
}

impl Default for SweepState {
    fn default() -> Self {
        Self {
            phase: SweepPhase::Off,
            index: 0,
            start_request: false,
        }
    }
}
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

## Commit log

2026-05-07 Fixed the library again
    [nitride-nano.kicad_pcb]
2026-05-07 Cleaned up the hierarchy
    [Converter.kicad_sch, LV-Supply.kicad_sch, MCU.kicad_sch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]
2026-05-08 inductor, output fets
    [Converter.kicad_sch, MCU.kicad_sch, nitride-nano.kicad_pcb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]
2026-05-09 Starting with layout, oled, encoder, xt90
    [Converter.kicad_sch, MCU.kicad_sch, Power-Sense.kicad_sch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]
2026-05-15 Finished layout
    [Converter.kicad_sch, LV-Supply.kicad_sch, MCU.kicad_sch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]
2026-05-19 Started routing
    [Converter.kicad_sch, LV-Supply.kicad_sch, MCU.kicad_sch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]
2026-05-21 Finished routing
    [Converter.kicad_sch, USB-PD.kicad_sch, USB.kicad_sch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]
2026-05-21 20A fuse
    [nitride-nano.kicad_pcb, nitride-nano.kicad_sch]
2026-05-24 fixed pinout of cpu, added freecad file for the housing
    [.step, Converter.kicad_sch, MCU.kicad_sch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]
2026-05-24 First housing revision
    [nano-housing.FCStd]
2026-05-25 Added 5V fan psu
    [LV-Supply.kicad_sch, MCU.kicad_sch, nano-housing.FCStd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]
2026-05-25 added pics
    [nano-housing.FCStd]
2026-05-27 Ordered Revision
    [nano-housing.FCStd, nitride-nano.kicad_pcb]
2026-05-31 Improved housing
    [nano-housing.FCStd, nitride-nano.blend, nitride-nano.kicad_pcb]
2026-06-06 changed mistakes on board, first firmware version
    [Converter.kicad_sch, MCU.kicad_sch, nano-housing-Front.step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]
2026-06-08 first working firmware
    [MCU.kicad_sch, nano-housing.FCStd]
2026-06-10 New UI
    [Converter.kicad_sch, Power-Sense.kicad_sch, temp_diff.txt]
2026-06-12 feat(ssd1306_ui): add power-on delay for SSD1306 display initialization
2026-06-13 Changed UI around a bit, and improved CV handling
    [Converter.kicad_sch, MCU.kicad_sch, USB-PD.kicad_sch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]
2026-06-13 reshuffeld folders
    [Converter.kicad_sch, LV-Supply.kicad_sch, MCU.kicad_sch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]
2026-06-27 temp sense works
    [nitride-nano.kicad_pcb]
2026-07-01 Working output current and voltage
2026-07-01 filtered values
2026-07-04 Implemented partial refresh
    [Converter.kicad_sch]
2026-08-18 Added ramping for CV mode again, Added error messages on OLED
    [nitride-nano.kicad_pcb]
2026-08-19 Revision 2; gate diodes, 5V into LT, i2c and uart lines fixed
    [Converter.kicad_sch, MCU.kicad_sch, USB-PD.kicad_sch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]
2026-08-20 Changed inductor to much better one
    [Converter.kicad_sch, MCU.kicad_sch, USB.kicad_sch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]
2026-08-21 Rev2 done, on to ordering
    [MCU.kicad_sch, nano-housing_R2.FCStd, nitride-nano.kicad_pcb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]
2026-08-31 Update input voltage range in specifications
2026-09-05 Added testpoints
    [Converter.kicad_sch, LV-Supply.kicad_sch, nitride-nano.kicad_pcb]
2026-09-05 BOM: R5 CTRL divider 124k -> 357k (fail-safe current limit default)
    - R5 biases the LT8390A CTRL pin: DAC-float default current limit drops
    from ~25A to ~5A, so a MCU brown-out/boot glitch can no longer demand
    the inductor's full rating. Full 0-50A range via CC DAC is unchanged.
    - LCSC/JLC fields: C36777 -> C27005 (UNI-ROYAL 0402WGF3573TCE, 357k 1%,
    same part as R19/R7)
    - Fit R3 = 100k (SS-VREF strap): short-circuit fault mode changes from
    hiccup to keep-running (done in KiCad)
    [Converter.kicad_sch, nitride-nano.kicad_pcb]
2026-09-08 Rev2 ordered
    [nitride-nano.kicad_pcb]
2026-09-08 Added .csv files back
    [bom.csv, designators.csv, positions.csv]
2026-09-13 firmware: fix PD interrupts, DAC reference, and safety/UI defects
    Bug-fix pass over the current firmware tree:
    PD / TPS26750
    - Clear latched INT_EVENT1 bits via INT_CLEAR1. INT_EVENT1 is read-only, so
    without this the plug/new-contract bits stayed set, kept the IRQ low and
    re-armed a renegotiate + output-park cycle on every 100 ms poll.
    - Bound the RX_SOURCE_CAPS parse (7 EPR PDOs indexed past the 53-byte buffer
    and panicked) and reject Battery/Variable PDOs instead of mis-decoding them.
    - Drop cached source caps on a plug event, only advance the requested rail when
    the request actually succeeded, and don't leave a renegotiate request armed
    when it cannot be acted on.
    Analog refe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
    [adc_sense.rs, board.rs, ina228.rs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]
2026-09-13 Messed up i2c again, fixed it
    [MCU.kicad_sch, lcsc_order_rev2_delta.csv, nitride-nano.kicad_pcb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]
2026-09-23 OLED Corruption fix, added UART Boot, DC-losses sim
    [MCU.kicad_sch, nitride-nano.kicad_pcb, nitride-nano.kicad_sch]
2026-09-25 EPR sort of works with some chargers
    [Converter.kicad_sch, nitride-nano.kicad_pcb, nitride-nano.kicad_sch]
2026-09-25 Efficiency on-screen now, and can sweep across the voltage scale and tell you minmax
2026-09-26 Added NMOS output switch (rated for 20A this time)
    [Converter.kicad_sch, MCU.kicad_sch, Power-Sense.kicad_sch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]
2026-09-26 EPR fully working
    [Converter.kicad_sch, nitride-nano.kicad_pcb]
2026-09-28 High current CC calibration
    [Converter.kicad_sch, MCU.kicad_sch, Power-Sense.kicad_sch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]
2026-10-01 Preliminary finish of Rev3
    [Converter.kicad_sch, MCU.kicad_sch, Power-Sense.kicad_sch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]
2026-10-03 Housing Rev3 added
    [Converter.kicad_sch, Power-Sense-Out.kicad_sch, nano-housing_R3.FCStd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]
2026-10-03 Changed cap clearance
    [bom.csv, designators.csv, nano-housing_R3.FCStd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]
2026-10-04 Fixed software OLED and UX
    [nano-housing_R3.FCStd]
2026-10-04 Fixed temp sens position so it doesnt use same space as inductor
    [nitride-nano.kicad_pcb, positions.csv]
2026-10-28 Rev3 software now running and working. Couple hardware bugs being fixed for R4
2026-10-29 Revise specifications and firmware details in README
    Updated specifications for input/output current and switching frequency. Revised input/output connector details and firmware description.
2026-10-29 Remove Revision 2 Changes section from README
    Removed detailed section on Revision 2 changes including power stage, control/MCU, connectivity, and firmware updates.

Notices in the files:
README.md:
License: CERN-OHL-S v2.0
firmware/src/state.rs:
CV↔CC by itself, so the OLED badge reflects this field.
